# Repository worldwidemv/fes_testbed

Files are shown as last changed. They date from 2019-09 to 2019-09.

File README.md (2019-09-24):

# Testbed for Functional Electrical Stimulation (FES) Devices

## Abstract
The FES Testbed is a specialised data acquisition system for measurements of transcutaneous electrical stimulation setups. The galvanic isolated measurement system transfers the high-resolution data of every detected
stimulation pulse via USB to a PC or Laptop. The stimulation pulse can use one of the 3 included skin replacement
models or can be forwarded to standard electrodes, allowing to record a normal FES application. Modular
postprocessing MATLAB functions round up the FES Testbed. These functions handle the data conversion, pulse
detection, gathering of statistics, data management and data visualisation. A MATLAB GUI for efficient pulse
examination completes the FES Testbed.

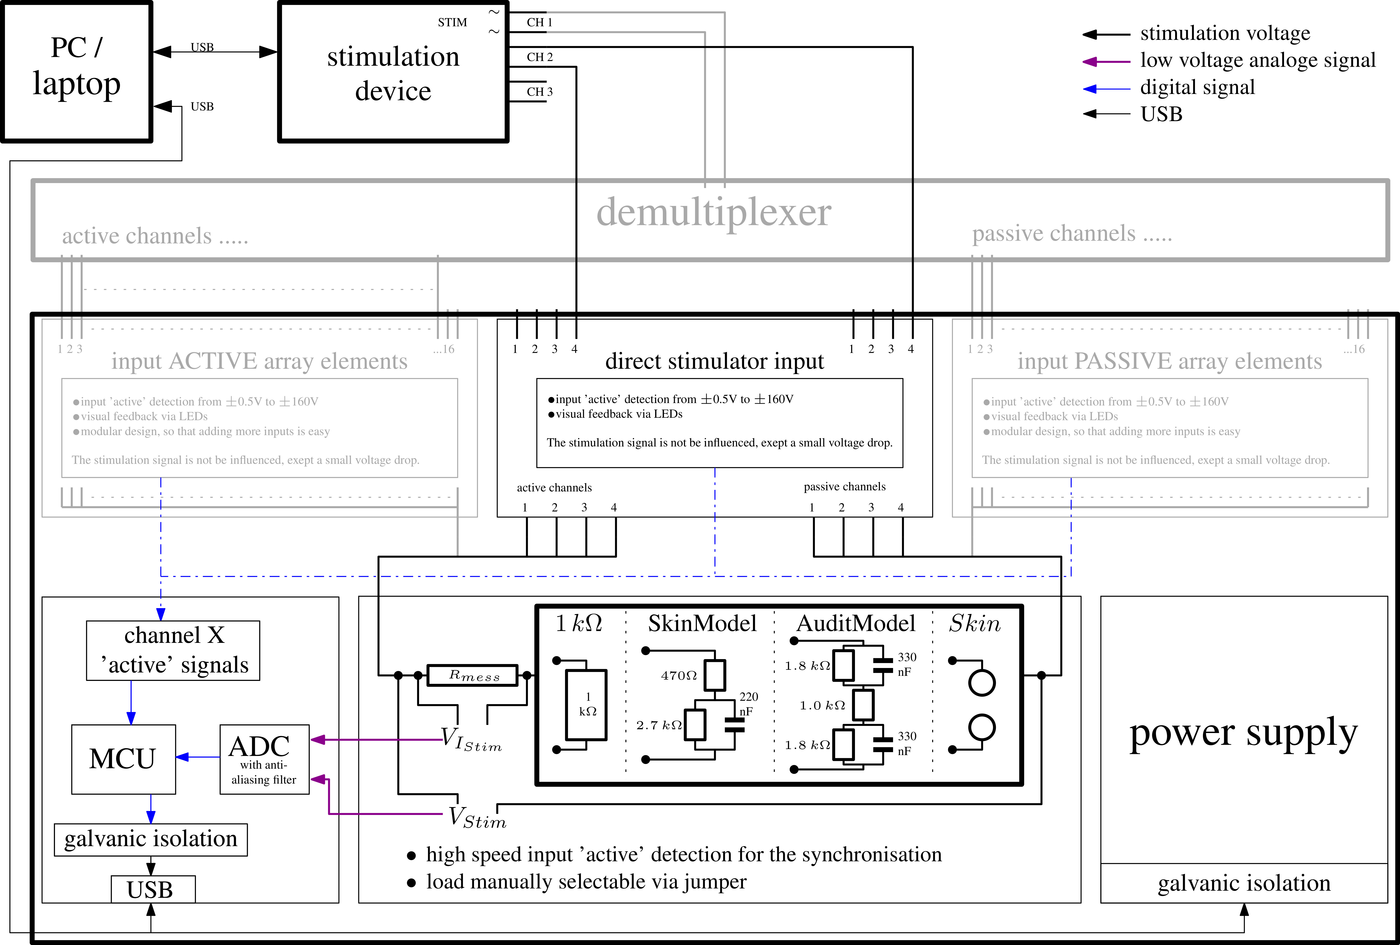
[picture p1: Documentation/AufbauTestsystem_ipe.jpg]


<p>
<a href="./Documentation/Vienna_FESWS_2019_FES_Testbed__Paper.pdf">More Information ...</a>
</p>

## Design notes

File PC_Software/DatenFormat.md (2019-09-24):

# Data Format of the Testbed Standalone Programm

## Version 2
* File Header -> 24 bytes
    * '%%TESTBED DATA\n' -> 14 bytes
    * header[14] = TESTBED_DATA_VERSION;
    * header[15] = TESTBED_DATA_TYPE_STIM_STRUCTS;
    * header[16] = 10; // new line
    * header[17] = (uint8_t)((sampleFrequency >>  0) & 0xFF);
    * header[18] = (uint8_t)((sampleFrequency >>  8) & 0xFF);
    * header[19] = (uint8_t)((sampleFrequency >> 16) & 0xFF);
    * header[20] = (uint8_t)((sampleFrequency >> 24) & 0xFF);

* STIM Puls Header
    * Start Bytes '###' -> 3 bytes
    * uint16_t numberOfSamples -> 2 bytes
    * uint8_t  pulseNotComplete -> 1 byte
    * uint8_t  dataWasOverriden -> 1 byte
    * uint8_t  activeStimChannels -> 1 Bytes; positive und negativ
    * uint8_t  activeDemuxChannels_positiv[16] -> 16 Bytes
    * uint8_t  activeDemuxChannels_negativ[16] -> 16 Bytes

* STIM Pulse Data
    * uint64_t sampleNumber -> 4*numberOfSamples Bytes
    * int16_t stimCurrent -> 2*numberOfSamples Bytes; 
    * int16_t stimVoltage -> 2*numberOfSamples Bytes;

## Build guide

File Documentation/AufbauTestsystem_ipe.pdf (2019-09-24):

# stimulation

device STIM | ∼ ∼
CH 1 Rmess VStim VIStim | 1 kΩ | SkinModel | AuditModel 1

kΩ

1.8 kΩ

1.8 kΩ

1.0 kΩ

330
nF

330
nF

220

nF 470Ω 2.7 kΩ

•input ’active’ detection from ±0.5V to ±160V
•visual feedback via LEDs
•modular design, so that adding more inputs is easy
The stimulation signal is not be influenced, exept a small voltage drop. 1 2 3 | ...16 input ACTIVE array elements | 1 2 3

# input PASSIVE array elements

•input ’active’ detection from ±0.5V to ±160V
•visual feedback via LEDs
The stimulation signal is not be influenced, exept a small voltage drop. 1 | 2 | 3
direct stimulator input active channels | passive channels 1 | 2 | 3 | 4 | 1 | 2 | 3 | 4

# - high speed input ’active’ detection for the synchronisation

- load manually selectable via jumper MCU | with anti-

# aliasing filter USB galvanic isolation

# channel X

’active’ signals | power supply demultiplexer CH 3 CH 2 active channels ..... | passive channels ..... PC / laptop | USB USB | 4 | 1 | 2 | 3 | 4

•input ’active’ detection from ±0.5V to ±160V •visual feedback via LEDs
•modular design, so that adding more inputs is easy
The stimulation signal is not be influenced, exept a small voltage drop. ...16 galvanic isolation MCU | ADC USB galvanic isolation

# channel X

’active’ signals | Skin

# stimulation voltage low voltage analoge signal digital signal USB

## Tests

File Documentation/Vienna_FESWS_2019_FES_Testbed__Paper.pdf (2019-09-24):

## FES Testbed for Multi-Channel Transcutaneous Stimulation Systems

Valtin M.¹
, Schauer T.

1

1Control Systems Group, Technische Universität Berlin, Germany

Abstract: Troubleshooting advanced FES applications or stimulation devices by measuring the stimulation current and voltage over several minutes is often not possible because of the limited memory available in standard oscilloscopes. The developed FES Testbed, a specialised data acquisition system for transcutaneous electrical stimulation, enables such measurements. The galvanic isolated measurement system transfers the high-resolution data of every detected stimulation pulse via USB to a PC or Laptop. The stimulation pulse can use one of the 3 included skin replacement models or can be forwarded to standard electrodes, allowing to record a normal FES application. Modular postprocessing MATLAB functions round up the FES Testbed. These functions handle the data conversion, pulse detection, gathering of statistics, data management and data visualisation. A MATLAB GUI for efficient pulse examination completes the FES Testbed.

Keywords: Stimulation Device, FES, Current Measurement, Data Acquisition, Skin Model

Introduction

Research involving functional transcutaneous electrical stimulation often includes some kind of control over the electrical stimulation. This may include the timing of the stimulation and/or the stimulation intensity, often based on sensor data [1]. Prominent examples of this structure are the FES based drop-foot correction [2] and the rehabilitation of the upper extremities, e.g. the hand [3]. In both cases, complex stimulation patterns are generated based on real-time sensor data. Monitoring and validating these stimulation patterns is often not easily possible, because the necessary measurement equipment is to large, to expensive, or to difficult to operate outside a lab environment.
Traditionally, the generated stimulation pulses are measured with an oscilloscope or with a data acquisition card for the PC. With a little bit of additional hardware, the stimulation voltage, as well as the stimulation current can be measured with these systems. Both methods usually use grid powered devices with no galvanic isolation, so the electrical safety of the whole setup must be kept in mind to protect the devices or the subject. While oscilloscope measurements are great for real-time feedback, they cannot be used for long term evaluation (e.g. several minutes) or tracking of randomly occurring stimulation errors, because of the limited amount of memory available.
PC based data acquisition systems do not have this limitation, however, these, often stationary systems, are generally less practical because of the costs, system size and complexity. Data acquisition systems also require elaborate postprocessing to go through the millions of samples to extract the short stimulation pulses and convert the integer raw-data samples into ampere/volt.

The presented FES Testbed is a specialised data acquisition system for transcutaneous electric stimulation, enabling researchers to check and validate the safety and functionality of their advanced FES applications.

The second application of the FES Testbed is the validation and comparison of different stimulators and support of the development of new stimulation devices. Since the various stimulators used in FES research all generate an electrical pulse, suitable to trigger a muscle contraction, the subtle and not so subtle differences, like symmetric and asymmetric biphasic pulses, are often neglected, conveying the idea that every stimulation pulse form is equally effective and can be easily exchanged. With the FES Testbed, the high-resolution voltage and current wave forms of multiple stimulation pulses can be recorded and compared. Additionally, multiple realistic loads included in the FES Testbed simulate the electrode-skin interface and allow comparing different stimulators under the exact same load conditions.

Material and Methods

The FES Testbed consists of three individual parts:
- a small data acquisition system, specialised for FES,
- a PC based data recorder program,
- and MATLAB (MathWorks Inc., USA) postprocessing scripts for efficient evaluation of the recorded stimulation pulses.
The FES data acquisition system is controlled by the PC data recorder, which saves the raw data for postprocessing by the MATLAB scripts.

FES Data Acquisition System

Figure 1 depicts the basic structure of the whole system, with the PC or Laptop controlling the FES data acquisition system and the stimulation device. An optional demultiplexer, as well as the modules for additional input channels, are shown in grey.

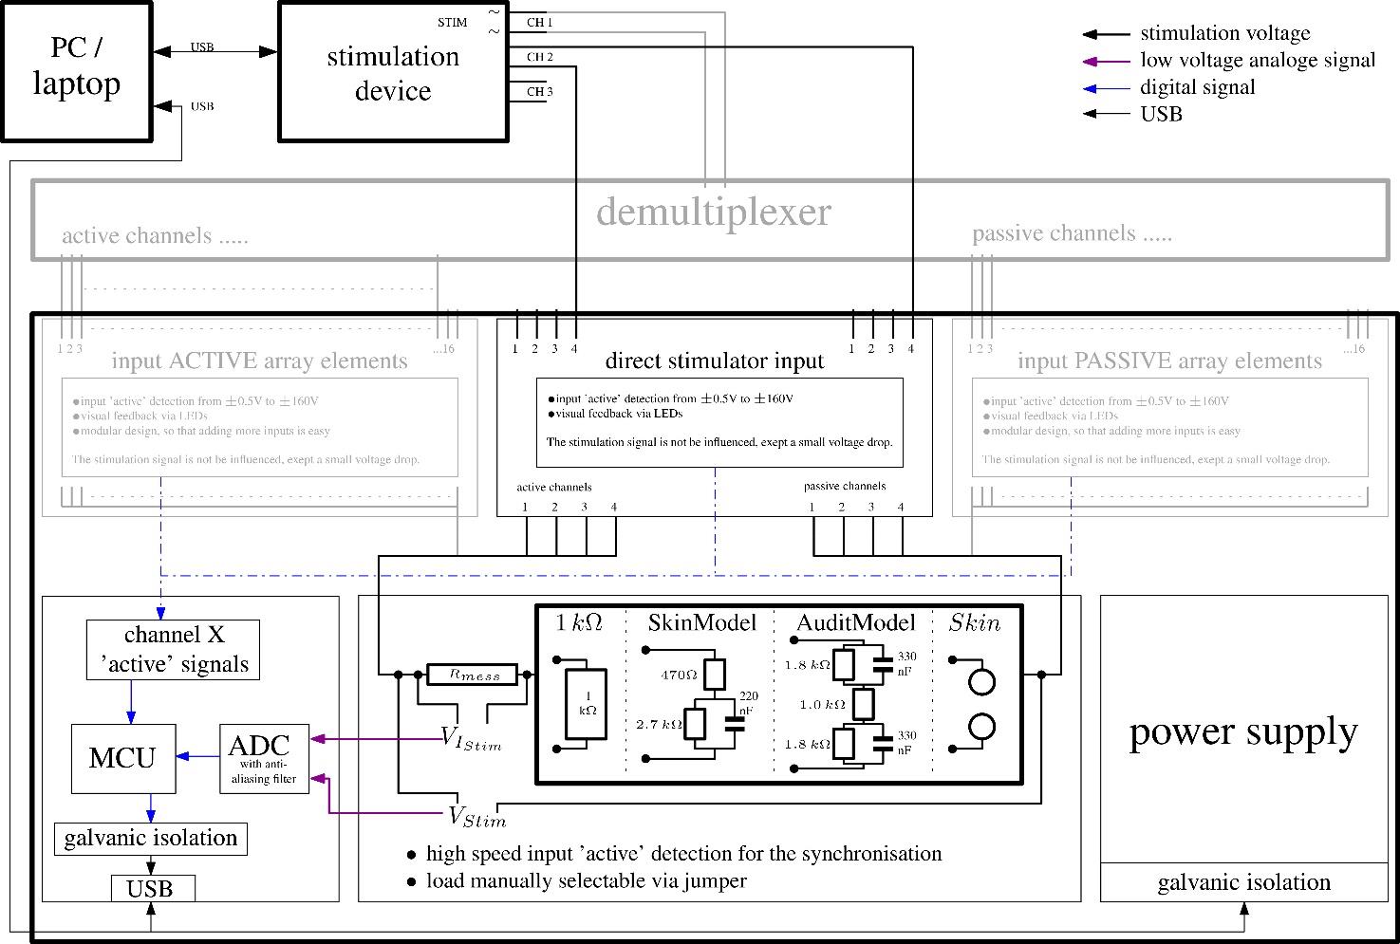
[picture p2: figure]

All devices are connected via USB to the PC, which also supplies the power for the data acquisition system. The power supply, as well as the USB communication channel, are galvanically isolated from the PC, to protect the PC from the high stimulation voltage and to protect against any ground loops, in case the FES Testbed is connected to a person. The power supply uses isolated DC/DC modules with at least 5.2kV isolation voltage (MEJ2 series, Murata, Japan). For the communication channel, the USB isolation IC ADUM4160BRWZ (Analog Devices Inc., USA) is used.
The FES Testbed supports 4 stimulation channels directly and up to 96 additional channels with optional extension modules, e.g. if a demultiplexer for electrode arrays needs to be tested. However, only one of these input channels can be active at a time. So, the stimulator must have a multiplexed current source, if this feature is used. The input stage is identical for every input channel and consists of a 'stimulation active' detection, which determines which stimulation channel is used. This is realised with an opto-coupler, which is driven directly by the stimulation current. An opto-coupler is used, because the stimulation current is not altered and because the resulting digital signal voltage is isolated from the stimulation voltage. Each input stage also has visual feedback of the stimulation pulse using LEDs.
After the input stage, all channels are connected to one single stimulation channel, which is routed to the current measurement resistor Rmess and the selected load.

Four via jumper selectable loads are included:
- a 1kΩ load for simple tests and comparison with oscilloscope measurements (1kΩ),
- a simplified linear skin model [4] (SkinModel),
- a model of the electrode interface according to test specification 09-01 03/2007 MDS-Hi (AuditModel),
- and a connector for standard stimulation cables (Skin). The voltage drop over the measurement resistor Rmess and the voltage over the load are measured with a two channel, 16-bit analogue to digital converter (ADC) MAX11198 (Maxim Integrated Inc., USA). The ADC’s sampling rate can go up to 2 MSample/s and is controlled via an external clock signal. The ADC features a dual serial peripheral interface (SPI), with one SPI output channel for each ADC channel and a maximum SPI clock frequency of 50MHz. However, it is not possible, to use two traditional SPIs, since only one SPI clock input is available. Therefore, one SPI interface was used in the master configuration to drive the SPI clock, accompanied by a second SPI interface in slave configuration, using the SPI clock generated by the SPI master. This allows the microcontroller (MCU) to utilise the direct memory access (DMA) unit for the data transfer, significantly reducing the MCU workload. The data transfer is triggered by the same MCU timer, which generates the ADC’s clock, guaranteeing a valid data transfer after the ADC’s data registers were updated.
The ADCs sampling rate was chosen to 1 MSample/s. This is because the stimulation pulse has a time resolution

Figure 1: Overview of the FES Testbed, including the structure of the data acquisition system.

of 1µs or greater. Passive first order anti-aliasing filters with ~500 kHz cut-off frequency are included in the signal preconditioning circuitry, before the ADC.
An | ARM© | based | microcontroller | (STM32L433,
STMicroelectronics, Netherlands) was used to receive the SPI data, as well as the USB data. Because of the embedded USB 2.0 module, supporting 12 MBit/s, no USB to serial converter is needed. Since the highest data rate supported by the USB isolator IC is USB 2.0 'Full Speed' with 12 MBit/s, no faster external USB solutions are viable. Because the data rate is limited, the MCU needs to pre-process the continuous ADC data stream to identify the stimulation pulses, so that only the parts containing stimulation pulses are sent to the PC. This is done via configurable thresholds for the measured stimulation current and voltage. The data is buffered using the MCU’s RAM and send out in packages of two times 1000 samples. A 32-bit sample counter is sent with every package to enable the PC program to reconstruct the correct time vector of the stimulation pulses.

Data Recorder Program

The FES data acquisition system is controlled from a Linux PC via the Data Recorder program. This program initiates the measurement, receives, and saves the data excerpt. The following parameters are set during initialisation of the FES data acquisition system: data type to send (only the stimulation pulses or a continuous down-sampled data stream), sample rate divider, search width (number of samples to skip if detecting a stimulation pulse), detection thresholds, and if a demultiplexer is used. This initial setup is also stored in the custom binary format, used to store the measurement data. This allows the postprocessing script the correct conversion of the raw data stored. The data format is optimised for read-in speed and size, so only the time as a float value, and the raw 16-bit integer values for current and voltage are stored as vectors for one pulse. Therefore, before each pulse section, a small header is added with the meta information about the pulse, like the number of samples, the active stimulation channel(s), and so on. Figure 2 depicts the general structure of the resulting data file.

Figure 2: File structure of the custom binary data file.

The data about each stimulation pulse is also available via TCP/IP connection, to allow real-time visualisation and monitoring by other programs or scripts.

MATLAB based Postprocessing

Since the PC program only saves the raw data, the bulk of the conversion and postprocessing is done by modular MATLAB functions. A first function reads the binary file and converts the 16-bit raw data into volt and milliampere. The function also creates a MATLAB structure (struct) for the data, with an array of structs containing the stimulation pulse data. The meta data for each pulse is also taken over from the raw data and reformatted for easy access in MATLAB. A second function is used to search for the expected pulse form, e.g. symmetric bi-phasic, and aligns the found pulse data, so that the pulses can be automatically compared and analysed. This function also collects various stats like the current or pulse width for later use. This step also saves all pulses which do not follow the expected form, so that they can be inspected manually later. Custom functions which, e.g., identify skin-model parameters can now be used on these normalised datasets.
Plotting these datasets is also very easy. A custom MATLAB GUI was developed to efficiently view the results and compare various stimulation pulses. This GUI has an overview function, where the complete, down-sampled vector of the stimulation current is plotted over time in subplot 1. One stimulation pulse, highlighted in the overview plot, can be selected via slider and shown in subplot 2. If the overview is disabled, subplot 1 is going to display the stimulation current of N pulses, while subplot 2 is going to display the stimulation voltage for these N pulses. N, the number of pulses to display, is configurable in the GUI and includes the selected pulse as well as the previous N-1 pulses.
The MATLAB data structure containing all this information can be saved directly from the GUI with varying degree of raw data included, significantly reducing the needed file size.

Results

The FES data acquisition device with an extension module for additional 16 input channels is depicted in Figure 3.

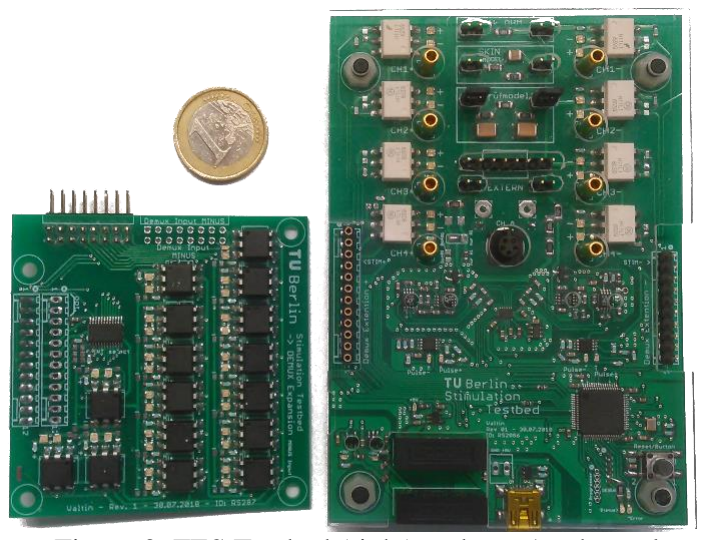
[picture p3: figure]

Figure 3: FES Testbed (right) and one 16 channel extension module (left).

The small size (115 mm × 80 mm × 20 mm) and the single USB connection makes the device very portable and easy to operate.
The quality of the measured data is also very good for such a simple system. The time resolution of 1 µs is sufficient to capture even very short spikes and sharp transients. The 16-bit ADC resolution provides a theoretical resolution for the stimulation current of ~5 µA and enables low noise measurements from 0 mA up to ±150 mA without the need to adjust the measurement range. Figure 4 shows the stimulation voltage of a stimulator with adaptive high voltage generation [5] over the AuditModel, measured with the FES Testbed and with a 10-bit oscilloscope (Rode&Schwarz, RTM3004).

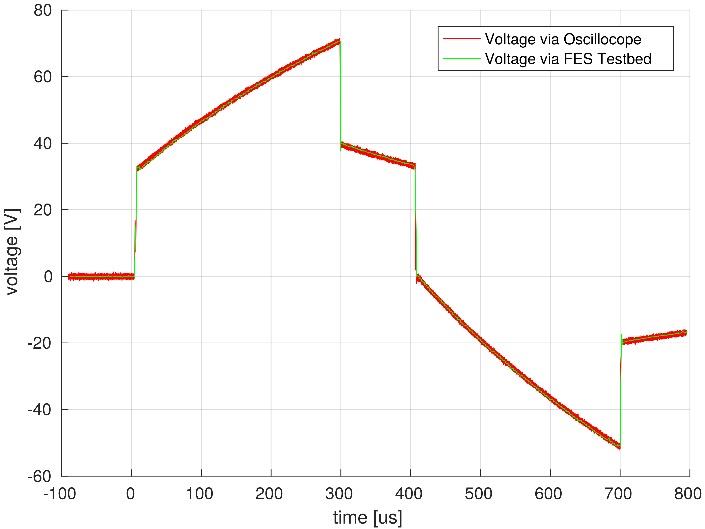
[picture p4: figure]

Figure 4: Stimulation voltage over the electrode interface model, measured with the FES Testbed (green) and an oscilloscope (red) (cur=25 mA; pw=300 µs).

Figure 5 shows the MATLAB GUI for a data set of 60 seconds or 1200 pulses (cur=25 mA; pw=300 µs) with 50 ms between each pulse. In the lower part of the GUI, stimulation current (blue) and voltage (orange) is displayed as well as the automatically detected boundaries of the different parts of the pulse (red). The file size of this one-minute long data set is about 34.9 MB. The postprocessing is also very fast, taking less than one second for the 1-minute data set, which would make the postprocessing real-time capable.

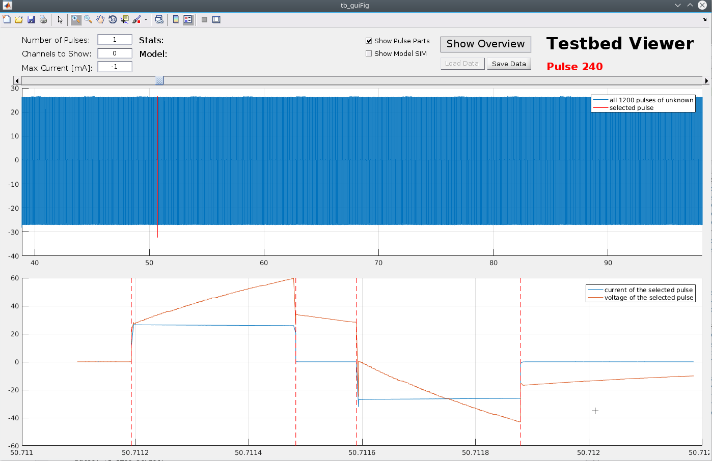
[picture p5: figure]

Figure 5: FES Testbed GUI showing the overview with 1200 pulses and the details for pulse 240.

The only limitation of the FES data acquisition system is its inability to continuously stream the data with 1 MSample/s. However, the need for galvanic isolation requires this compromise. On the other hand, most of this data would be discarded anyway, since the relevant stimulation pulse is very short, compared to the stimulation period. The MCUs buffer capability of 2 ms (sampling rate 1 MSample/s) should be sufficient for most applications, even where multiple pulses are used. In all other cases, reducing the sample rate will increase the pulse length the buffer can hold accordingly.

Conclusions

We developed a testbed aimed at supporting developers of intelligent stimulators, researcher who study electrical stimulation and its effects on the body, and clinicians who want to check and monitor the stimulation pulses generated by their FES application, over the entire treatment session.
The FES Testbed gives new insight into the physical effects of electrical stimulation and may aid in the development of smarter stimulators, which e.g., warn the health care professional if the stimulation voltage saturates because of poor electrode-skin contact. The FES Testbed could also prove invaluable for the validation and accreditation of complex stimulation systems.
Future work will focus on the automatic parameter identification for various skin models [6] [7] and the change of these parameters over stimulation intensity and time.

References

[1] T. Schauer: Sensing motion and muscle activity for feedback control of functional electrical stimulation: Ten years of experience in Berlin, Annual Reviews in Control, vol. 44, pp. 355-374, 2017
[2] T. Seel, C. Werner, T. Schauer: The Adaptive Drop Foot Stimulator – Multivariable Learning Control of Foot Pitch and Roll Motion in Paretic Gait, Medical Engineering Physics, vol. 38, pp. 1205-1213, 2016
[3] C. Salchow-Hömmen, T. Thomas et. al.: Automatic control of grasping strength for functional electrical stimulation in forearm movements via electrode arrays, at-Autom, vol. 66, pp. 1027-1036, 2018
[4] A. Boxtel: Skin resistance during square-wave electrical pulses of 1 to 10 mA, Medical & biological engineering & computing, vol. 15, pp. 679-687, 1977
[5] C. Wiesener: Current-Controlled Stimulator with Variable High Voltage Generation, Submitted to Proc. of the 13th Vienna International Workshop on Functional Electrical Stimulation, 2019
[6] J. L. Vargas Luna et. al.: Dynamic impedance model of the skin-electrode interface for transcutaneous electrical stimulation, PloS one, 2015 10(5), e0125609
[7] S. Dorgan, R. Reilly: Model for human skin impedance during surface functional neuromuscular stimulation, IEEE transactions on rehabilitation engineering, vol. 7, pp. 341-348, 1999

Author’s Address

Markus Valtin
Technische Universität Berlin Sekretariat EN 11
Einsteinufer 17
D-10587 Berlin, Germany
markus.valtin@campus.tu-berlin.de http://www.control.tu-berlin.de

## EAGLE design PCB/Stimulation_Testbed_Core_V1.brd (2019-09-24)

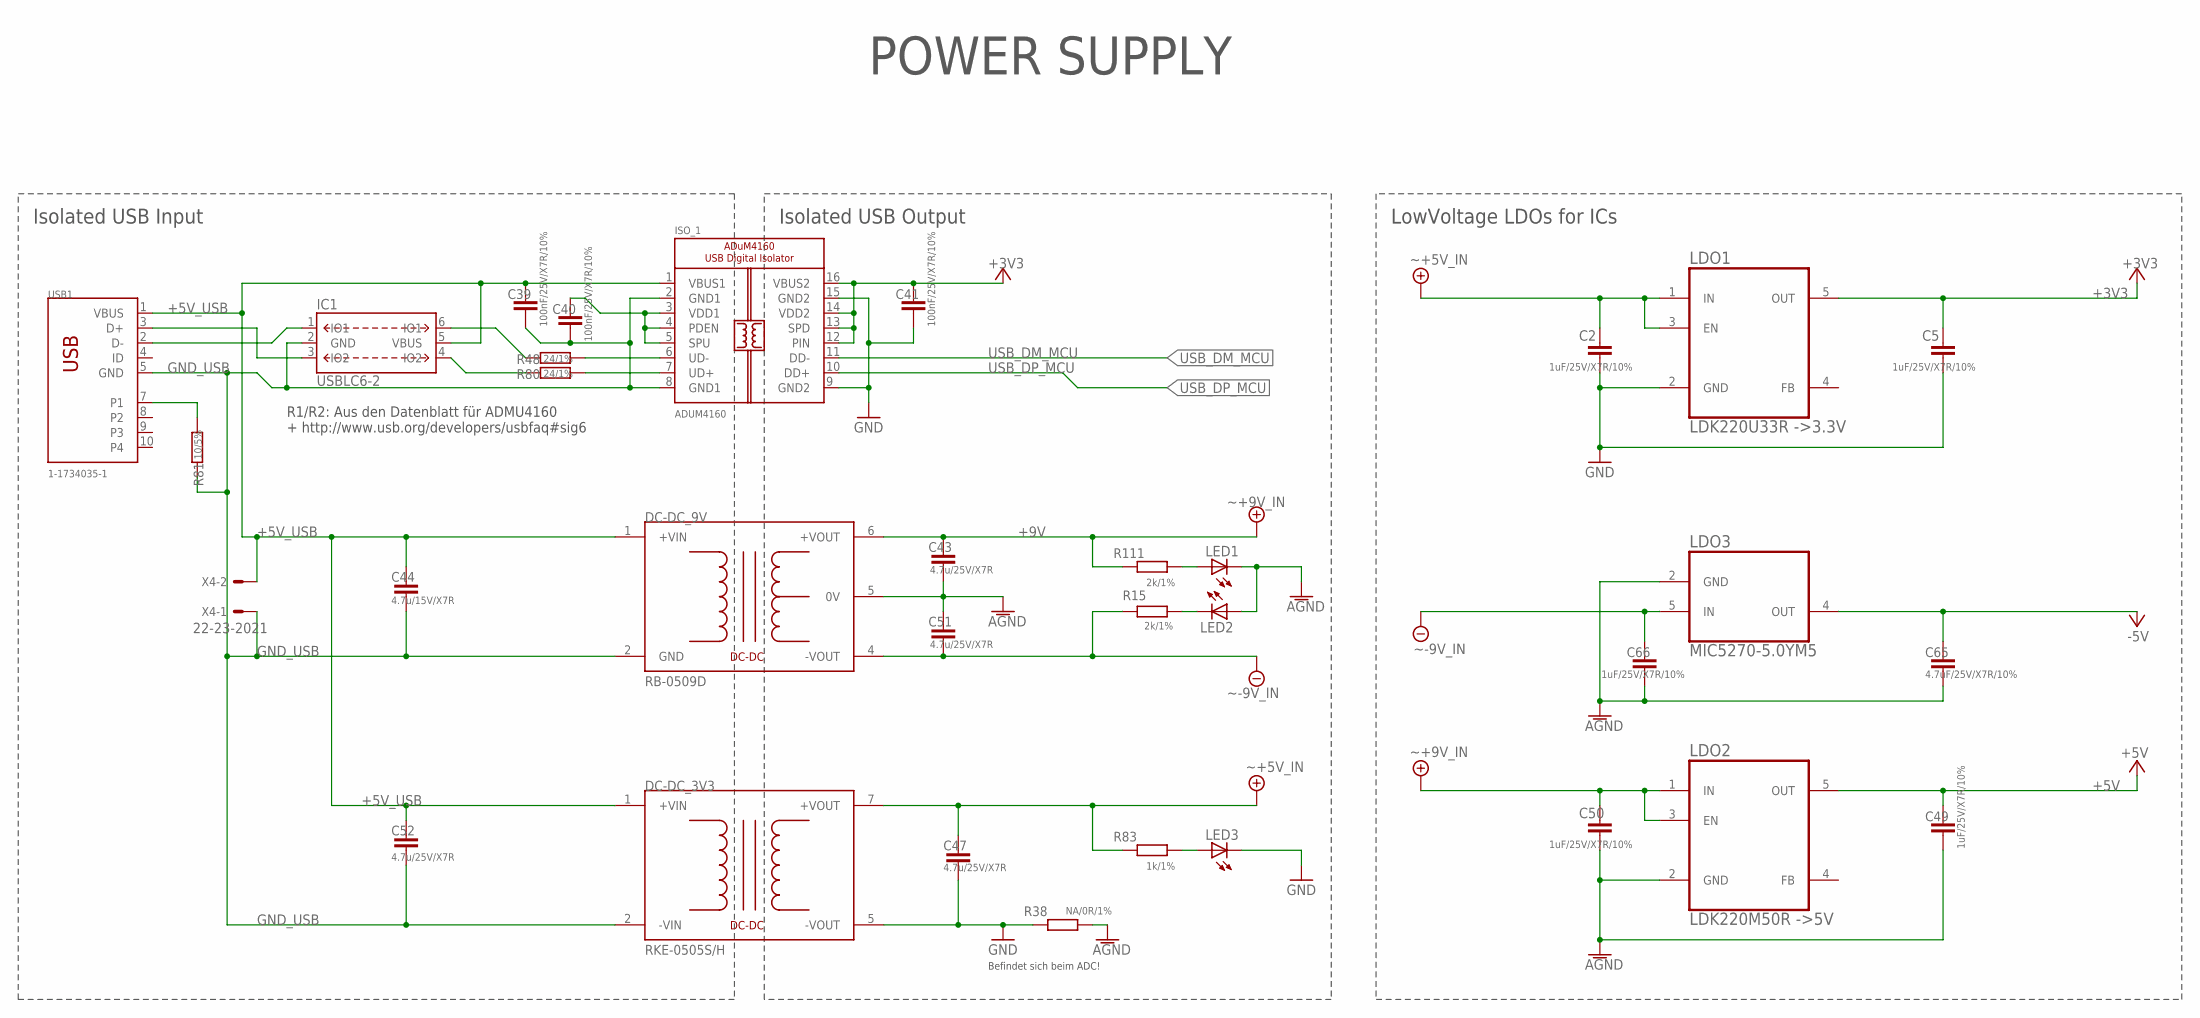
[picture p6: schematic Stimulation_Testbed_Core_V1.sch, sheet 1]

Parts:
C2, C5, C49, C50, C66: 1uF/25V/X7R/10%; C0603K
C39, C40, C41: 100nF/25V/X7R/10%; C0603K
C43, C47, C51, C52: 4.7u/25V/X7R; C0603
C44: 4.7u/15V/X7R; C0603
C65: 4.7uF/25V/X7R/10%; C0603K
DC-DC_3V3: RKE-0505S/H; MEJ2
DC-DC_9V: RB-0509D; NMH
IC1: USBLC6-2; SOT-23-6
ISO_1: ADUM4160; SOIC16WIDE
LDO1: LDK220U33R ->3.3V; SOT-23-5
LDO2: LDK220M50R ->5V; SOT-23-5
LDO3: MIC5270-5.0YM5; SOT-23-5
LED1, LED2, LED3: LEDCHIPLED_0603; CHIPLED_0603
R15, R111: 2k/1%; R0603
R38: NA/0R/1%; R0603
R48, R80: 24/1%; R0603
R81: 10/5%; R0603
R83: 1k/1%; R0603
USB1: 1-1734035-1; TE_1-1734035-1
X4: 22-23-2021

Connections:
+3V3: C5.1, C41.1, ISO_1.12 (PIN), ISO_1.13 (SPD), ISO_1.14 (VDD2), ISO_1.16 (VBUS2), LDO1.5 (OUT); also elsewhere on the board
+5V: C49.1, LDO2.5 (OUT); also elsewhere on the board
+5V_IN: C2.1, C47.1, DC-DC_3V3.7 (+VOUT), LDO1.1 (IN), LDO1.3 (EN), R83.1
+5V_USB: C39.1, C44.1, C52.1, DC-DC_3V3.1 (+VIN), DC-DC_9V.1 (+VIN), IC1.5 (VBUS), ISO_1.1 (VBUS1), USB1.1 (VBUS), X4.2
+9V: C43.1, C50.1, DC-DC_9V.6 (+VOUT), LDO2.1 (IN), LDO2.3 (EN), R111.1
-5V: C65.1, LDO3.4 (OUT); also elsewhere on the board
-9V: C51.2, C66.1, DC-DC_9V.4 (-VOUT), LDO3.5 (IN), R15.2
AGND: C43.2, C49.2, C50.2, C51.1, C65.2, C66.2, DC-DC_9V.5 (0V), LDO2.2 (GND), LDO3.2 (GND), LED1.C, LED2.A, R38.2; also elsewhere on the board
GND: C2.2, C5.2, C41.2, C47.2, DC-DC_3V3.5 (-VOUT), ISO_1.9 (GND2), ISO_1.15 (GND2), LDO1.2 (GND), LED3.C, R38.1; also elsewhere on the board
GND_USB: C39.2, C40.2, C44.2, C52.2, DC-DC_3V3.2 (-VIN), DC-DC_9V.2 (GND), IC1.2 (GND), ISO_1.2 (GND1), ISO_1.8 (GND1), R81.1, USB1.5 (GND), X4.1
unnamed: IC1.6 (IO1), R48.1
unnamed: C40.1, ISO_1.3 (VDD1), ISO_1.4 (PDEN), ISO_1.5 (SPU)
unnamed: ISO_1.6 (UD-), R48.2
unnamed: ISO_1.7 (UD+), R80.2
unnamed: R81.2, USB1.7 (P1)
unnamed: LED2.C, R15.1
unnamed: LED3.A, R83.2
unnamed: LED1.A, R111.2
unnamed: IC1.3 (IO2), USB1.3 (D+)
unnamed: IC1.1 (IO1), USB1.2 (D-)
unnamed: IC1.4 (IO2), R80.1
USB_DM_MCU: ISO_1.11 (DD-); also elsewhere on the board
USB_DP_MCU: ISO_1.10 (DD+); also elsewhere on the board

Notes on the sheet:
R1/R2: Aus den Datenblatt für ADMU4160 + http://www.usb.org/developers/usbfaq#sig6
Isolated USB Input
LowVoltage LDOs for ICs
Isolated USB Output
POWER SUPPLY
Befindet sich beim ADC!

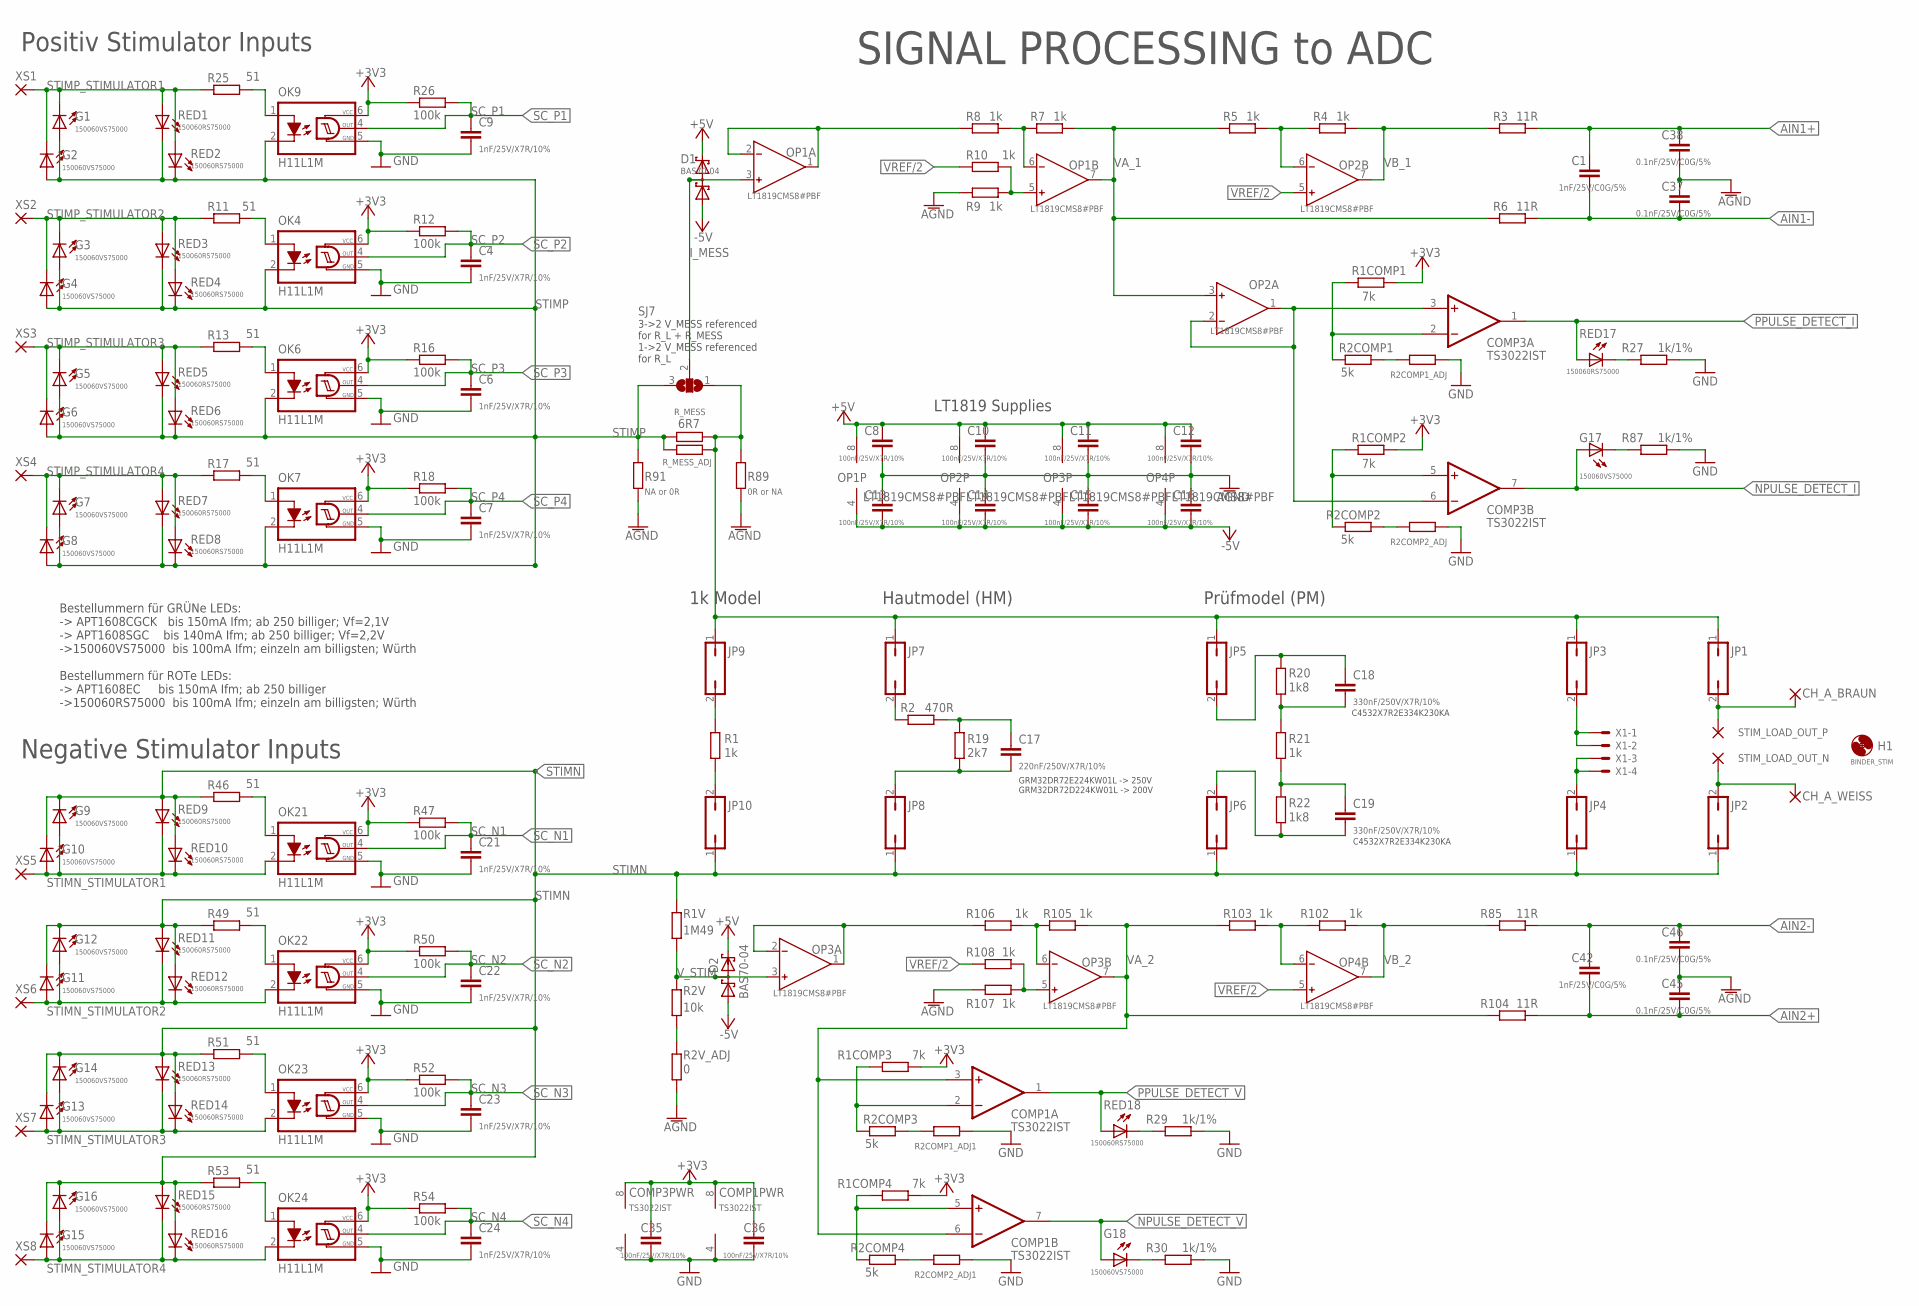
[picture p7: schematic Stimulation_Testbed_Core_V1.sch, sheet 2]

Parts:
C1, C42: 1nF/25V/C0G/5%; C0603K
C4, C6, C7, C9, C21, C22, C23, C24: 1nF/25V/X7R/10%; C0603
C8, C10, C11, C12, C13, C14, C15, C16, C35, C36: 100nF/25V/X7R/10%; C0603K
C17: 220nF/250V/X7R/10%; C1210
C18, C19: 330nF/250V/X7R/10%; C1812
C37, C38, C45, C46: 0.1nF/25V/C0G/5%; C0603K
CH_A_BRAUN: 1,6/0,8
CH_A_WEISS: 1,6/0,8
COMP1, COMP3: TS3022IST; MSOP8
D1, D2: BAS70-04; SOT23
G1, G2, G3, G4, G5, G6, G7, G8, G9, G10, G11, G12, G13, G14, G15, G16, G17, G18: 150060VS75000; CHIPLED_0603
H1: BINDER_STIM; 5,5-PAD
JP1, JP2, JP3, JP4, JP5, JP6, JP7, JP8, JP9, JP10: JP1Q; JP1
OK4, OK6, OK7, OK9, OK21, OK22, OK23, OK24: H11L1M; DIL06
OP1, OP2, OP3, OP4: LT1819CMS8#PBF; MSOP8
R1, R21: 1k; R1206
R1COMP1, R1COMP2, R1COMP3, R1COMP4: 7k; R0603
R1V: 1M49; R1206
R2: 470R; R1206
R2COMP1, R2COMP2, R2COMP3, R2COMP4: 5k; R0603
R2COMP1_ADJ, R2COMP1_ADJ1: R-EU_R0603; R0603
R2COMP2_ADJ, R2COMP2_ADJ1, R4, R5, R7, R8, R9, R10, R102, R103, R105, R106, R107, R108: 1k; R0603
R2V: 10k; R1206
R2V_ADJ: 0; R1206
R3, R6, R85, R104: 11R; R0603
R11, R13, R17, R25, R46, R49, R51, R53: 51; R0603
R12, R16, R18, R26, R47, R50, R52, R54: 100k; R0603
R19: 2k7; R1206
R20, R22: 1k8; R1206
R27, R29, R30, R87: 1k/1%; R0603
R89: 0R or NA; R0603
R91: NA or 0R; R0603
RED1, RED2, RED3, RED4, RED5, RED6, RED7, RED8, RED9, RED10, RED11, RED12, RED13, RED14, RED15, RED16, RED17, RED18: 150060RS75000; CHIP-LED0603
R_MESS: 6R7; R1206
R_MESS_ADJ: R-EU_R1206; R1206
SJ7: SJ2W; SJ_2
STIM_LOAD_OUT_N: 3,81/1,4
STIM_LOAD_OUT_P: 3,81/1,4
X1: 22-23-2041
XS1, XS2, XS3, XS4, XS5, XS6, XS7, XS8: WIREPAD3,81/1,4; 3,81/1,4

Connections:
2XVREF: OP3.1 (OUT), OP3.2 (IN-), R106.2
2XVREF1: OP1.1 (OUT), OP1.2 (IN-), R8.2
+3V3: C35.1, C36.1, COMP1.8 (V+), COMP3.8 (V+), OK4.6 (VCC), OK6.6 (VCC), OK7.6 (VCC), OK9.6 (VCC), OK21.6 (VCC), OK22.6 (VCC), OK23.6 (VCC), OK24.6 (VCC), R1COMP1.1, R1COMP2.1, R1COMP3.1, R1COMP4.1, R12.1, R16.1, R18.1, R26.1, R47.1, R50.1, R52.1, R54.1; also elsewhere on the board
+5V: C8.1, C10.1, C11.1, C12.1, D1.2 (C2), D2.2 (C2), OP1.8 (V+), OP2.8 (V+), OP3.8 (V+), OP4.8 (V+); also elsewhere on the board
-5V: C13.2, C14.2, C15.2, C16.2, D1.1 (A1), D2.1 (A1), OP1.4 (V-), OP2.4 (V-), OP3.4 (V-), OP4.4 (V-); also elsewhere on the board
AGND: C8.2, C10.2, C11.2, C12.2, C13.1, C14.1, C15.1, C16.1, C37.2, C38.1, C45.2, C46.1, R2V_ADJ.2, R9.2, R89.2, R91.2, R107.2; also elsewhere on the board
AIN1+: C1.2, C38.2, R3.1; also elsewhere on the board
AIN1-: C1.1, C37.1, R6.2; also elsewhere on the board
AIN2+: C42.1, C45.1, R104.2; also elsewhere on the board
AIN2-: C42.2, C46.2, R85.1; also elsewhere on the board
GND: C4.2, C6.2, C7.2, C9.2, C21.2, C22.2, C23.2, C24.2, C35.2, C36.2, COMP1.4 (V-), COMP3.4 (V-), OK4.5 (GND), OK6.5 (GND), OK7.5 (GND), OK9.5 (GND), OK21.5 (GND), OK22.5 (GND), OK23.5 (GND), OK24.5 (GND), R2COMP1_ADJ.1, R2COMP1_ADJ1.1, R2COMP2_ADJ.1, R2COMP2_ADJ1.1, R27.1, R29.1, R30.1, R87.1; also elsewhere on the board
I_MESS: D1.3 (C1A2), OP1.3 (IN+), SJ7.2
unnamed: OK4.1 (A), R11.1
unnamed: R2COMP2.2, R2COMP2_ADJ.2
unnamed: R29.2, RED18.C
unnamed: G18.C, R30.2
unnamed: COMP1.2 (-IN), R1COMP3.2, R2COMP3.1
unnamed: COMP1.5 (+IN), R1COMP4.2, R2COMP4.1
unnamed: G17.C, R87.2
unnamed: OP1.5 (IN+), R9.1, R10.1
unnamed: R2COMP1_ADJ1.2, R2COMP3.2
unnamed: R2COMP2_ADJ1.2, R2COMP4.2
unnamed: OK6.1 (A), R13.1
unnamed: OK7.1 (A), R17.1
unnamed: OK9.1 (A), R25.1
unnamed: OP1.6 (IN-), R7.2, R8.1
unnamed: OP2.6 (IN-), R4.2, R5.1
unnamed: COMP3.3 (+IN), COMP3.6 (-IN), OP2.1 (OUT), OP2.2 (IN-)
unnamed: OK21.1 (A), R46.1
unnamed: COMP3.2 (-IN), R1COMP1.2, R2COMP1.1
unnamed: CH_A_WEISS.1, JP2.2, STIM_LOAD_OUT_N.1
unnamed: OK22.1 (A), R49.1
unnamed: OK23.1 (A), R51.1
unnamed: OK24.1 (A), R53.1
unnamed: R2V.1, R2V_ADJ.1
unnamed: OP3.5 (IN+), R107.1, R108.1
unnamed: CH_A_BRAUN.1, JP1.2, STIM_LOAD_OUT_P.1
unnamed: JP3.2, X1.1, X1.2
unnamed: JP9.2, R1.1
unnamed: JP4.2, X1.3, X1.4
unnamed: JP10.2, R1.2
unnamed: JP7.2, R2.2
unnamed: OP3.6 (IN-), R105.2, R106.1
unnamed: C17.1, JP8.2, R19.2
unnamed: C19.2, R21.2, R22.1
unnamed: C19.1, JP6.2, R22.2
unnamed: C18.2, JP5.2, R20.1
unnamed: C18.1, R20.2, R21.1
unnamed: OP4.6 (IN-), R102.2, R103.1
unnamed: C17.2, R2.1, R19.1
unnamed: R27.2, RED17.C
unnamed: COMP3.5 (+IN), R1COMP2.2, R2COMP2.1
unnamed: R2COMP1.2, R2COMP1_ADJ.2
NPULSE_DETECT_I: COMP3.7 (OUT), G17.A; also elsewhere on the board
NPULSE_DETECT_V: COMP1.7 (OUT), G18.A; also elsewhere on the board
PPULSE_DETECT_I: COMP3.1 (OUT), RED17.A; also elsewhere on the board
PPULSE_DETECT_V: COMP1.1 (OUT), RED18.A; also elsewhere on the board
SC_N1: C21.1, OK21.4 (OUT), R47.2; also elsewhere on the board
SC_N2: C22.1, OK22.4 (OUT), R50.2; also elsewhere on the board
SC_N3: C23.1, OK23.4 (OUT), R52.2; also elsewhere on the board
SC_N4: C24.1, OK24.4 (OUT), R54.2; also elsewhere on the board
SC_P1: C9.1, OK9.4 (OUT), R26.2; also elsewhere on the board
SC_P2: C4.1, OK4.4 (OUT), R12.2; also elsewhere on the board
SC_P3: C6.1, OK6.4 (OUT), R16.2; also elsewhere on the board
SC_P4: C7.1, OK7.4 (OUT), R18.2; also elsewhere on the board
STIMN: G9.C, G10.C, G11.C, G12.C, G13.C, G14.C, G15.C, G16.C, JP2.1, JP4.1, JP6.1, JP8.1, JP10.1, R1V.2, R46.2, R49.2, R51.2, R53.2, RED9.A, RED10.A, RED11.A, RED12.A, RED13.A, RED14.A, RED15.A, RED16.A; also elsewhere on the board
STIMN_STIMULATOR1: G9.A, G10.A, OK21.2 (C), RED9.C, RED10.C, XS5.1
STIMN_STIMULATOR2: G11.A, G12.A, OK22.2 (C), RED11.C, RED12.C, XS6.1
STIMN_STIMULATOR3: G13.A, G14.A, OK23.2 (C), RED13.C, RED14.C, XS7.1
STIMN_STIMULATOR4: G15.A, G16.A, OK24.2 (C), RED15.C, RED16.C, XS8.1
STIMP: G1.A, G2.A, G3.A, G4.A, G5.A, G6.A, G7.A, G8.A, OK4.2 (C), OK6.2 (C), OK7.2 (C), OK9.2 (C), R91.1, RED1.C, RED2.C, RED3.C, RED4.C, RED5.C, RED6.C, RED7.C, RED8.C, R_MESS.2, R_MESS_ADJ.1, SJ7.3; also elsewhere on the board
STIMP_MODEL: JP1.1, JP3.1, JP5.1, JP7.1, JP9.1, R89.1, R_MESS.1, R_MESS_ADJ.2, SJ7.1
STIMP_STIMULATOR1: G1.C, G2.C, R25.2, RED1.A, RED2.A, XS1.1
STIMP_STIMULATOR2: G3.C, G4.C, R11.2, RED3.A, RED4.A, XS2.1
STIMP_STIMULATOR3: G5.C, G6.C, R13.2, RED5.A, RED6.A, XS3.1
STIMP_STIMULATOR4: G7.C, G8.C, R17.2, RED7.A, RED8.A, XS4.1
VA_1: OP1.7 (OUT), OP2.3 (IN+), R5.2, R6.1, R7.1
VA_2: COMP1.3 (+IN), COMP1.6 (-IN), OP3.7 (OUT), R103.2, R104.1, R105.1
VB_1: OP2.7 (OUT), R3.2, R4.1
VB_2: OP4.7 (OUT), R85.2, R102.1
VREF/2: OP2.5 (IN+), OP4.5 (IN+), R10.2, R108.2; also elsewhere on the board
V_STIM: D2.3 (C1A2), OP3.3 (IN+), R1V.1, R2V.2

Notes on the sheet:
LT1819 Supplies
1k Model
Hautmodel (HM)
Prüfmodel (PM)
SIGNAL PROCESSING to ADC
3->2 V_MESS referenced for R_L + R_MESS 1->2 V_MESS referenced for R_L
Positiv Stimulator Inputs
Negative Stimulator Inputs
C4532X7R2E334K230KA
GRM32DR72E224KW01L -> 250V GRM32DR72D224KW01L -> 200V
Bestellummern für GRÜNe LEDs: -> APT1608CGCK bis 150mA Ifm; ab 250 billiger; Vf=2,1V -> APT1608SGC bis 140mA Ifm; ab 250 billiger; Vf=2,2V ->150060VS75000 bis 100mA Ifm; einzeln am billigsten; Würth Bestellummern für ROTe LEDs: -> APT1608EC bis 150mA Ifm; ab 250 billiger ->150060RS75000 bis 100mA I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

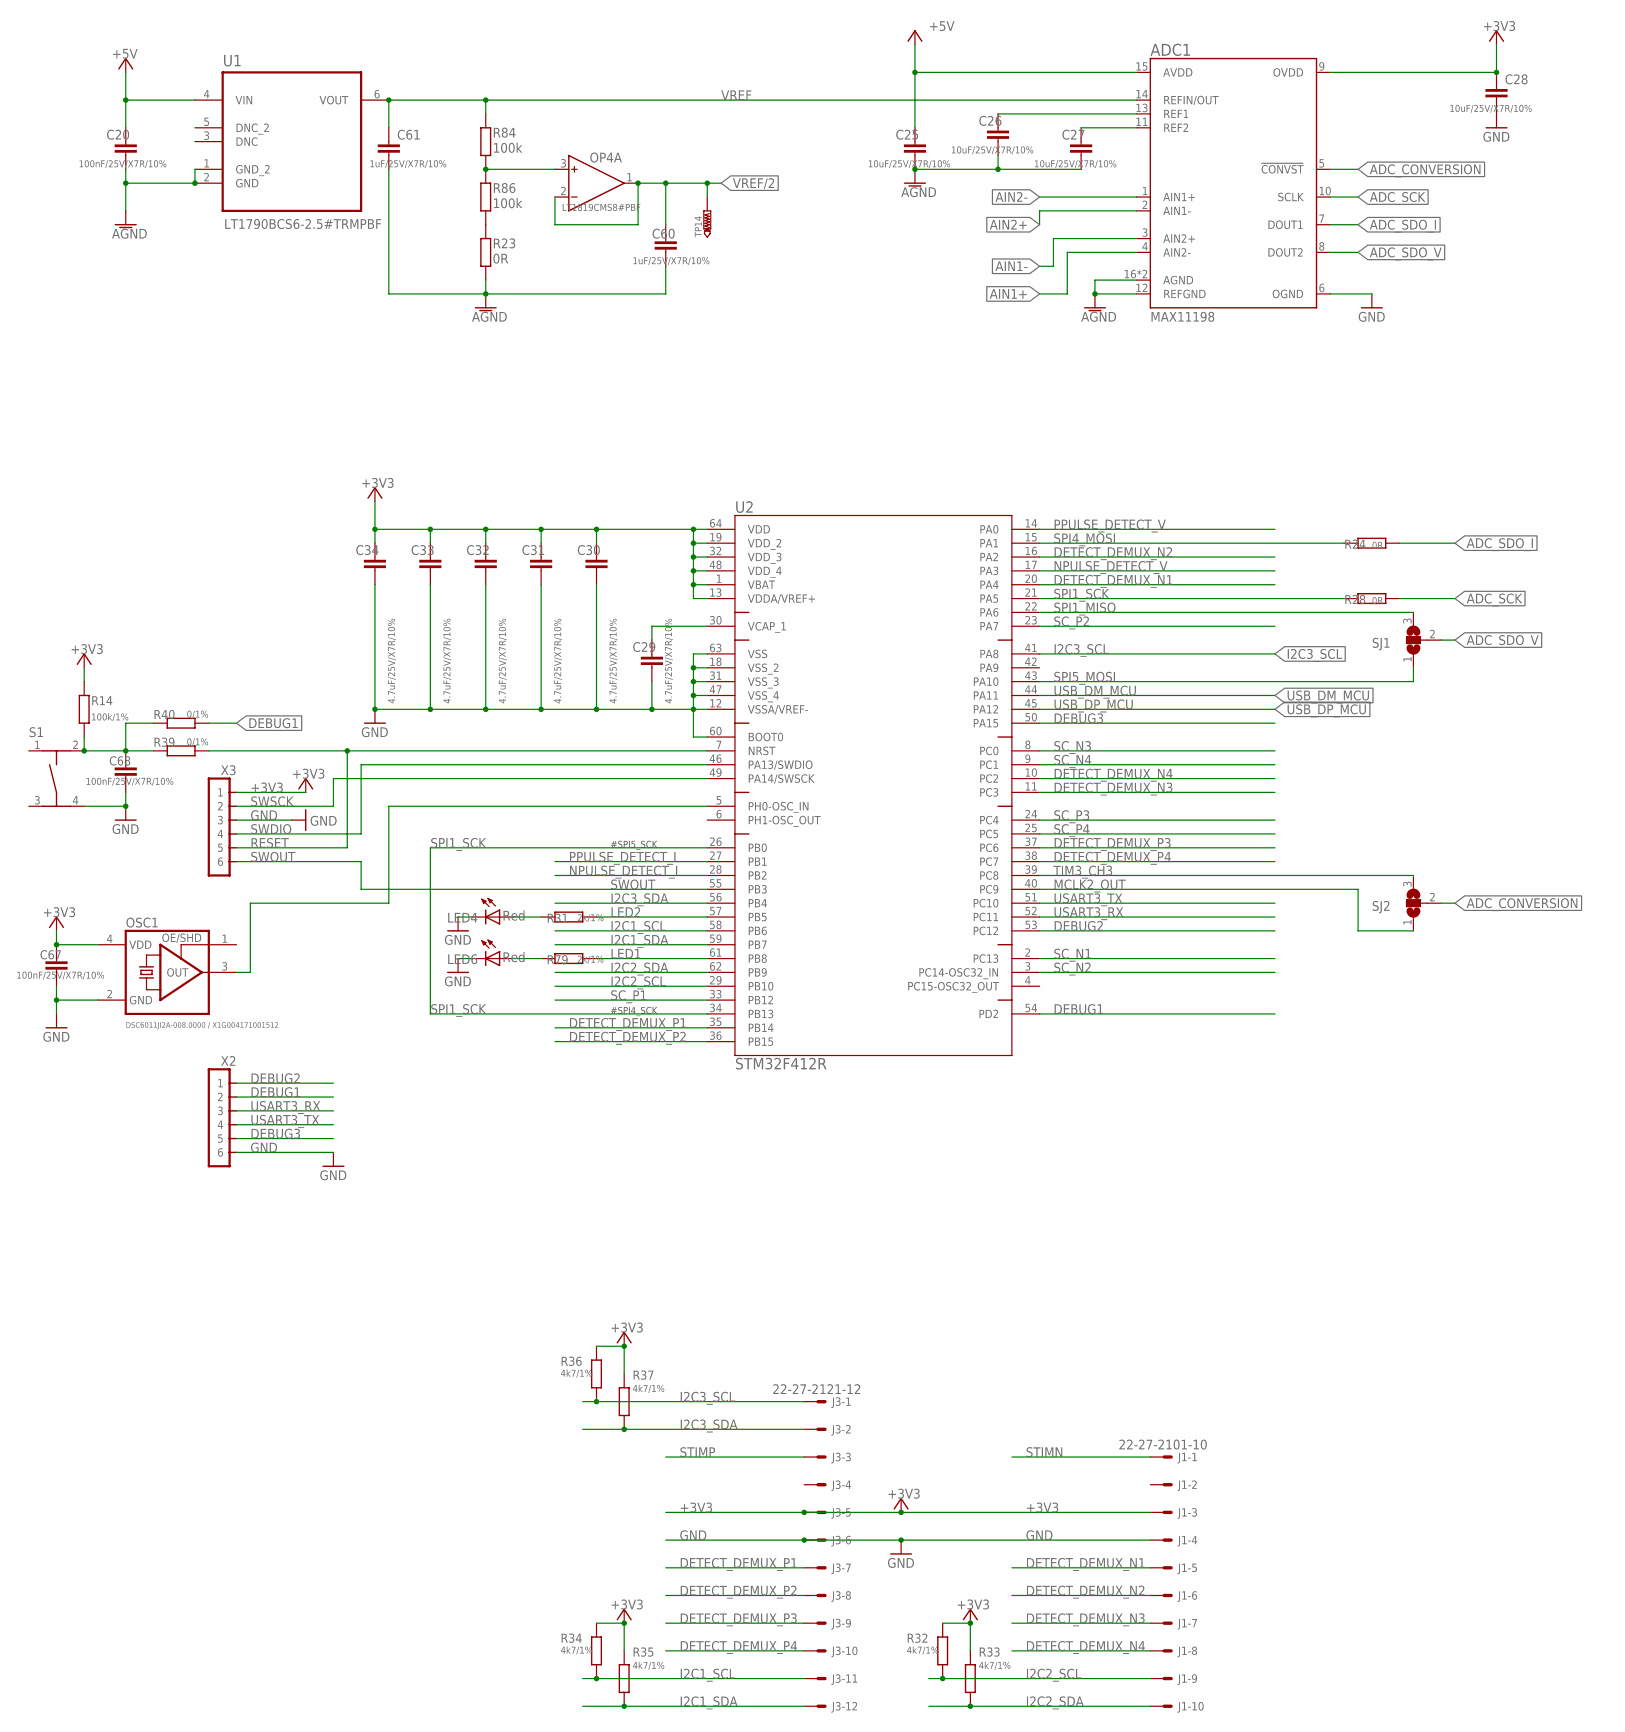
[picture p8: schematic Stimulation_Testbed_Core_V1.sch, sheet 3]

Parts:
ADC1: MAX11198; T1623CN+1
C20, C67, C68: 100nF/25V/X7R/10%; C0603K
C25, C26, C27, C28: 10uF/25V/X7R/10%; C0603K
C29, C30, C31, C32, C33, C34: 4.7uF/25V/X7R/10%; C0603K
C60, C61: 1uF/25V/X7R/10%; C0603K
J1: 22-27-2101-10; 6410-10
J3: 22-27-2121-12; 6410-12
LED4, LED6: Red; CHIPLED_0603
OP4: LT1819CMS8#PBF; MSOP8
OSC1: DSC6011JI2A-008.0000 / X1G004171001512; OSC_2.5X2
R14: 100k/1%; R0603
R23, R24, R28: 0R; R0603
R31, R79: 2k/1%; R0603
R32, R33, R34, R35, R36, R37: 4k7/1%; R0603
R39, R40: 0/1%; R0603
R84, R86: 100k; R0603
S1: TASTERSMD; TAST_SMD
SJ1, SJ2: SJ2W; SJ_2
TP14: TESTPOINT_TH; TP1-09
U1: LT1790BCS6-2.5#TRMPBF; SOT95P280X100-6N
U2: STM32F412R; LQFP64-10X10MM
X2, X3: PINHD-1X66X1.27; 1.27_1X06_S

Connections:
+3V3: ADC1.9 (OVDD), C28.1, C30.1, C31.1, C32.1, C33.1, C34.1, C67.1, J1.3, J3.5, OSC1.4 (VDD), R14.2, R32.1, R33.1, R34.1, R35.1, R36.1, R37.1, U2.1 (VBAT), U2.13 (VDDA/VREF+), U2.19 (VDD_2), U2.32 (VDD_3), U2.48 (VDD_4), U2.64 (VDD), X3.P1 (1); also elsewhere on the board
+5V: ADC1.15 (AVDD), C20.1, C25.1, U1.4 (VIN); also elsewhere on the board
ADC_CONVERSION: ADC1.5 (!CONVST!), SJ2.2
ADC_SCK: ADC1.10 (SCLK), R28.2
ADC_SDO_I: ADC1.7 (DOUT1), R24.2
ADC_SDO_V: ADC1.8 (DOUT2), SJ1.2
AGND: ADC1.12 (REFGND), ADC1.16 (AGND), ADC1.EXP (AGND), C20.2, C25.2, C26.2, C27.2, C60.2, C61.2, R23.2, U1.1 (GND_2), U1.2 (GND); also elsewhere on the board
AIN1+: ADC1.4 (AIN2-); also elsewhere on the board
AIN1-: ADC1.3 (AIN2+); also elsewhere on the board
AIN2+: ADC1.2 (AIN1-); also elsewhere on the board
AIN2-: ADC1.1 (AIN1+); also elsewhere on the board
DEBUG1: R40.1, U2.54 (PD2), X2.P2 (2)
DEBUG2: U2.53 (PC12), X2.P1 (1)
DEBUG3: U2.50 (PA15), X2.P5 (5)
DETECT_DEMUX_N1: J1.5, U2.20 (PA4)
DETECT_DEMUX_N2: J1.6, U2.16 (PA2)
DETECT_DEMUX_N3: J1.7, U2.11 (PC3)
DETECT_DEMUX_N4: J1.8, U2.10 (PC2)
DETECT_DEMUX_P1: J3.7, U2.35 (PB14)
DETECT_DEMUX_P2: J3.8, U2.36 (PB15)
DETECT_DEMUX_P3: J3.9, U2.37 (PC6)
DETECT_DEMUX_P4: J3.10, U2.38 (PC7)
GND: ADC1.6 (OGND), C28.2, C29.2, C30.2, C31.2, C32.2, C33.2, C34.2, C67.2, C68.2, J1.4, J3.6, LED4.C, LED6.C, OSC1.2 (GND), S1.4, U2.12 (VSSA/VREF-), U2.18 (VSS_2), U2.31 (VSS_3), U2.47 (VSS_4), U2.60 (BOOT0), U2.63 (VSS), X2.P6 (6), X3.P3 (3); also elsewhere on the board
I2C1_SCL: J3.11, R34.2, U2.58 (PB6)
I2C1_SDA: J3.12, R35.2, U2.59 (PB7)
I2C2_SCL: J1.9, R32.2, U2.29 (PB10)
I2C2_SDA: J1.10, R33.2, U2.62 (PB9)
I2C3_SCL: J3.1, R36.2, U2.41 (PA8)
I2C3_SDA: J3.2, R37.2, U2.56 (PB4)
LED1: R79.1, U2.61 (PB8)
LED2: R31.1, U2.57 (PB5)
MCLK2_OUT: SJ2.1, U2.40 (PC9)
unnamed: LED4.A, R31.2
unnamed: C29.1, U2.30 (VCAP_1)
unnamed: R23.1, R86.1
unnamed: C68.1, R14.1, R39.2, R40.2, S1.2
unnamed: ADC1.11 (REF2), C27.1
unnamed: ADC1.13 (REF1), C26.1
unnamed: OP4.3 (IN+), R84.2, R86.2
unnamed: OSC1.3 (OUT), U2.5 (PH0-OSC_IN)
unnamed: LED6.A, R79.2
NPULSE_DETECT_I: U2.28 (PB2); also elsewhere on the board
NPULSE_DETECT_V: U2.17 (PA3); also elsewhere on the board
PPULSE_DETECT_I: U2.27 (PB1); also elsewhere on the board
PPULSE_DETECT_V: U2.14 (PA0); also elsewhere on the board
RESET: R39.1, U2.7 (NRST), X3.P5 (5)
SC_N1: U2.2 (PC13); also elsewhere on the board
SC_N2: U2.3 (PC14-OSC32_IN); also elsewhere on the board
SC_N3: U2.8 (PC0); also elsewhere on the board
SC_N4: U2.9 (PC1); also elsewhere on the board
SC_P1: U2.33 (PB12); also elsewhere on the board
SC_P2: U2.23 (PA7); also elsewhere on the board
SC_P3: U2.24 (PC4); also elsewhere on the board
SC_P4: U2.25 (PC5); also elsewhere on the board
SPI1_MISO: SJ1.3, U2.22 (PA6)
SPI1_SCK: R28.1, U2.21 (PA5), U2.26 (PB0), U2.34 (PB13)
SPI4_MOSI: R24.1, U2.15 (PA1)
SPI5_MOSI: SJ1.1, U2.43 (PA10)
STIMN: J1.1; also elsewhere on the board
STIMP: J3.3; also elsewhere on the board
SWDIO: U2.46 (PA13/SWDIO), X3.P4 (4)
SWOUT: U2.55 (PB3), X3.P6 (6)
SWSCK: U2.49 (PA14/SWSCK), X3.P2 (2)
TIM3_CH3: SJ2.3, U2.39 (PC8)
USART3_RX: U2.52 (PC11), X2.P3 (3)
USART3_TX: U2.51 (PC10), X2.P4 (4)
USB_DM_MCU: U2.44 (PA11); also elsewhere on the board
USB_DP_MCU: U2.45 (PA12); also elsewhere on the board
VREF: ADC1.14 (REFIN/OUT), C61.1, R84.1, U1.6 (VOUT)
VREF/2: C60.1, OP4.1 (OUT), OP4.2 (IN-), TP14.TP; also elsewhere on the board

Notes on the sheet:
#SPI5_SCK
#SPI4_SCK

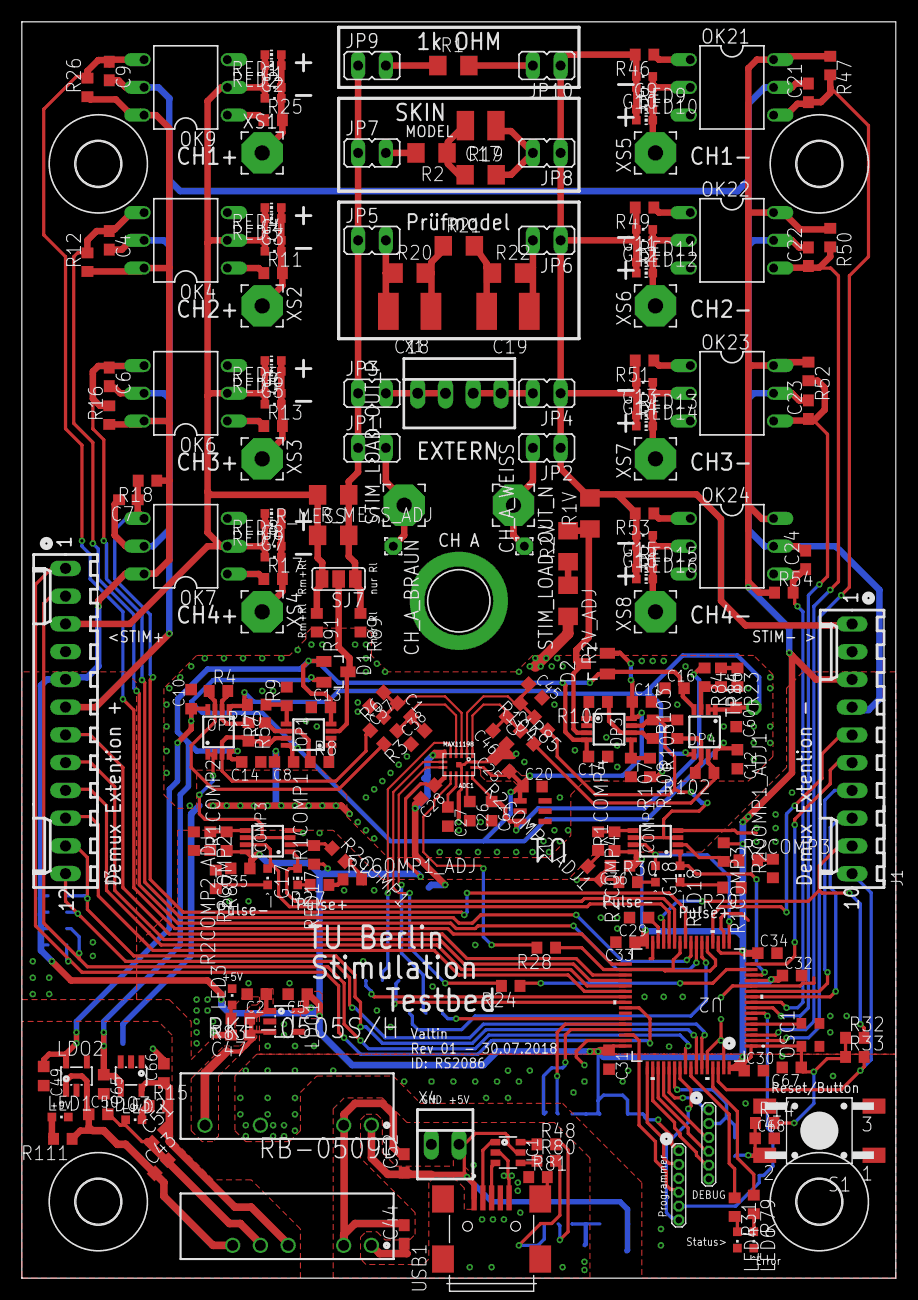
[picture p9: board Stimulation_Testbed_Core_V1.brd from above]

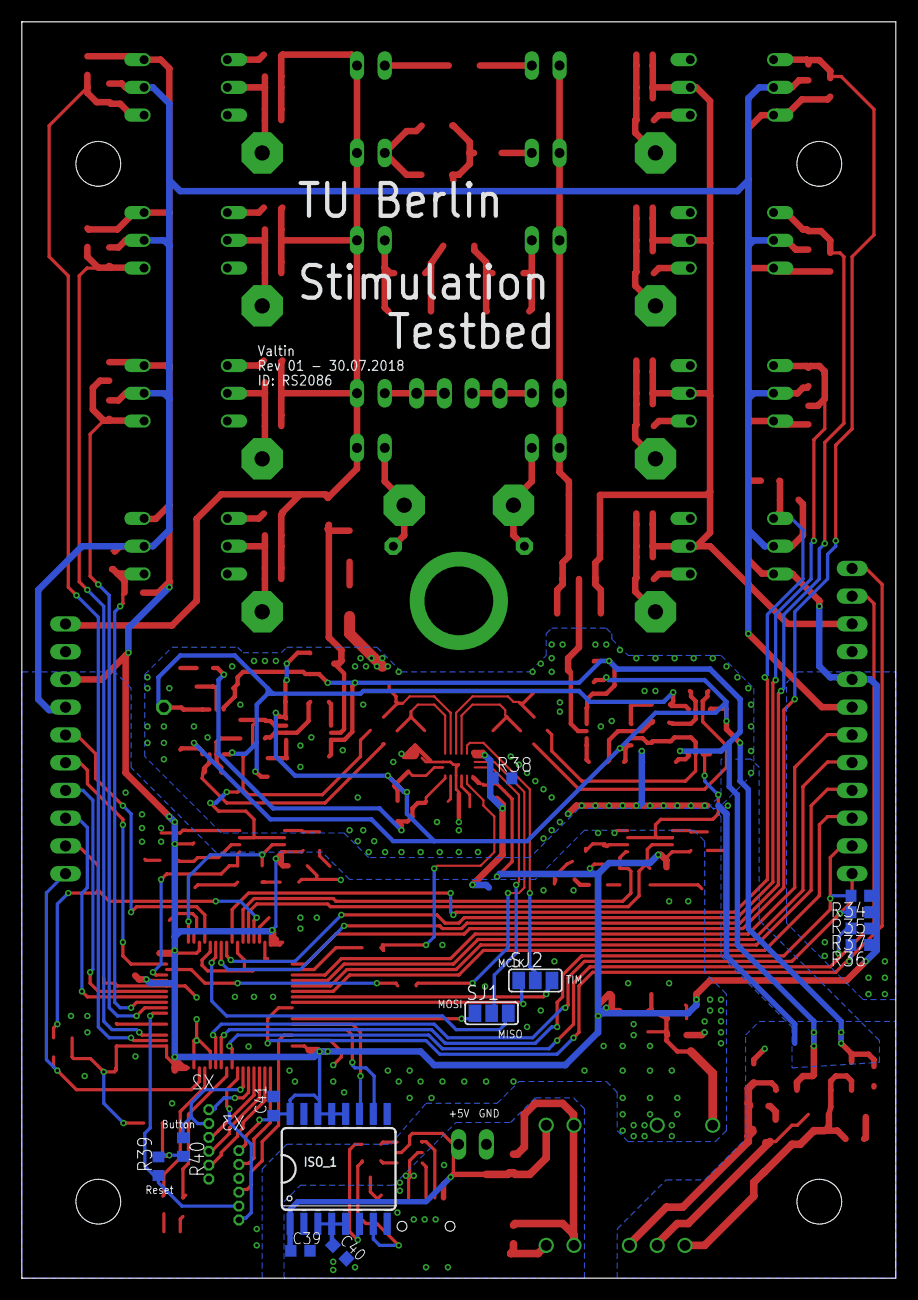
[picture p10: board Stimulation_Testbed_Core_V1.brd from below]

Board: 2 copper layers, 80.0 x 115.0 mm, 247 parts (13 on the bottom side), 145 nets.

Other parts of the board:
U$1, U$2, U$3, U$4: 4,1

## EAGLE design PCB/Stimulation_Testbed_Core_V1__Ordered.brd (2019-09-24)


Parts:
C2, C5, C49, C50, C66: 1uF/25V/X7R/10%; C0603K
C39, C40, C41: 100nF/25V/X7R/10%; C0603K
C43, C47, C51, C52: 4.7u/25V/X7R; C0603
C44: 4.7u/15V/X7R; C0603
C65: 4.7uF/25V/X7R/10%; C0603K
DC-DC_3V3: RKE-0505S/H; MEJ2
DC-DC_9V: RB-0509D; NMH
IC1: USBLC6-2; SOT-23-6
ISO_1: ADUM4160; SOIC16WIDE
LDO1: LDK220U33R ->3.3V; SOT-23-5
LDO2: LDK220M50R ->5V; SOT-23-5
LDO3: MIC5270-5.0YM5; SOT-23-5
LED1, LED2, LED3: LEDCHIPLED_0603; CHIPLED_0603
R15, R111: 2k/1%; R0603
R38: NA/0R/1%; R0603
R48, R80: 24/1%; R0603
R81: 10/5%; R0603
R83: 1k/1%; R0603
USB1: 1-1734035-1; TE_1-1734035-1
X4: 22-23-2021

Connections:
+3V3: C5.1, C41.1, ISO_1.12 (PIN), ISO_1.13 (SPD), ISO_1.14 (VDD2), ISO_1.16 (VBUS2), LDO1.5 (OUT); also elsewhere on the board
+5V: C49.1, LDO2.5 (OUT); also elsewhere on the board
+5V_IN: C2.1, C47.1, DC-DC_3V3.7 (+VOUT), LDO1.1 (IN), LDO1.3 (EN), R83.1
+5V_USB: C39.1, C44.1, C52.1, DC-DC_3V3.1 (+VIN), DC-DC_9V.1 (+VIN), IC1.5 (VBUS), ISO_1.1 (VBUS1), USB1.1 (VBUS), X4.2
+9V: C43.1, C50.1, DC-DC_9V.6 (+VOUT), LDO2.1 (IN), LDO2.3 (EN), R111.1
-5V: C65.1, LDO3.4 (OUT); also elsewhere on the board
-9V: C51.2, C66.1, DC-DC_9V.4 (-VOUT), LDO3.5 (IN), R15.2
AGND: C43.2, C49.2, C50.2, C51.1, C65.2, C66.2, DC-DC_9V.5 (0V), LDO2.2 (GND), LDO3.2 (GND), LED1.C, LED2.A, R38.2; also elsewhere on the board
GND: C2.2, C5.2, C41.2, C47.2, DC-DC_3V3.5 (-VOUT), ISO_1.9 (GND2), ISO_1.15 (GND2), LDO1.2 (GND), LED3.C, R38.1; also elsewhere on the board
GND_USB: C39.2, C40.2, C44.2, C52.2, DC-DC_3V3.2 (-VIN), DC-DC_9V.2 (GND), IC1.2 (GND), ISO_1.2 (GND1), ISO_1.8 (GND1), R81.1, USB1.5 (GND), X4.1
unnamed: IC1.6 (IO1), R48.1
unnamed: C40.1, ISO_1.3 (VDD1), ISO_1.4 (PDEN), ISO_1.5 (SPU)
unnamed: ISO_1.6 (UD-), R48.2
unnamed: ISO_1.7 (UD+), R80.2
unnamed: R81.2, USB1.7 (P1)
unnamed: LED2.C, R15.1
unnamed: LED3.A, R83.2
unnamed: LED1.A, R111.2
unnamed: IC1.3 (IO2), USB1.3 (D+)
unnamed: IC1.1 (IO1), USB1.2 (D-)
unnamed: IC1.4 (IO2), R80.1
USB_DM_MCU: ISO_1.11 (DD-); also elsewhere on the board
USB_DP_MCU: ISO_1.10 (DD+); also elsewhere on the board

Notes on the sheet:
R1/R2: Aus den Datenblatt für ADMU4160 + http://www.usb.org/developers/usbfaq#sig6
Isolated USB Input
LowVoltage LDOs for ICs
Isolated USB Output
POWER SUPPLY
Befindet sich beim ADC!

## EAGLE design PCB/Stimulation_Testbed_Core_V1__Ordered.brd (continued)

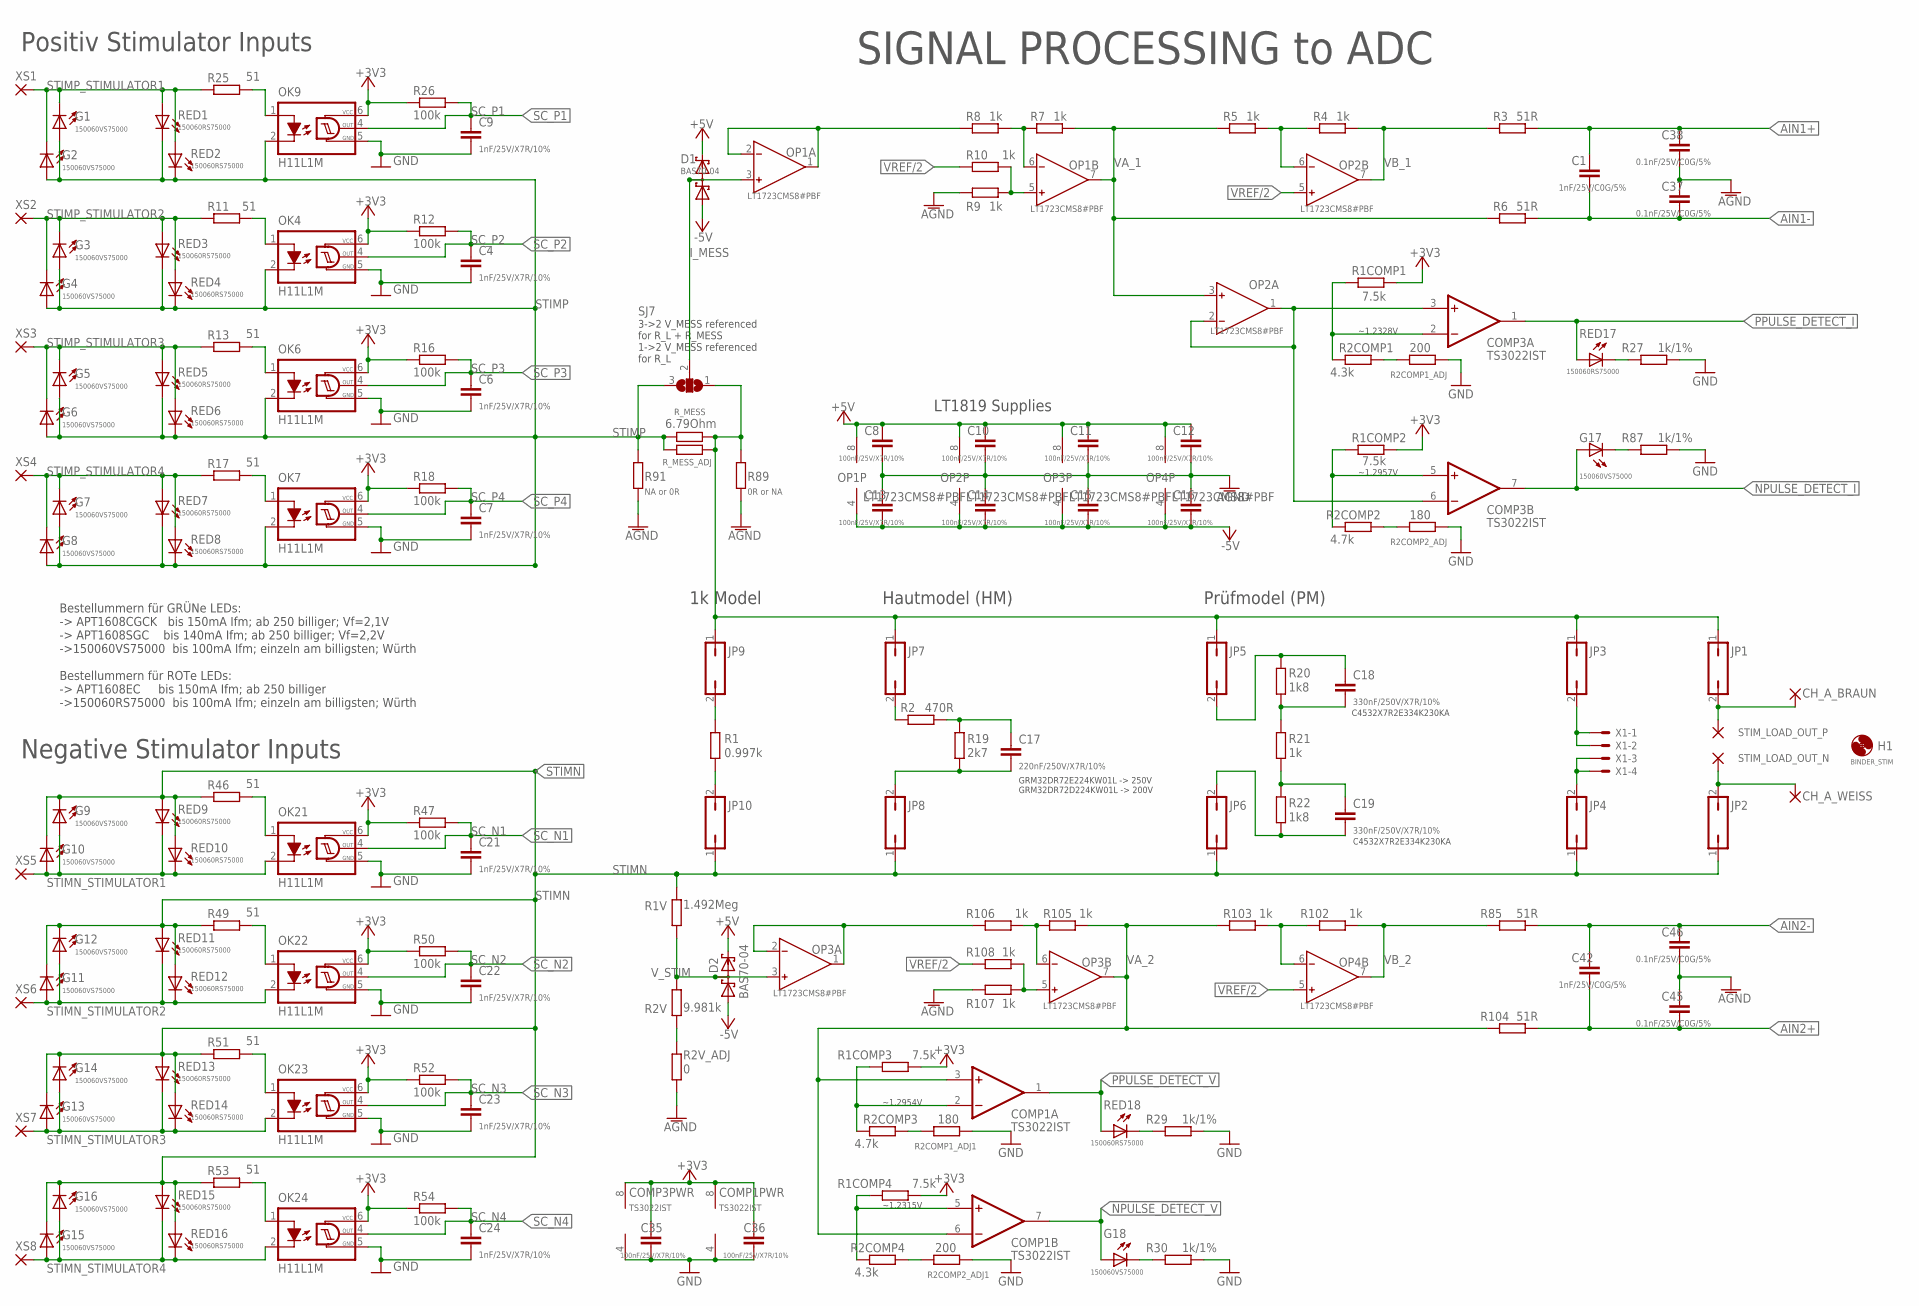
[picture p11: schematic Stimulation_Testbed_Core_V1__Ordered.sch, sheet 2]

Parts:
C1, C42: 1nF/25V/C0G/5%; C0603K
C4, C6, C7, C9, C21, C22, C23, C24: 1nF/25V/X7R/10%; C0603
C8, C10, C11, C12, C13, C14, C15, C16, C35, C36: 100nF/25V/X7R/10%; C0603K
C17: 220nF/250V/X7R/10%; C1210
C18, C19: 330nF/250V/X7R/10%; C1812
C37, C38, C45, C46: 0.1nF/25V/C0G/5%; C0603K
CH_A_BRAUN: 1,6/0,8
CH_A_WEISS: 1,6/0,8
COMP1, COMP3: TS3022IST; MSOP8
D1, D2: BAS70-04; SOT23
G1, G2, G3, G4, G5, G6, G7, G8, G9, G10, G11, G12, G13, G14, G15, G16, G17, G18: 150060VS75000; CHIPLED_0603
H1: BINDER_STIM; 5,5-PAD
JP1, JP2, JP3, JP4, JP5, JP6, JP7, JP8, JP9, JP10: JP1Q; JP1
OK4, OK6, OK7, OK9, OK21, OK22, OK23, OK24: H11L1M; DIL06
OP1, OP2, OP3, OP4: LT1723CMS8#PBF; MSOP8
R1: 0.997k; R1206
R1COMP1, R1COMP2, R1COMP3, R1COMP4: 7.5k; R0603
R1V: 1.492Meg; R1206
R2: 470R; R1206
R2COMP1, R2COMP4: 4.3k; R0603
R2COMP1_ADJ, R2COMP2_ADJ1: 200; R0603
R2COMP1_ADJ1, R2COMP2_ADJ: 180; R0603
R2COMP2, R2COMP3: 4.7k; R0603
R2V: 9.981k; R1206
R2V_ADJ: 0; R1206
R3, R6, R85, R104: 51R; R0603
R4, R5, R7, R8, R9, R10, R102, R103, R105, R106, R107, R108: 1k; R0603
R11, R13, R17, R25, R46, R49, R51, R53: 51; R0603
R12, R16, R18, R26, R47, R50, R52, R54: 100k; R0603
R19: 2k7; R1206
R20, R22: 1k8; R1206
R21: 1k; R1206
R27, R29, R30, R87: 1k/1%; R0603
R89: 0R or NA; R0603
R91: NA or 0R; R0603
RED1, RED2, RED3, RED4, RED5, RED6, RED7, RED8, RED9, RED10, RED11, RED12, RED13, RED14, RED15, RED16, RED17, RED18: 150060RS75000; CHIP-LED0603
R_MESS: 6.79Ohm; R1206
R_MESS_ADJ: R-EU_R1206; R1206
SJ7: SJ2W; SJ_2
STIM_LOAD_OUT_N: 3,81/1,4
STIM_LOAD_OUT_P: 3,81/1,4
X1: 22-23-2041
XS1, XS2, XS3, XS4, XS5, XS6, XS7, XS8: WIREPAD3,81/1,4; 3,81/1,4

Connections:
2XVREF: OP3.1 (OUT), OP3.2 (IN-), R106.2
2XVREF1: OP1.1 (OUT), OP1.2 (IN-), R8.2
+3V3: C35.1, C36.1, COMP1.8 (V+), COMP3.8 (V+), OK4.6 (VCC), OK6.6 (VCC), OK7.6 (VCC), OK9.6 (VCC), OK21.6 (VCC), OK22.6 (VCC), OK23.6 (VCC), OK24.6 (VCC), R1COMP1.1, R1COMP2.1, R1COMP3.1, R1COMP4.1, R12.1, R16.1, R18.1, R26.1, R47.1, R50.1, R52.1, R54.1; also elsewhere on the board
+5V: C8.1, C10.1, C11.1, C12.1, D1.2 (C2), D2.2 (C2), OP1.8 (V+), OP2.8 (V+), OP3.8 (V+), OP4.8 (V+); also elsewhere on the board
-5V: C13.2, C14.2, C15.2, C16.2, D1.1 (A1), D2.1 (A1), OP1.4 (V-), OP2.4 (V-), OP3.4 (V-), OP4.4 (V-); also elsewhere on the board
AGND: C8.2, C10.2, C11.2, C12.2, C13.1, C14.1, C15.1, C16.1, C37.2, C38.1, C45.2, C46.1, R2V_ADJ.2, R9.2, R89.2, R91.2, R107.2; also elsewhere on the board
AIN1+: C1.2, C38.2, R3.1; also elsewhere on the board
AIN1-: C1.1, C37.1, R6.2; also elsewhere on the board
AIN2+: C42.1, C45.1, R104.2; also elsewhere on the board
AIN2-: C42.2, C46.2, R85.1; also elsewhere on the board
GND: C4.2, C6.2, C7.2, C9.2, C21.2, C22.2, C23.2, C24.2, C35.2, C36.2, COMP1.4 (V-), COMP3.4 (V-), OK4.5 (GND), OK6.5 (GND), OK7.5 (GND), OK9.5 (GND), OK21.5 (GND), OK22.5 (GND), OK23.5 (GND), OK24.5 (GND), R2COMP1_ADJ.1, R2COMP1_ADJ1.1, R2COMP2_ADJ.1, R2COMP2_ADJ1.1, R27.1, R29.1, R30.1, R87.1; also elsewhere on the board
I_MESS: D1.3 (C1A2), OP1.3 (IN+), SJ7.2
unnamed: OK4.1 (A), R11.1
unnamed: R2COMP2.2, R2COMP2_ADJ.2
unnamed: R29.2, RED18.C
unnamed: G18.C, R30.2
unnamed: COMP1.2 (-IN), R1COMP3.2, R2COMP3.1
unnamed: COMP1.5 (+IN), R1COMP4.2, R2COMP4.1
unnamed: G17.C, R87.2
unnamed: OP1.5 (IN+), R9.1, R10.1
unnamed: R2COMP1_ADJ1.2, R2COMP3.2
unnamed: R2COMP2_ADJ1.2, R2COMP4.2
unnamed: OK6.1 (A), R13.1
unnamed: OK7.1 (A), R17.1
unnamed: OK9.1 (A), R25.1
unnamed: OP1.6 (IN-), R7.2, R8.1
unnamed: OP2.6 (IN-), R4.2, R5.1
unnamed: COMP3.3 (+IN), COMP3.6 (-IN), OP2.1 (OUT), OP2.2 (IN-)
unnamed: OK21.1 (A), R46.1
unnamed: COMP3.2 (-IN), R1COMP1.2, R2COMP1.1
unnamed: CH_A_WEISS.1, JP2.2, STIM_LOAD_OUT_N.1
unnamed: OK22.1 (A), R49.1
unnamed: OK23.1 (A), R51.1
unnamed: OK24.1 (A), R53.1
unnamed: R2V.1, R2V_ADJ.1
unnamed: OP3.5 (IN+), R107.1, R108.1
unnamed: CH_A_BRAUN.1, JP1.2, STIM_LOAD_OUT_P.1
unnamed: JP3.2, X1.1, X1.2
unnamed: JP9.2, R1.1
unnamed: JP4.2, X1.3, X1.4
unnamed: JP10.2, R1.2
unnamed: JP7.2, R2.2
unnamed: OP3.6 (IN-), R105.2, R106.1
unnamed: C17.1, JP8.2, R19.2
unnamed: C19.2, R21.2, R22.1
unnamed: C19.1, JP6.2, R22.2
unnamed: C18.2, JP5.2, R20.1
unnamed: C18.1, R20.2, R21.1
unnamed: OP4.6 (IN-), R102.2, R103.1
unnamed: C17.2, R2.1, R19.1
unnamed: R27.2, RED17.C
unnamed: COMP3.5 (+IN), R1COMP2.2, R2COMP2.1
unnamed: R2COMP1.2, R2COMP1_ADJ.2
NPULSE_DETECT_I: COMP3.7 (OUT), G17.A; also elsewhere on the board
NPULSE_DETECT_V: COMP1.7 (OUT), G18.A; also elsewhere on the board
PPULSE_DETECT_I: COMP3.1 (OUT), RED17.A; also elsewhere on the board
PPULSE_DETECT_V: COMP1.1 (OUT), RED18.A; also elsewhere on the board
SC_N1: C21.1, OK21.4 (OUT), R47.2; also elsewhere on the board
SC_N2: C22.1, OK22.4 (OUT), R50.2; also elsewhere on the board
SC_N3: C23.1, OK23.4 (OUT), R52.2; also elsewhere on the board
SC_N4: C24.1, OK24.4 (OUT), R54.2; also elsewhere on the board
SC_P1: C9.1, OK9.4 (OUT), R26.2; also elsewhere on the board
SC_P2: C4.1, OK4.4 (OUT), R12.2; also elsewhere on the board
SC_P3: C6.1, OK6.4 (OUT), R16.2; also elsewhere on the board
SC_P4: C7.1, OK7.4 (OUT), R18.2; also elsewhere on the board
STIMN: G9.C, G10.C, G11.C, G12.C, G13.C, G14.C, G15.C, G16.C, JP2.1, JP4.1, JP6.1, JP8.1, JP10.1, R1V.2, R46.2, R49.2, R51.2, R53.2, RED9.A, RED10.A, RED11.A, RED12.A, RED13.A, RED14.A, RED15.A, RED16.A; also elsewhere on the board
STIMN_STIMULATOR1: G9.A, G10.A, OK21.2 (C), RED9.C, RED10.C, XS5.1
STIMN_STIMULATOR2: G11.A, G12.A, OK22.2 (C), RED11.C, RED12.C, XS6.1
STIMN_STIMULATOR3: G13.A, G14.A, OK23.2 (C), RED13.C, RED14.C, XS7.1
STIMN_STIMULATOR4: G15.A, G16.A, OK24.2 (C), RED15.C, RED16.C, XS8.1
STIMP: G1.A, G2.A, G3.A, G4.A, G5.A, G6.A, G7.A, G8.A, OK4.2 (C), OK6.2 (C), OK7.2 (C), OK9.2 (C), R91.1, RED1.C, RED2.C, RED3.C, RED4.C, RED5.C, RED6.C, RED7.C, RED8.C, R_MESS.2, R_MESS_ADJ.1, SJ7.3; also elsewhere on the board
STIMP_MODEL: JP1.1, JP3.1, JP5.1, JP7.1, JP9.1, R89.1, R_MESS.1, R_MESS_ADJ.2, SJ7.1
STIMP_STIMULATOR1: G1.C, G2.C, R25.2, RED1.A, RED2.A, XS1.1
STIMP_STIMULATOR2: G3.C, G4.C, R11.2, RED3.A, RED4.A, XS2.1
STIMP_STIMULATOR3: G5.C, G6.C, R13.2, RED5.A, RED6.A, XS3.1
STIMP_STIMULATOR4: G7.C, G8.C, R17.2, RED7.A, RED8.A, XS4.1
VA_1: OP1.7 (OUT), OP2.3 (IN+), R5.2, R6.1, R7.1
VA_2: COMP1.3 (+IN), COMP1.6 (-IN), OP3.7 (OUT), R103.2, R104.1, R105.1
VB_1: OP2.7 (OUT), R3.2, R4.1
VB_2: OP4.7 (OUT), R85.2, R102.1
VREF/2: OP2.5 (IN+), OP4.5 (IN+), R10.2, R108.2; also elsewhere on the board
V_STIM: D2.3 (C1A2), OP3.3 (IN+), R1V.1, R2V.2

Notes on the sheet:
LT1819 Supplies
1k Model
Hautmodel (HM)
Prüfmodel (PM)
SIGNAL PROCESSING to ADC
3->2 V_MESS referenced for R_L + R_MESS 1->2 V_MESS referenced for R_L
Positiv Stimulator Inputs
Negative Stimulator Inputs
C4532X7R2E334K230KA
GRM32DR72E224KW01L -> 250V GRM32DR72D224KW01L -> 200V
Bestellummern für GRÜNe LEDs: -> APT1608CGCK bis 150mA Ifm; ab 250 billiger; Vf=2,1V -> APT1608SGC bis 140mA Ifm; ab 250 billiger; Vf=2,2V ->150060VS75000 bis 100mA Ifm; einzeln am billigsten; Würth Bestellummern für ROTe LEDs: -> APT1608EC bis 150mA Ifm; ab 250 billiger ->150060RS75000 bis 100mA I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
~1.2328V
~1.2957V
~1.2954V
~1.2315V

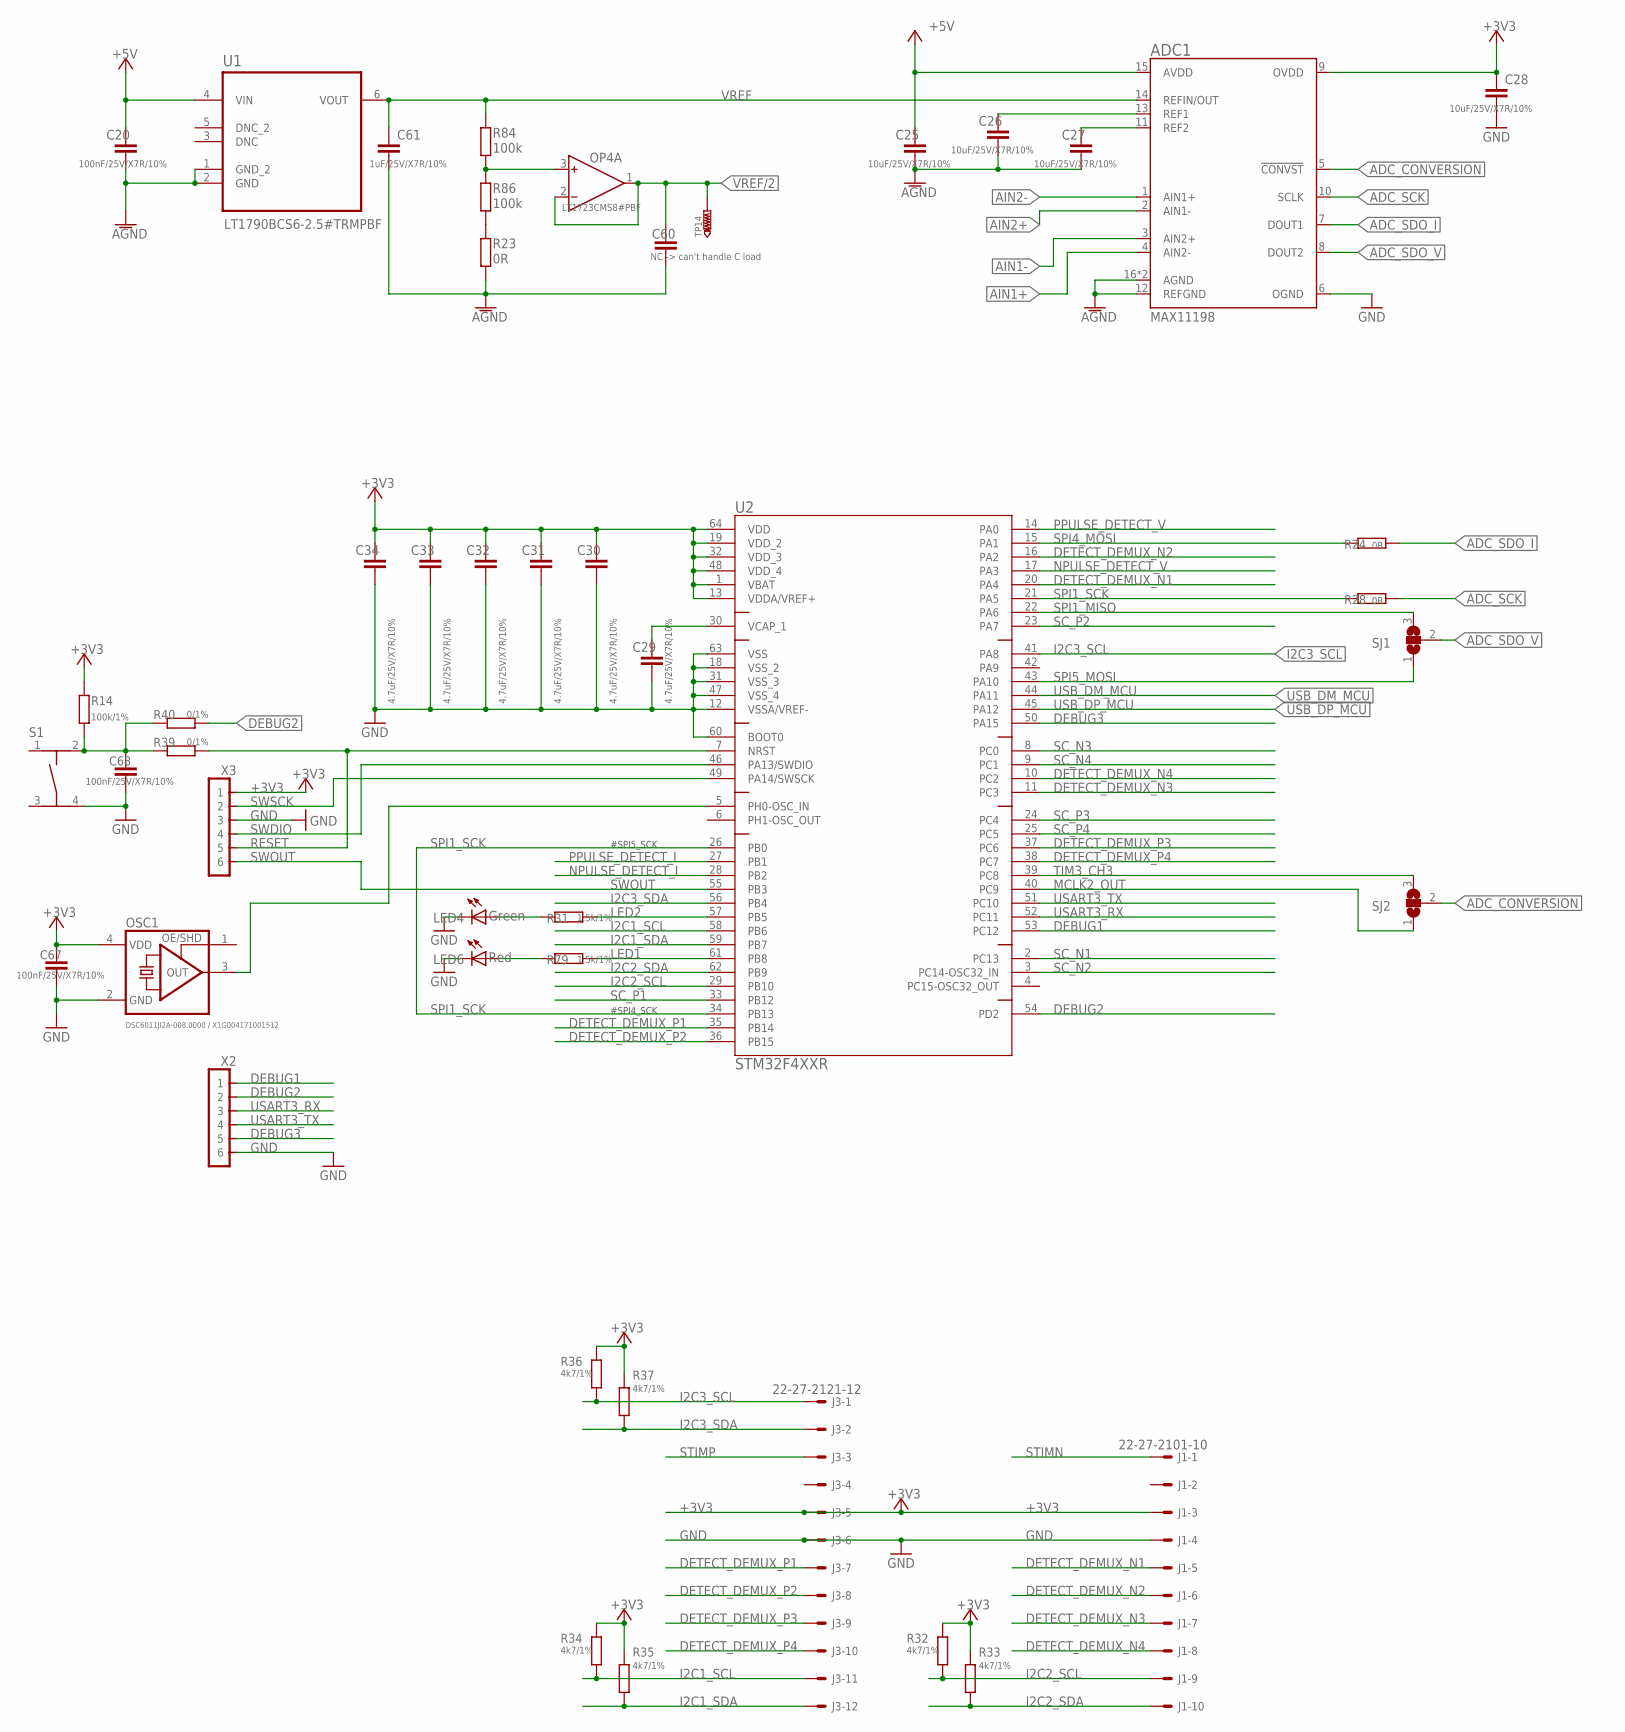
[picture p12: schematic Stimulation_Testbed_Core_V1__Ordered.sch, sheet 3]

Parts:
ADC1: MAX11198; T1623CN+1
C20, C67, C68: 100nF/25V/X7R/10%; C0603K
C25, C26, C27, C28: 10uF/25V/X7R/10%; C0603K
C29, C30, C31, C32, C33, C34: 4.7uF/25V/X7R/10%; C0603K
C60: NC -> can't handle C load; C0603K
C61: 1uF/25V/X7R/10%; C0603K
J1: 22-27-2101-10; 6410-10
J3: 22-27-2121-12; 6410-12
LED4: Green; CHIPLED_0603
LED6: Red; CHIPLED_0603
OP4: LT1723CMS8#PBF; MSOP8
OSC1: DSC6011JI2A-008.0000 / X1G004171001512; OSC_2.5X2
R14: 100k/1%; R0603
R23, R24, R28: 0R; R0603
R31, R79: 1.5k/1%; R0603
R32, R33, R34, R35, R36, R37: 4k7/1%; R0603
R39, R40: 0/1%; R0603
R84, R86: 100k; R0603
S1: TASTERSMD; TAST_SMD
SJ1, SJ2: SJ2W; SJ_2
TP14: TESTPOINT_TH; TP1-09
U1: LT1790BCS6-2.5#TRMPBF; SOT95P280X100-6N
U2: STM32F4XXR; LQFP64-10X10MM
X2, X3: PINHD-1X66X1.27; 1.27_1X06_S

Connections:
+3V3: ADC1.9 (OVDD), C28.1, C30.1, C31.1, C32.1, C33.1, C34.1, C67.1, J1.3, J3.5, OSC1.4 (VDD), R14.2, R32.1, R33.1, R34.1, R35.1, R36.1, R37.1, U2.1 (VBAT), U2.13 (VDDA/VREF+), U2.19 (VDD_2), U2.32 (VDD_3), U2.48 (VDD_4), U2.64 (VDD), X3.P1 (1); also elsewhere on the board
+5V: ADC1.15 (AVDD), C20.1, C25.1, U1.4 (VIN); also elsewhere on the board
ADC_CONVERSION: ADC1.5 (!CONVST!), SJ2.2
ADC_SCK: ADC1.10 (SCLK), R28.2
ADC_SDO_I: ADC1.7 (DOUT1), R24.2
ADC_SDO_V: ADC1.8 (DOUT2), SJ1.2
AGND: ADC1.12 (REFGND), ADC1.16 (AGND), ADC1.EXP (AGND), C20.2, C25.2, C26.2, C27.2, C60.2, C61.2, R23.2, U1.1 (GND_2), U1.2 (GND); also elsewhere on the board
AIN1+: ADC1.4 (AIN2-); also elsewhere on the board
AIN1-: ADC1.3 (AIN2+); also elsewhere on the board
AIN2+: ADC1.2 (AIN1-); also elsewhere on the board
AIN2-: ADC1.1 (AIN1+); also elsewhere on the board
DEBUG1: U2.53 (PC12), X2.P1 (1)
DEBUG2: R40.1, U2.54 (PD2), X2.P2 (2)
DEBUG3: U2.50 (PA15), X2.P5 (5)
DETECT_DEMUX_N1: J1.5, U2.20 (PA4)
DETECT_DEMUX_N2: J1.6, U2.16 (PA2)
DETECT_DEMUX_N3: J1.7, U2.11 (PC3)
DETECT_DEMUX_N4: J1.8, U2.10 (PC2)
DETECT_DEMUX_P1: J3.7, U2.35 (PB14)
DETECT_DEMUX_P2: J3.8, U2.36 (PB15)
DETECT_DEMUX_P3: J3.9, U2.37 (PC6)
DETECT_DEMUX_P4: J3.10, U2.38 (PC7)
GND: ADC1.6 (OGND), C28.2, C29.2, C30.2, C31.2, C32.2, C33.2, C34.2, C67.2, C68.2, J1.4, J3.6, LED4.C, LED6.C, OSC1.2 (GND), S1.4, U2.12 (VSSA/VREF-), U2.18 (VSS_2), U2.31 (VSS_3), U2.47 (VSS_4), U2.60 (BOOT0), U2.63 (VSS), X2.P6 (6), X3.P3 (3); also elsewhere on the board
I2C1_SCL: J3.11, R34.2, U2.58 (PB6)
I2C1_SDA: J3.12, R35.2, U2.59 (PB7)
I2C2_SCL: J1.9, R32.2, U2.29 (PB10)
I2C2_SDA: J1.10, R33.2, U2.62 (PB9)
I2C3_SCL: J3.1, R36.2, U2.41 (PA8)
I2C3_SDA: J3.2, R37.2, U2.56 (PB4)
LED1: R79.1, U2.61 (PB8)
LED2: R31.1, U2.57 (PB5)
MCLK2_OUT: SJ2.1, U2.40 (PC9)
unnamed: LED4.A, R31.2
unnamed: C29.1, U2.30 (VCAP_1)
unnamed: R23.1, R86.1
unnamed: C68.1, R14.1, R39.2, R40.2, S1.2
unnamed: ADC1.11 (REF2), C27.1
unnamed: ADC1.13 (REF1), C26.1
unnamed: OP4.3 (IN+), R84.2, R86.2
unnamed: OSC1.3 (OUT), U2.5 (PH0-OSC_IN)
unnamed: LED6.A, R79.2
NPULSE_DETECT_I: U2.28 (PB2); also elsewhere on the board
NPULSE_DETECT_V: U2.17 (PA3); also elsewhere on the board
PPULSE_DETECT_I: U2.27 (PB1); also elsewhere on the board
PPULSE_DETECT_V: U2.14 (PA0); also elsewhere on the board
RESET: R39.1, U2.7 (NRST), X3.P5 (5)
SC_N1: U2.2 (PC13); also elsewhere on the board
SC_N2: U2.3 (PC14-OSC32_IN); also elsewhere on the board
SC_N3: U2.8 (PC0); also elsewhere on the board
SC_N4: U2.9 (PC1); also elsewhere on the board
SC_P1: U2.33 (PB12); also elsewhere on the board
SC_P2: U2.23 (PA7); also elsewhere on the board
SC_P3: U2.24 (PC4); also elsewhere on the board
SC_P4: U2.25 (PC5); also elsewhere on the board
SPI1_MISO: SJ1.3, U2.22 (PA6)
SPI1_SCK: R28.1, U2.21 (PA5), U2.26 (PB0), U2.34 (PB13)
SPI4_MOSI: R24.1, U2.15 (PA1)
SPI5_MOSI: SJ1.1, U2.43 (PA10)
STIMN: J1.1; also elsewhere on the board
STIMP: J3.3; also elsewhere on the board
SWDIO: U2.46 (PA13/SWDIO), X3.P4 (4)
SWOUT: U2.55 (PB3), X3.P6 (6)
SWSCK: U2.49 (PA14/SWSCK), X3.P2 (2)
TIM3_CH3: SJ2.3, U2.39 (PC8)
USART3_RX: U2.52 (PC11), X2.P3 (3)
USART3_TX: U2.51 (PC10), X2.P4 (4)
USB_DM_MCU: U2.44 (PA11); also elsewhere on the board
USB_DP_MCU: U2.45 (PA12); also elsewhere on the board
VREF: ADC1.14 (REFIN/OUT), C61.1, R84.1, U1.6 (VOUT)
VREF/2: C60.1, OP4.1 (OUT), OP4.2 (IN-), TP14.TP; also elsewhere on the board

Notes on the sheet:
#SPI5_SCK
#SPI4_SCK

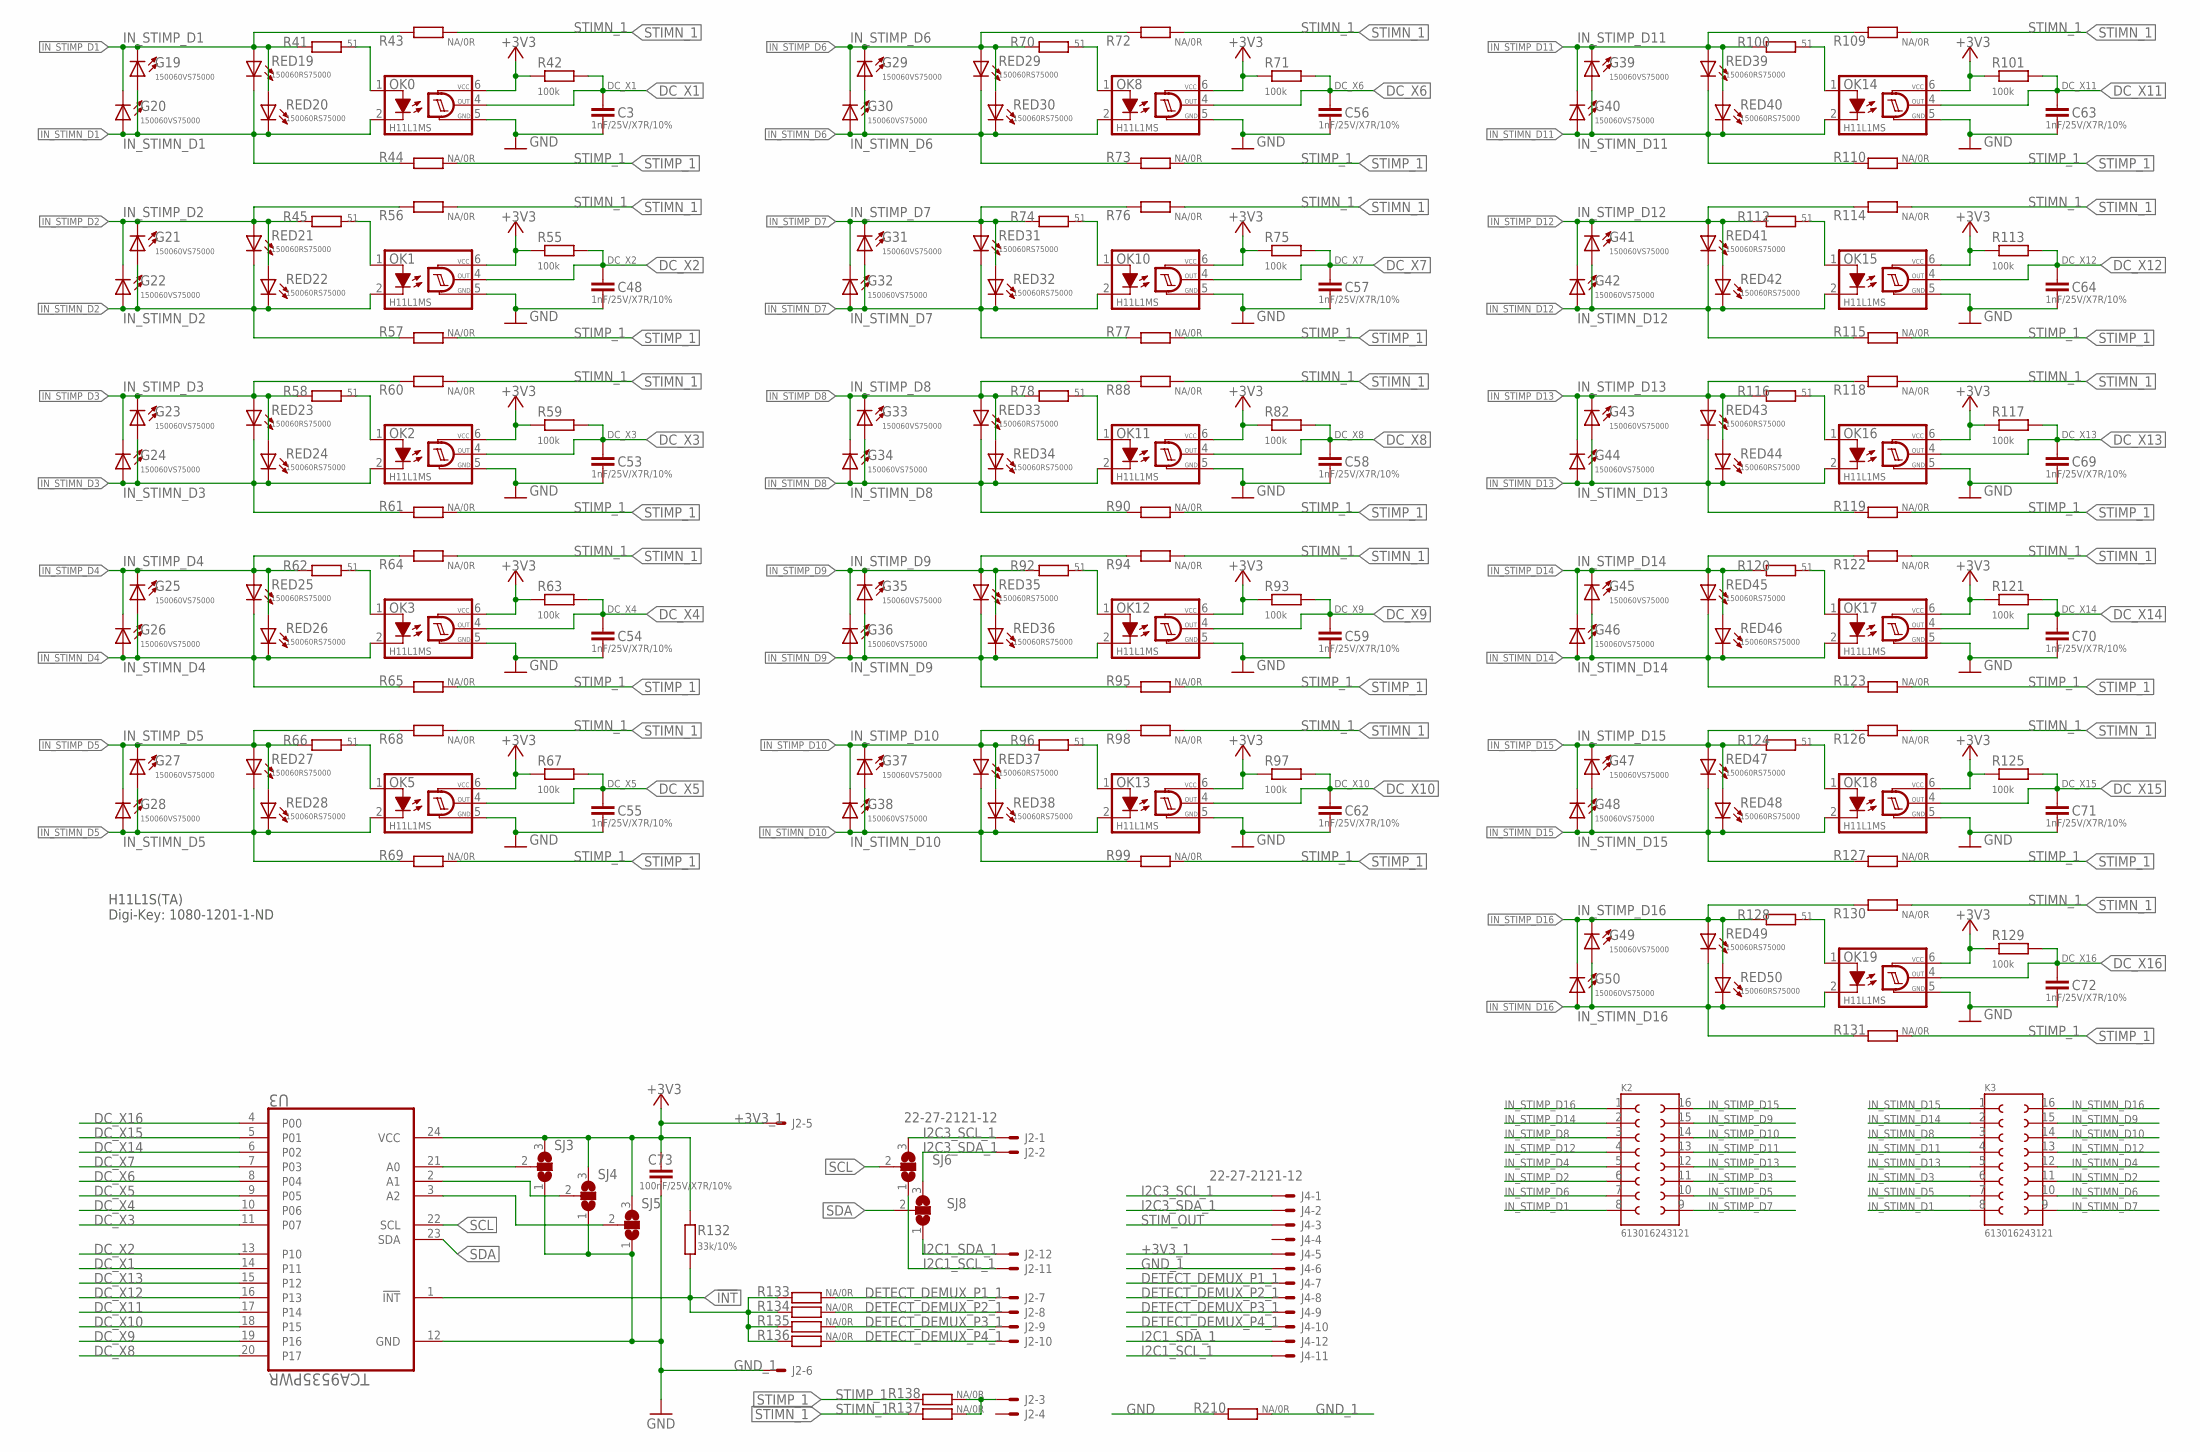
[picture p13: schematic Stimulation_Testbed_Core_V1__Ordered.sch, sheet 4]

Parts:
C3, C48, C53, C54, C55, C56, C57, C58, C59, C62, C63, C64, C69, C70, C71, C72: 1nF/25V/X7R/10%; C0603
C73: 100nF/25V/X7R/10%; C0603K
G19, G20, G21, G22, G23, G24, G25, G26, G27, G28, G29, G30, G31, G32, G33, G34, G35, G36, G37, G38, G39, G40, G41, G42, G43, G44, G45, G46, G47, G48, G49, G50: 150060VS75000; CHIPLED_0603
J2, J4: 22-27-2121-12; 6410-12
K2, K3: 613016243121
OK0, OK1, OK2, OK3, OK5, OK8, OK10, OK11, OK12, OK13, OK14, OK15, OK16, OK17, OK18, OK19: H11L1MS; DIL6-SMD
R41, R45, R58, R62, R66, R70, R74, R78, R92, R96, R100, R112, R116, R120, R124, R128: 51; R0603
R42, R55, R59, R63, R67, R71, R75, R82, R93, R97, R101, R113, R117, R121, R125, R129: 100k; R0603
R43, R44, R56, R57, R60, R61, R64, R65, R68, R69, R72, R73, R76, R77, R88, R90, R94, R95, R98, R99, R109, R110, R114, R115, R118, R119, R122, R123, R126, R127, R130, R131, R133, R134, R135, R136, R137, R138: NA/0R; R0603
R132: 33k/10%; R0603
R210: NA/0R; R6332
RED19, RED20, RED21, RED22, RED23, RED24, RED25, RED26, RED27, RED28, RED29, RED30, RED31, RED32, RED33, RED34, RED35, RED36, RED37, RED38, RED39, RED40, RED41, RED42, RED43, RED44, RED45, RED46, RED47, RED48, RED49, RED50: 150060RS75000; CHIP-LED0603
SJ3, SJ4, SJ5, SJ6, SJ8: SJ2W; SJ_2
U3: TCA9535PWR; SOP65P640X120-24N

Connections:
!INT: R132.1, R133.2, R134.2, R135.2, R136.2, U3.1 (!INT)
+3V3_1: C73.1, J2.5, J4.5, OK0.6 (VCC), OK1.6 (VCC), OK2.6 (VCC), OK3.6 (VCC), OK5.6 (VCC), OK8.6 (VCC), OK10.6 (VCC), OK11.6 (VCC), OK12.6 (VCC), OK13.6 (VCC), OK14.6 (VCC), OK15.6 (VCC), OK16.6 (VCC), OK17.6 (VCC), OK18.6 (VCC), OK19.6 (VCC), R42.1, R55.1, R59.1, R63.1, R67.1, R71.1, R75.1, R82.1, R93.1, R97.1, R101.1, R113.1, R117.1, R121.1, R125.1, R129.1, R132.2, SJ3.3, SJ4.3, SJ5.3, U3.24 (VCC)
DC_X1: C3.1, OK0.4 (OUT), R42.2, U3.14 (P11)
DC_X2: C48.1, OK1.4 (OUT), R55.2, U3.13 (P10)
DC_X3: C53.1, OK2.4 (OUT), R59.2, U3.11 (P07)
DC_X4: C54.1, OK3.4 (OUT), R63.2, U3.10 (P06)
DC_X5: C55.1, OK5.4 (OUT), R67.2, U3.9 (P05)
DC_X6: C56.1, OK8.4 (OUT), R71.2, U3.8 (P04)
DC_X7: C57.1, OK10.4 (OUT), R75.2, U3.7 (P03)
DC_X8: C58.1, OK11.4 (OUT), R82.2, U3.20 (P17)
DC_X9: C59.1, OK12.4 (OUT), R93.2, U3.19 (P16)
DC_X10: C62.1, OK13.4 (OUT), R97.2, U3.18 (P15)
DC_X11: C63.1, OK14.4 (OUT), R101.2, U3.17 (P14)
DC_X12: C64.1, OK15.4 (OUT), R113.2, U3.16 (P13)
DC_X13: C69.1, OK16.4 (OUT), R117.2, U3.15 (P12)
DC_X14: C70.1, OK17.4 (OUT), R121.2, U3.6 (P02)
DC_X15: C71.1, OK18.4 (OUT), R125.2, U3.5 (P01)
DC_X16: C72.1, OK19.4 (OUT), R129.2, U3.4 (P00)
DETECT_DEMUX_P1_1: J2.7, J4.7, R133.1
DETECT_DEMUX_P2_1: J2.8, J4.8, R134.1
DETECT_DEMUX_P3_1: J2.9, J4.9, R135.1
DETECT_DEMUX_P4_1: J2.10, J4.10, R136.1
GND: R210.2; also elsewhere on the board
GND_1: C3.2, C48.2, C53.2, C54.2, C55.2, C56.2, C57.2, C58.2, C59.2, C62.2, C63.2, C64.2, C69.2, C70.2, C71.2, C72.2, C73.2, J2.6, J4.6, OK0.5 (GND), OK1.5 (GND), OK2.5 (GND), OK3.5 (GND), OK5.5 (GND), OK8.5 (GND), OK10.5 (GND), OK11.5 (GND), OK12.5 (GND), OK13.5 (GND), OK14.5 (GND), OK15.5 (GND), OK16.5 (GND), OK17.5 (GND), OK18.5 (GND), OK19.5 (GND), R210.1, SJ3.1, SJ4.1, SJ5.1, U3.12 (GND); also elsewhere on the board
I2C1_SCL_1: J2.11, J4.11, SJ6.1
I2C1_SDA_1: J2.12, J4.12, SJ8.1
I2C3_SCL_1: J2.1, J4.1, SJ6.3
I2C3_SDA_1: J2.2, J4.2, SJ8.3
IN_STIMN_D1: G19.A, G20.A, K3.8, OK0.2 (C), R44.2, RED19.C, RED20.C
IN_STIMN_D2: G21.A, G22.A, K3.11, OK1.2 (C), R57.2, RED21.C, RED22.C
IN_STIMN_D3: G23.A, G24.A, K3.6, OK2.2 (C), R61.2, RED23.C, RED24.C
IN_STIMN_D4: G25.A, G26.A, K3.12, OK3.2 (C), R65.2, RED25.C, RED26.C
IN_STIMN_D5: G27.A, G28.A, K3.7, OK5.2 (C), R69.2, RED27.C, RED28.C
IN_STIMN_D6: G29.A, G30.A, K3.10, OK8.2 (C), R73.2, RED29.C, RED30.C
IN_STIMN_D7: G31.A, G32.A, K3.9, OK10.2 (C), R77.2, RED31.C, RED32.C
IN_STIMN_D8: G33.A, G34.A, K3.3, OK11.2 (C), R90.2, RED33.C, RED34.C
IN_STIMN_D9: G35.A, G36.A, K3.15, OK12.2 (C), R95.2, RED35.C, RED36.C
IN_STIMN_D10: G37.A, G38.A, K3.14, OK13.2 (C), R99.2, RED37.C, RED38.C
IN_STIMN_D11: G39.A, G40.A, K3.4, OK14.2 (C), R110.2, RED39.C, RED40.C
IN_STIMN_D12: G41.A, G42.A, K3.13, OK15.2 (C), R115.2, RED41.C, RED42.C
IN_STIMN_D13: G43.A, G44.A, K3.5, OK16.2 (C), R119.2, RED43.C, RED44.C
IN_STIMN_D14: G45.A, G46.A, K3.2, OK17.2 (C), R123.2, RED45.C, RED46.C
IN_STIMN_D15: G47.A, G48.A, K3.1, OK18.2 (C), R127.2, RED47.C, RED48.C
IN_STIMN_D16: G49.A, G50.A, K3.16, OK19.2 (C), R131.2, RED49.C, RED50.C
IN_STIMP_D1: G19.C, G20.C, K2.8, R41.2, R43.2, RED19.A, RED20.A
IN_STIMP_D2: G21.C, G22.C, K2.6, R45.2, R56.2, RED21.A, RED22.A
IN_STIMP_D3: G23.C, G24.C, K2.11, R58.2, R60.2, RED23.A, RED24.A
IN_STIMP_D4: G25.C, G26.C, K2.5, R62.2, R64.2, RED25.A, RED26.A
IN_STIMP_D5: G27.C, G28.C, K2.10, R66.2, R68.2, RED27.A, RED28.A
IN_STIMP_D6: G29.C, G30.C, K2.7, R70.2, R72.2, RED29.A, RED30.A
IN_STIMP_D7: G31.C, G32.C, K2.9, R74.2, R76.2, RED31.A, RED32.A
IN_STIMP_D8: G33.C, G34.C, K2.3, R78.2, R88.2, RED33.A, RED34.A
IN_STIMP_D9: G35.C, G36.C, K2.15, R92.2, R94.2, RED35.A, RED36.A
IN_STIMP_D10: G37.C, G38.C, K2.14, R96.2, R98.2, RED37.A, RED38.A
IN_STIMP_D11: G39.C, G40.C, K2.13, R100.2, R109.2, RED39.A, RED40.A
IN_STIMP_D12: G41.C, G42.C, K2.4, R112.2, R114.2, RED41.A, RED42.A
IN_STIMP_D13: G43.C, G44.C, K2.12, R116.2, R118.2, RED43.A, RED44.A
IN_STIMP_D14: G45.C, G46.C, K2.2, R120.2, R122.2, RED45.A, RED46.A
IN_STIMP_D15: G47.C, G48.C, K2.16, R124.2, R126.2, RED47.A, RED48.A
IN_STIMP_D16: G49.C, G50.C, K2.1, R128.2, R130.2, RED49.A, RED50.A
unnamed: OK1.1 (A), R45.1
unnamed: OK0.1 (A), R41.1
unnamed: OK2.1 (A), R58.1
unnamed: OK3.1 (A), R62.1
unnamed: OK5.1 (A), R66.1
unnamed: OK8.1 (A), R70.1
unnamed: OK10.1 (A), R74.1
unnamed: OK11.1 (A), R78.1
unnamed: OK13.1 (A), R96.1
unnamed: OK12.1 (A), R92.1
unnamed: OK14.1 (A), R100.1
unnamed: OK15.1 (A), R112.1
unnamed: OK16.1 (A), R116.1
unnamed: OK17.1 (A), R120.1
unnamed: OK18.1 (A), R124.1
unnamed: OK19.1 (A), R128.1
unnamed: SJ3.2, U3.21 (A0)
unnamed: SJ4.2, U3.2 (A1)
unnamed: SJ5.2, U3.3 (A2)
SCL: SJ6.2, U3.22 (SCL)
SDA: SJ8.2, U3.23 (SDA)
STIMN_1: R43.1, R56.1, R60.1, R64.1, R68.1, R72.1, R76.1, R88.1, R94.1, R98.1, R109.1, R114.1, R118.1, R122.1, R126.1, R130.1, R137.2
STIMP_1: R44.1, R57.1, R61.1, R65.1, R69.1, R73.1, R77.1, R90.1, R95.1, R99.1, R110.1, R115.1, R119.1, R123.1, R127.1, R131.1, R138.2
STIM_OUT: J2.3, J4.3, R137.1, R138.1

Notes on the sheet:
H11L1S(TA) Digi-Key: 1080-1201-1-ND

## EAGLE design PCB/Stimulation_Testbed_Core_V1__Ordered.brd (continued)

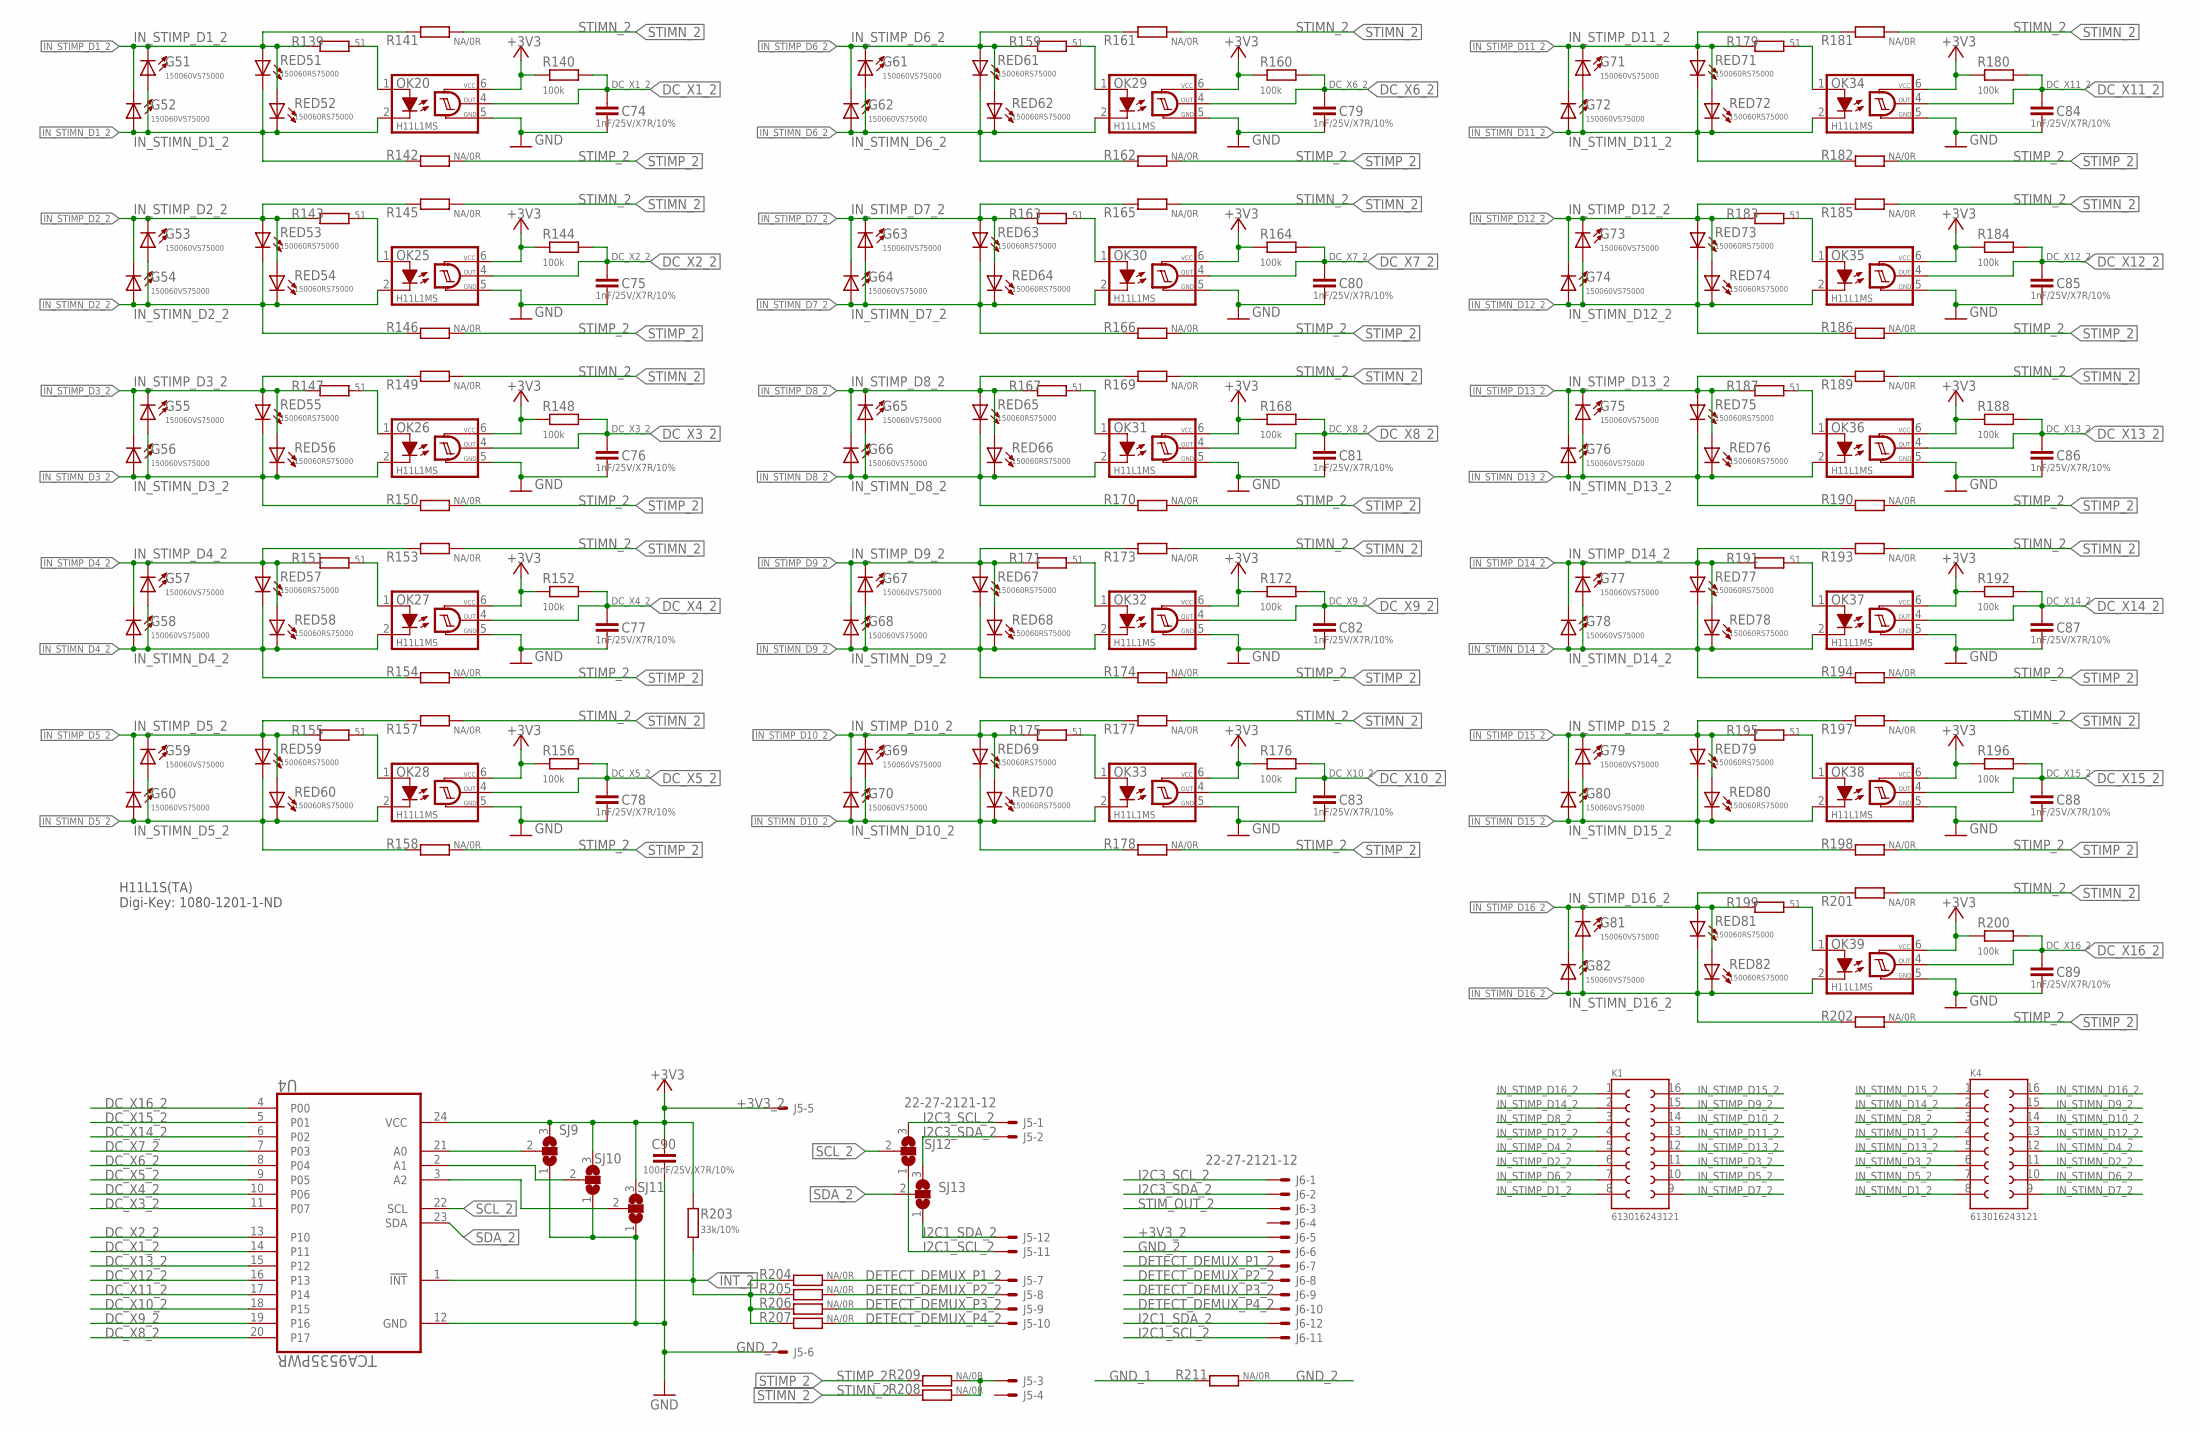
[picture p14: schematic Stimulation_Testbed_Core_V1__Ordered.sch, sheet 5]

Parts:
C74, C75, C76, C77, C78, C79, C80, C81, C82, C83, C84, C85, C86, C87, C88, C89: 1nF/25V/X7R/10%; C0603
C90: 100nF/25V/X7R/10%; C0603K
G51, G52, G53, G54, G55, G56, G57, G58, G59, G60, G61, G62, G63, G64, G65, G66, G67, G68, G69, G70, G71, G72, G73, G74, G75, G76, G77, G78, G79, G80, G81, G82: 150060VS75000; CHIPLED_0603
J5, J6: 22-27-2121-12; 6410-12
K1, K4: 613016243121
OK20, OK25, OK26, OK27, OK28, OK29, OK30, OK31, OK32, OK33, OK34, OK35, OK36, OK37, OK38, OK39: H11L1MS; DIL6-SMD
R139, R143, R147, R151, R155, R159, R163, R167, R171, R175, R179, R183, R187, R191, R195, R199: 51; R0603
R140, R144, R148, R152, R156, R160, R164, R168, R172, R176, R180, R184, R188, R192, R196, R200: 100k; R0603
R141, R142, R145, R146, R149, R150, R153, R154, R157, R158, R161, R162, R165, R166, R169, R170, R173, R174, R177, R178, R181, R182, R185, R186, R189, R190, R193, R194, R197, R198, R201, R202, R204, R205, R206, R207, R208, R209: NA/0R; R0603
R203: 33k/10%; R0603
R211: NA/0R; R6332
RED51, RED52, RED53, RED54, RED55, RED56, RED57, RED58, RED59, RED60, RED61, RED62, RED63, RED64, RED65, RED66, RED67, RED68, RED69, RED70, RED71, RED72, RED73, RED74, RED75, RED76, RED77, RED78, RED79, RED80, RED81, RED82: 150060RS75000; CHIP-LED0603
SJ9, SJ10, SJ11, SJ12, SJ13: SJ2W; SJ_2
U4: TCA9535PWR; SOP65P640X120-24N

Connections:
!INT_2: R203.1, R204.2, R205.2, R206.2, R207.2, U4.1 (!INT)
+3V3_2: C90.1, J5.5, J6.5, OK20.6 (VCC), OK25.6 (VCC), OK26.6 (VCC), OK27.6 (VCC), OK28.6 (VCC), OK29.6 (VCC), OK30.6 (VCC), OK31.6 (VCC), OK32.6 (VCC), OK33.6 (VCC), OK34.6 (VCC), OK35.6 (VCC), OK36.6 (VCC), OK37.6 (VCC), OK38.6 (VCC), OK39.6 (VCC), R140.1, R144.1, R148.1, R152.1, R156.1, R160.1, R164.1, R168.1, R172.1, R176.1, R180.1, R184.1, R188.1, R192.1, R196.1, R200.1, R203.2, SJ9.3, SJ10.3, SJ11.3, U4.24 (VCC)
DC_X1_2: C74.1, OK20.4 (OUT), R140.2, U4.14 (P11)
DC_X2_2: C75.1, OK25.4 (OUT), R144.2, U4.13 (P10)
DC_X3_2: C76.1, OK26.4 (OUT), R148.2, U4.11 (P07)
DC_X4_2: C77.1, OK27.4 (OUT), R152.2, U4.10 (P06)
DC_X5_2: C78.1, OK28.4 (OUT), R156.2, U4.9 (P05)
DC_X6_2: C79.1, OK29.4 (OUT), R160.2, U4.8 (P04)
DC_X7_2: C80.1, OK30.4 (OUT), R164.2, U4.7 (P03)
DC_X8_2: C81.1, OK31.4 (OUT), R168.2, U4.20 (P17)
DC_X9_2: C82.1, OK32.4 (OUT), R172.2, U4.19 (P16)
DC_X10_2: C83.1, OK33.4 (OUT), R176.2, U4.18 (P15)
DC_X11_2: C84.1, OK34.4 (OUT), R180.2, U4.17 (P14)
DC_X12_2: C85.1, OK35.4 (OUT), R184.2, U4.16 (P13)
DC_X13_2: C86.1, OK36.4 (OUT), R188.2, U4.15 (P12)
DC_X14_2: C87.1, OK37.4 (OUT), R192.2, U4.6 (P02)
DC_X15_2: C88.1, OK38.4 (OUT), R196.2, U4.5 (P01)
DC_X16_2: C89.1, OK39.4 (OUT), R200.2, U4.4 (P00)
DETECT_DEMUX_P1_2: J5.7, J6.7, R204.1
DETECT_DEMUX_P2_2: J5.8, J6.8, R205.1
DETECT_DEMUX_P3_2: J5.9, J6.9, R206.1
DETECT_DEMUX_P4_2: J5.10, J6.10, R207.1
GND_1: R211.2; also elsewhere on the board
GND_2: C74.2, C75.2, C76.2, C77.2, C78.2, C79.2, C80.2, C81.2, C82.2, C83.2, C84.2, C85.2, C86.2, C87.2, C88.2, C89.2, C90.2, J5.6, J6.6, OK20.5 (GND), OK25.5 (GND), OK26.5 (GND), OK27.5 (GND), OK28.5 (GND), OK29.5 (GND), OK30.5 (GND), OK31.5 (GND), OK32.5 (GND), OK33.5 (GND), OK34.5 (GND), OK35.5 (GND), OK36.5 (GND), OK37.5 (GND), OK38.5 (GND), OK39.5 (GND), R211.1, SJ9.1, SJ10.1, SJ11.1, U4.12 (GND)
I2C1_SCL_2: J5.11, J6.11, SJ12.1
I2C1_SDA_2: J5.12, J6.12, SJ13.1
I2C3_SCL_2: J5.1, J6.1, SJ12.3
I2C3_SDA_2: J5.2, J6.2, SJ13.3
IN_STIMN_D1_2: G51.A, G52.A, K4.8, OK20.2 (C), R142.2, RED51.C, RED52.C
IN_STIMN_D2_2: G53.A, G54.A, K4.11, OK25.2 (C), R146.2, RED53.C, RED54.C
IN_STIMN_D3_2: G55.A, G56.A, K4.6, OK26.2 (C), R150.2, RED55.C, RED56.C
IN_STIMN_D4_2: G57.A, G58.A, K4.12, OK27.2 (C), R154.2, RED57.C, RED58.C
IN_STIMN_D5_2: G59.A, G60.A, K4.7, OK28.2 (C), R158.2, RED59.C, RED60.C
IN_STIMN_D6_2: G61.A, G62.A, K4.10, OK29.2 (C), R162.2, RED61.C, RED62.C
IN_STIMN_D7_2: G63.A, G64.A, K4.9, OK30.2 (C), R166.2, RED63.C, RED64.C
IN_STIMN_D8_2: G65.A, G66.A, K4.3, OK31.2 (C), R170.2, RED65.C, RED66.C
IN_STIMN_D9_2: G67.A, G68.A, K4.15, OK32.2 (C), R174.2, RED67.C, RED68.C
IN_STIMN_D10_2: G69.A, G70.A, K4.14, OK33.2 (C), R178.2, RED69.C, RED70.C
IN_STIMN_D11_2: G71.A, G72.A, K4.4, OK34.2 (C), R182.2, RED71.C, RED72.C
IN_STIMN_D12_2: G73.A, G74.A, K4.13, OK35.2 (C), R186.2, RED73.C, RED74.C
IN_STIMN_D13_2: G75.A, G76.A, K4.5, OK36.2 (C), R190.2, RED75.C, RED76.C
IN_STIMN_D14_2: G77.A, G78.A, K4.2, OK37.2 (C), R194.2, RED77.C, RED78.C
IN_STIMN_D15_2: G79.A, G80.A, K4.1, OK38.2 (C), R198.2, RED79.C, RED80.C
IN_STIMN_D16_2: G81.A, G82.A, K4.16, OK39.2 (C), R202.2, RED81.C, RED82.C
IN_STIMP_D1_2: G51.C, G52.C, K1.8, R139.2, R141.2, RED51.A, RED52.A
IN_STIMP_D2_2: G53.C, G54.C, K1.6, R143.2, R145.2, RED53.A, RED54.A
IN_STIMP_D3_2: G55.C, G56.C, K1.11, R147.2, R149.2, RED55.A, RED56.A
IN_STIMP_D4_2: G57.C, G58.C, K1.5, R151.2, R153.2, RED57.A, RED58.A
IN_STIMP_D5_2: G59.C, G60.C, K1.10, R155.2, R157.2, RED59.A, RED60.A
IN_STIMP_D6_2: G61.C, G62.C, K1.7, R159.2, R161.2, RED61.A, RED62.A
IN_STIMP_D7_2: G63.C, G64.C, K1.9, R163.2, R165.2, RED63.A, RED64.A
IN_STIMP_D8_2: G65.C, G66.C, K1.3, R167.2, R169.2, RED65.A, RED66.A
IN_STIMP_D9_2: G67.C, G68.C, K1.15, R171.2, R173.2, RED67.A, RED68.A
IN_STIMP_D10_2: G69.C, G70.C, K1.14, R175.2, R177.2, RED69.A, RED70.A
IN_STIMP_D11_2: G71.C, G72.C, K1.13, R179.2, R181.2, RED71.A, RED72.A
IN_STIMP_D12_2: G73.C, G74.C, K1.4, R183.2, R185.2, RED73.A, RED74.A
IN_STIMP_D13_2: G75.C, G76.C, K1.12, R187.2, R189.2, RED75.A, RED76.A
IN_STIMP_D14_2: G77.C, G78.C, K1.2, R191.2, R193.2, RED77.A, RED78.A
IN_STIMP_D15_2: G79.C, G80.C, K1.16, R195.2, R197.2, RED79.A, RED80.A
IN_STIMP_D16_2: G81.C, G82.C, K1.1, R199.2, R201.2, RED81.A, RED82.A
unnamed: OK25.1 (A), R143.1
unnamed: OK20.1 (A), R139.1
unnamed: OK26.1 (A), R147.1
unnamed: OK27.1 (A), R151.1
unnamed: OK28.1 (A), R155.1
unnamed: OK29.1 (A), R159.1
unnamed: OK30.1 (A), R163.1
unnamed: OK31.1 (A), R167.1
unnamed: OK33.1 (A), R175.1
unnamed: OK32.1 (A), R171.1
unnamed: OK34.1 (A), R179.1
unnamed: OK35.1 (A), R183.1
unnamed: OK36.1 (A), R187.1
unnamed: OK37.1 (A), R191.1
unnamed: OK38.1 (A), R195.1
unnamed: OK39.1 (A), R199.1
unnamed: SJ9.2, U4.21 (A0)
unnamed: SJ10.2, U4.2 (A1)
unnamed: SJ11.2, U4.3 (A2)
SCL_2: SJ12.2, U4.22 (SCL)
SDA_2: SJ13.2, U4.23 (SDA)
STIMN_2: R141.1, R145.1, R149.1, R153.1, R157.1, R161.1, R165.1, R169.1, R173.1, R177.1, R181.1, R185.1, R189.1, R193.1, R197.1, R201.1, R208.2
STIMP_2: R142.1, R146.1, R150.1, R154.1, R158.1, R162.1, R166.1, R170.1, R174.1, R178.1, R182.1, R186.1, R190.1, R194.1, R198.1, R202.1, R209.2
STIM_OUT_2: J5.3, J6.3, R208.1, R209.1

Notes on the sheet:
H11L1S(TA) Digi-Key: 1080-1201-1-ND

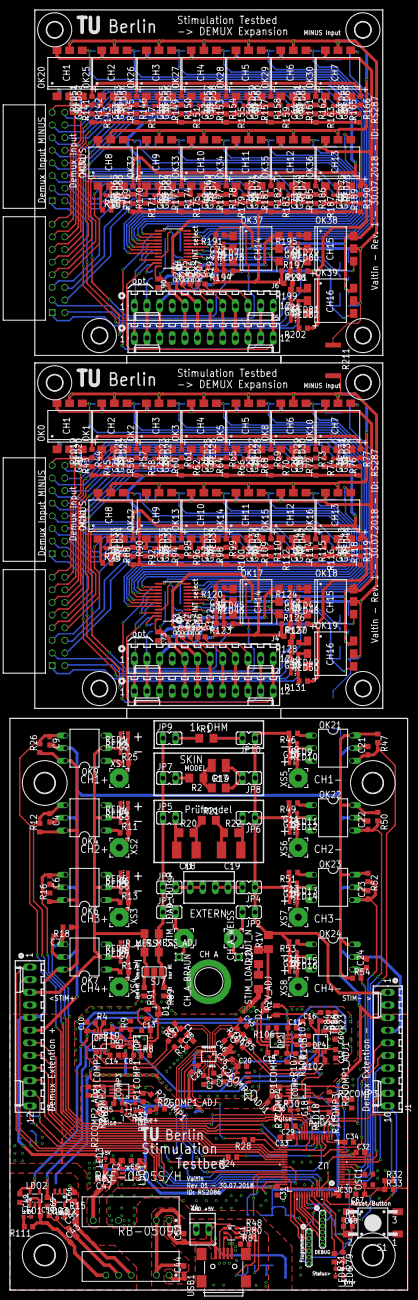
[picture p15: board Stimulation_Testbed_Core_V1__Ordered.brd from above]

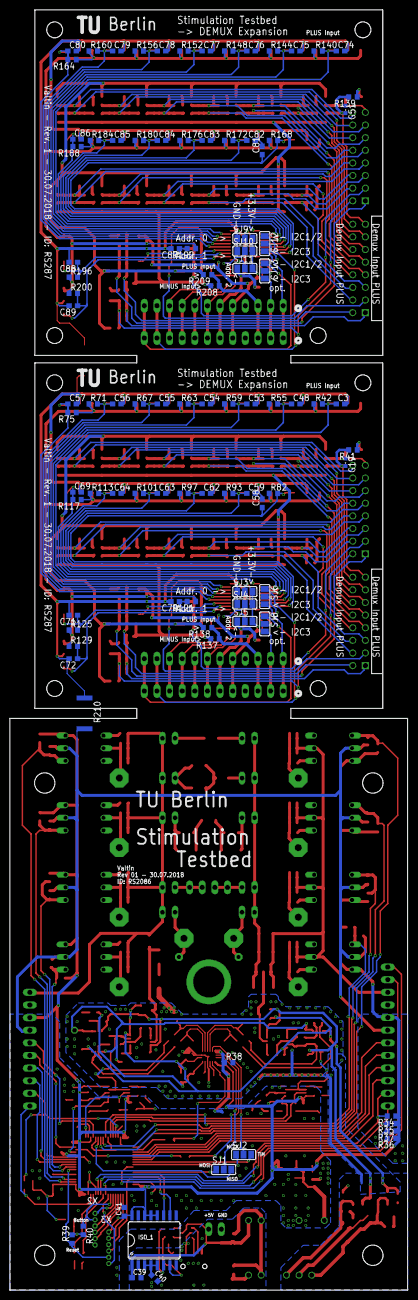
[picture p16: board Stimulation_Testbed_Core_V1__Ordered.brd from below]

Board: 2 copper layers, 80.0 x 257.5 mm, 613 parts (96 on the bottom side), 311 nets.

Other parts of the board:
U$1, U$2, U$3, U$4: 4,1
U$5, U$6, U$7, U$8, U$9, U$10, U$11, U$12: 3,2

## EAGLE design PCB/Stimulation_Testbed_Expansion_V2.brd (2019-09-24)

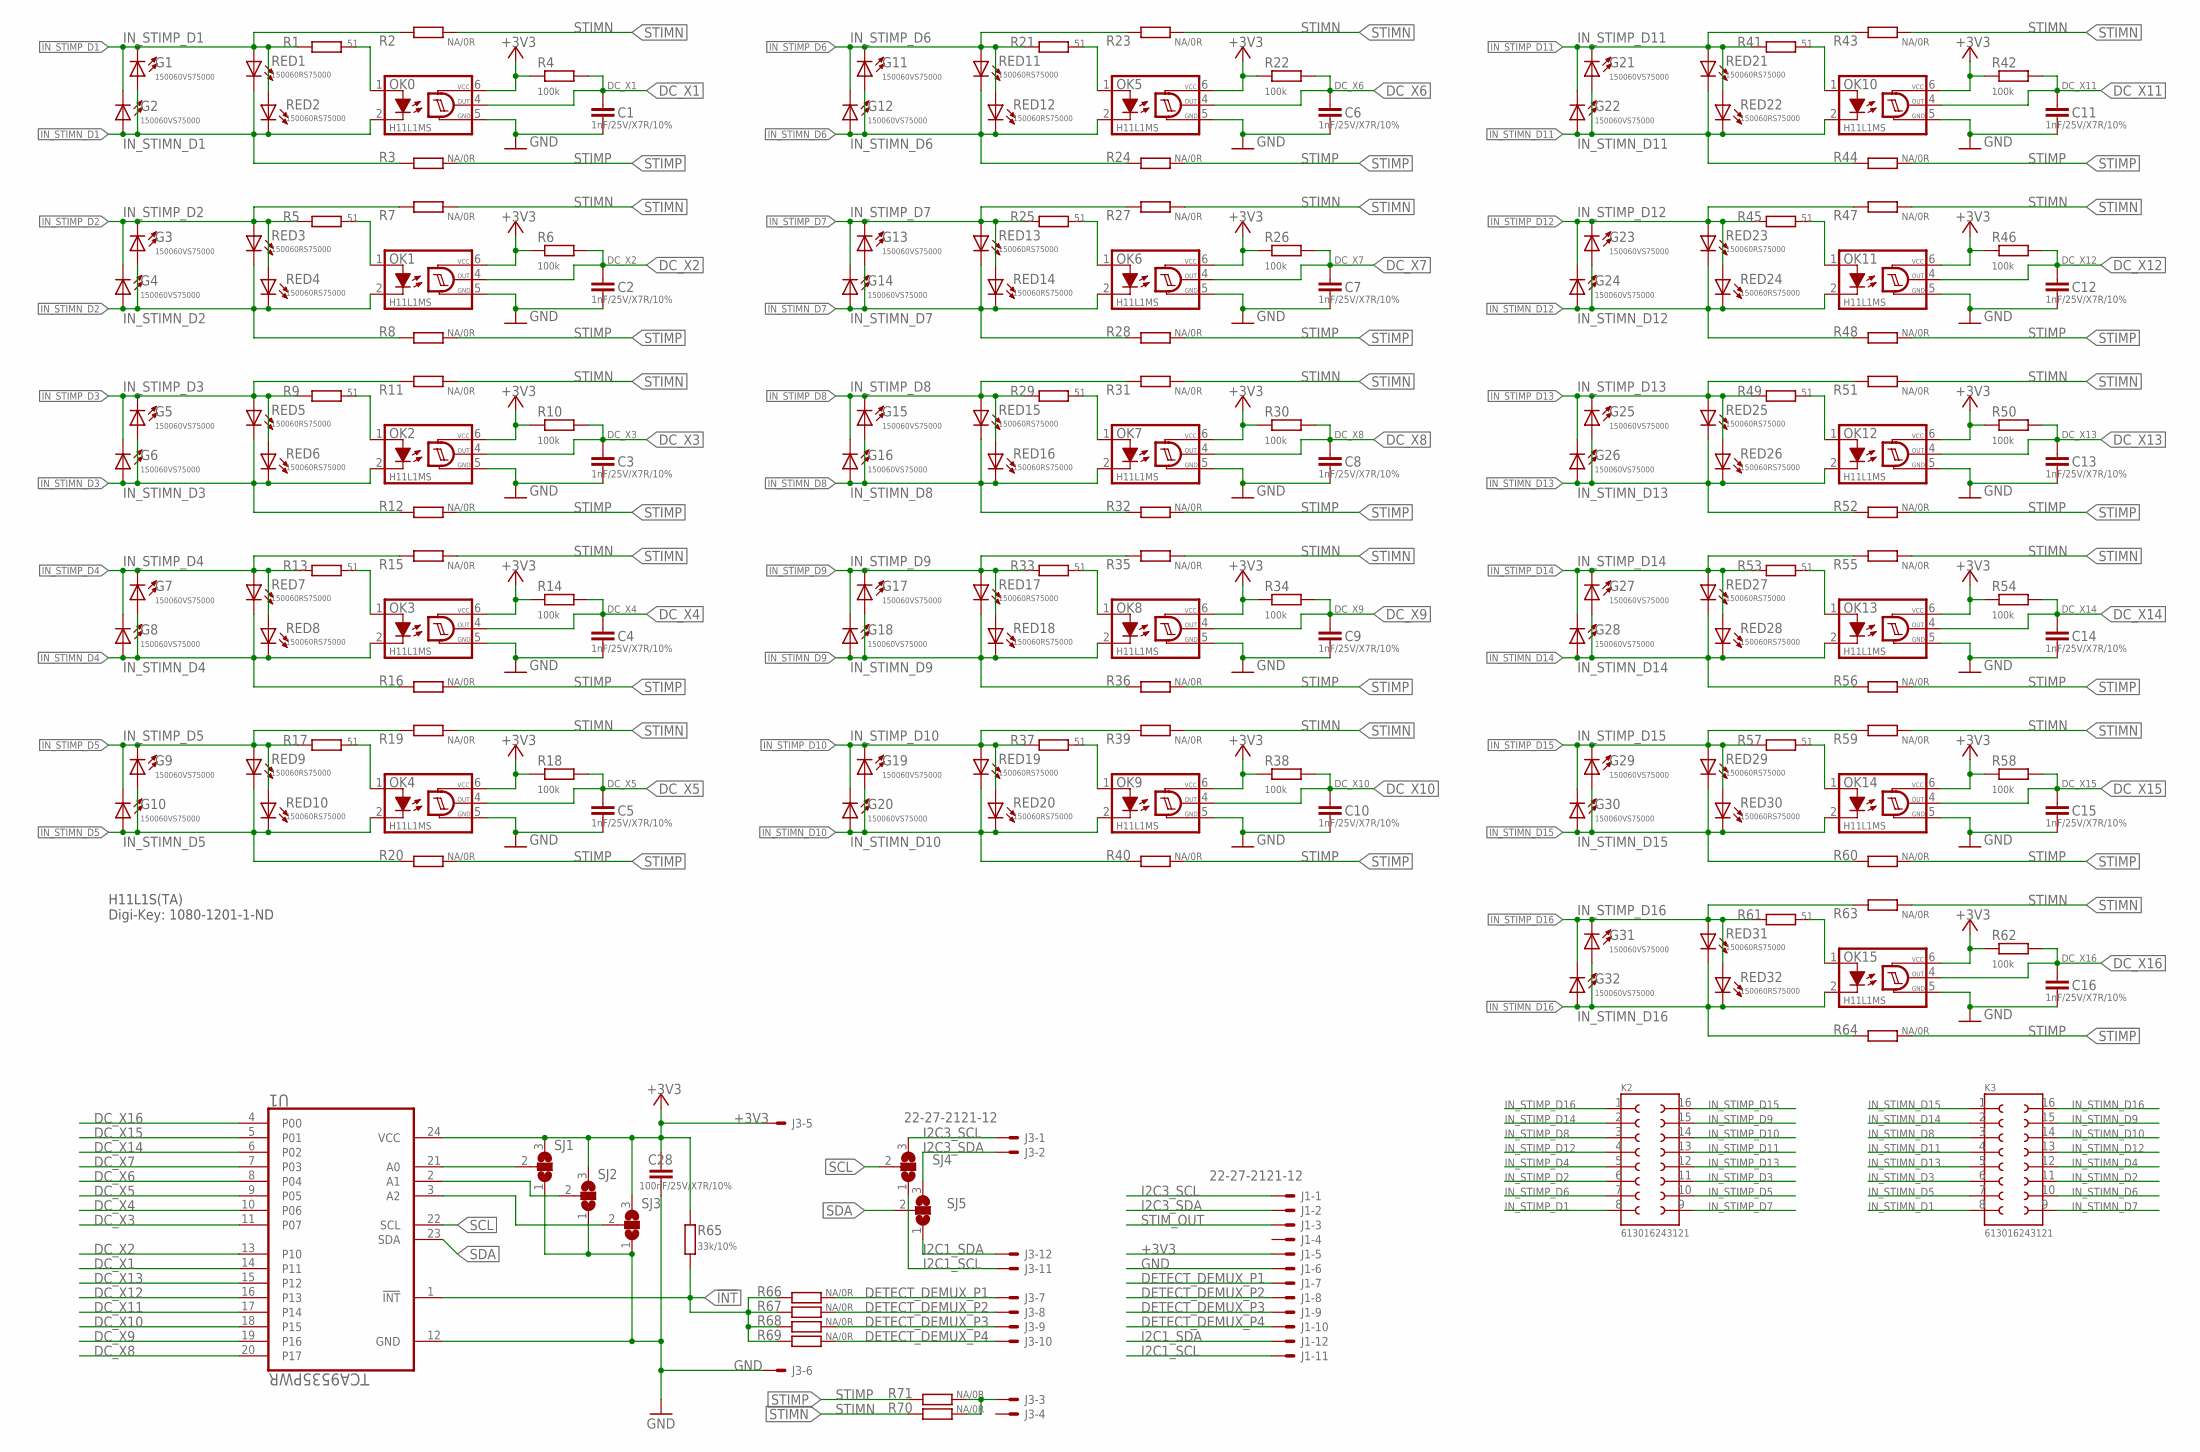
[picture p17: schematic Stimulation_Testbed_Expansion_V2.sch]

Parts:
C1, C2, C3, C4, C5, C6, C7, C8, C9, C10, C11, C12, C13, C14, C15, C16: 1nF/25V/X7R/10%; C0603
C28: 100nF/25V/X7R/10%; C0603K
G1, G2, G3, G4, G5, G6, G7, G8, G9, G10, G11, G12, G13, G14, G15, G16, G17, G18, G19, G20, G21, G22, G23, G24, G25, G26, G27, G28, G29, G30, G31, G32: 150060VS75000; CHIPLED_0603
J1, J3: 22-27-2121-12; 6410-12
K2, K3: 613016243121
OK0, OK1, OK2, OK3, OK4, OK5, OK6, OK7, OK8, OK9, OK10, OK11, OK12, OK13, OK14, OK15: H11L1MS; DIL6-SMD
R1, R5, R9, R13, R17, R21, R25, R29, R33, R37, R41, R45, R49, R53, R57, R61: 51; R0603
R2, R3, R7, R8, R11, R12, R15, R16, R19, R20, R23, R24, R27, R28, R31, R32, R35, R36, R39, R40, R43, R44, R47, R48, R51, R52, R55, R56, R59, R60, R63, R64, R66, R67, R68, R69, R70, R71: NA/0R; R0603
R4, R6, R10, R14, R18, R22, R26, R30, R34, R38, R42, R46, R50, R54, R58, R62: 100k; R0603
R65: 33k/10%; R0603
RED1, RED2, RED3, RED4, RED5, RED6, RED7, RED8, RED9, RED10, RED11, RED12, RED13, RED14, RED15, RED16, RED17, RED18, RED19, RED20, RED21, RED22, RED23, RED24, RED25, RED26, RED27, RED28, RED29, RED30, RED31, RED32: 150060RS75000; CHIP-LED0603
SJ1, SJ2, SJ3, SJ4, SJ5: SJ2W; SJ_2
U1: TCA9535PWR; SOP65P640X120-24N

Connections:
!INT: R65.1, R66.2, R67.2, R68.2, R69.2, U1.1 (!INT)
+3V3: C28.1, J1.5, J3.5, OK0.6 (VCC), OK1.6 (VCC), OK2.6 (VCC), OK3.6 (VCC), OK4.6 (VCC), OK5.6 (VCC), OK6.6 (VCC), OK7.6 (VCC), OK8.6 (VCC), OK9.6 (VCC), OK10.6 (VCC), OK11.6 (VCC), OK12.6 (VCC), OK13.6 (VCC), OK14.6 (VCC), OK15.6 (VCC), R4.1, R6.1, R10.1, R14.1, R18.1, R22.1, R26.1, R30.1, R34.1, R38.1, R42.1, R46.1, R50.1, R54.1, R58.1, R62.1, R65.2, SJ1.3, SJ2.3, SJ3.3, U1.24 (VCC)
DC_X1: C1.1, OK0.4 (OUT), R4.2, U1.14 (P11)
DC_X2: C2.1, OK1.4 (OUT), R6.2, U1.13 (P10)
DC_X3: C3.1, OK2.4 (OUT), R10.2, U1.11 (P07)
DC_X4: C4.1, OK3.4 (OUT), R14.2, U1.10 (P06)
DC_X5: C5.1, OK4.4 (OUT), R18.2, U1.9 (P05)
DC_X6: C6.1, OK5.4 (OUT), R22.2, U1.8 (P04)
DC_X7: C7.1, OK6.4 (OUT), R26.2, U1.7 (P03)
DC_X8: C8.1, OK7.4 (OUT), R30.2, U1.20 (P17)
DC_X9: C9.1, OK8.4 (OUT), R34.2, U1.19 (P16)
DC_X10: C10.1, OK9.4 (OUT), R38.2, U1.18 (P15)
DC_X11: C11.1, OK10.4 (OUT), R42.2, U1.17 (P14)
DC_X12: C12.1, OK11.4 (OUT), R46.2, U1.16 (P13)
DC_X13: C13.1, OK12.4 (OUT), R50.2, U1.15 (P12)
DC_X14: C14.1, OK13.4 (OUT), R54.2, U1.6 (P02)
DC_X15: C15.1, OK14.4 (OUT), R58.2, U1.5 (P01)
DC_X16: C16.1, OK15.4 (OUT), R62.2, U1.4 (P00)
DETECT_DEMUX_P1: J1.7, J3.7, R66.1
DETECT_DEMUX_P2: J1.8, J3.8, R67.1
DETECT_DEMUX_P3: J1.9, J3.9, R68.1
DETECT_DEMUX_P4: J1.10, J3.10, R69.1
GND: C1.2, C2.2, C3.2, C4.2, C5.2, C6.2, C7.2, C8.2, C9.2, C10.2, C11.2, C12.2, C13.2, C14.2, C15.2, C16.2, C28.2, J1.6, J3.6, OK0.5 (GND), OK1.5 (GND), OK2.5 (GND), OK3.5 (GND), OK4.5 (GND), OK5.5 (GND), OK6.5 (GND), OK7.5 (GND), OK8.5 (GND), OK9.5 (GND), OK10.5 (GND), OK11.5 (GND), OK12.5 (GND), OK13.5 (GND), OK14.5 (GND), OK15.5 (GND), SJ1.1, SJ2.1, SJ3.1, U1.12 (GND)
I2C1_SCL: J1.11, J3.11, SJ4.1
I2C1_SDA: J1.12, J3.12, SJ5.1
I2C3_SCL: J1.1, J3.1, SJ4.3
I2C3_SDA: J1.2, J3.2, SJ5.3
IN_STIMN_D1: G1.A, G2.A, K3.8, OK0.2 (C), R3.2, RED1.C, RED2.C
IN_STIMN_D2: G3.A, G4.A, K3.11, OK1.2 (C), R8.2, RED3.C, RED4.C
IN_STIMN_D3: G5.A, G6.A, K3.6, OK2.2 (C), R12.2, RED5.C, RED6.C
IN_STIMN_D4: G7.A, G8.A, K3.12, OK3.2 (C), R16.2, RED7.C, RED8.C
IN_STIMN_D5: G9.A, G10.A, K3.7, OK4.2 (C), R20.2, RED9.C, RED10.C
IN_STIMN_D6: G11.A, G12.A, K3.10, OK5.2 (C), R24.2, RED11.C, RED12.C
IN_STIMN_D7: G13.A, G14.A, K3.9, OK6.2 (C), R28.2, RED13.C, RED14.C
IN_STIMN_D8: G15.A, G16.A, K3.3, OK7.2 (C), R32.2, RED15.C, RED16.C
IN_STIMN_D9: G17.A, G18.A, K3.15, OK8.2 (C), R36.2, RED17.C, RED18.C
IN_STIMN_D10: G19.A, G20.A, K3.14, OK9.2 (C), R40.2, RED19.C, RED20.C
IN_STIMN_D11: G21.A, G22.A, K3.4, OK10.2 (C), R44.2, RED21.C, RED22.C
IN_STIMN_D12: G23.A, G24.A, K3.13, OK11.2 (C), R48.2, RED23.C, RED24.C
IN_STIMN_D13: G25.A, G26.A, K3.5, OK12.2 (C), R52.2, RED25.C, RED26.C
IN_STIMN_D14: G27.A, G28.A, K3.2, OK13.2 (C), R56.2, RED27.C, RED28.C
IN_STIMN_D15: G29.A, G30.A, K3.1, OK14.2 (C), R60.2, RED29.C, RED30.C
IN_STIMN_D16: G31.A, G32.A, K3.16, OK15.2 (C), R64.2, RED31.C, RED32.C
IN_STIMP_D1: G1.C, G2.C, K2.8, R1.2, R2.2, RED1.A, RED2.A
IN_STIMP_D2: G3.C, G4.C, K2.6, R5.2, R7.2, RED3.A, RED4.A
IN_STIMP_D3: G5.C, G6.C, K2.11, R9.2, R11.2, RED5.A, RED6.A
IN_STIMP_D4: G7.C, G8.C, K2.5, R13.2, R15.2, RED7.A, RED8.A
IN_STIMP_D5: G9.C, G10.C, K2.10, R17.2, R19.2, RED9.A, RED10.A
IN_STIMP_D6: G11.C, G12.C, K2.7, R21.2, R23.2, RED11.A, RED12.A
IN_STIMP_D7: G13.C, G14.C, K2.9, R25.2, R27.2, RED13.A, RED14.A
IN_STIMP_D8: G15.C, G16.C, K2.3, R29.2, R31.2, RED15.A, RED16.A
IN_STIMP_D9: G17.C, G18.C, K2.15, R33.2, R35.2, RED17.A, RED18.A
IN_STIMP_D10: G19.C, G20.C, K2.14, R37.2, R39.2, RED19.A, RED20.A
IN_STIMP_D11: G21.C, G22.C, K2.13, R41.2, R43.2, RED21.A, RED22.A
IN_STIMP_D12: G23.C, G24.C, K2.4, R45.2, R47.2, RED23.A, RED24.A
IN_STIMP_D13: G25.C, G26.C, K2.12, R49.2, R51.2, RED25.A, RED26.A
IN_STIMP_D14: G27.C, G28.C, K2.2, R53.2, R55.2, RED27.A, RED28.A
IN_STIMP_D15: G29.C, G30.C, K2.16, R57.2, R59.2, RED29.A, RED30.A
IN_STIMP_D16: G31.C, G32.C, K2.1, R61.2, R63.2, RED31.A, RED32.A
unnamed: OK1.1 (A), R5.1
unnamed: OK2.1 (A), R9.1
unnamed: OK3.1 (A), R13.1
unnamed: OK4.1 (A), R17.1
unnamed: OK5.1 (A), R21.1
unnamed: OK6.1 (A), R25.1
unnamed: OK7.1 (A), R29.1
unnamed: OK9.1 (A), R37.1
unnamed: OK8.1 (A), R33.1
unnamed: OK10.1 (A), R41.1
unnamed: OK11.1 (A), R45.1
unnamed: OK12.1 (A), R49.1
unnamed: OK13.1 (A), R53.1
unnamed: OK14.1 (A), R57.1
unnamed: OK15.1 (A), R61.1
unnamed: SJ1.2, U1.21 (A0)
unnamed: SJ2.2, U1.2 (A1)
unnamed: SJ3.2, U1.3 (A2)
unnamed: OK0.1 (A), R1.1
SCL: SJ4.2, U1.22 (SCL)
SDA: SJ5.2, U1.23 (SDA)
STIMN: R2.1, R7.1, R11.1, R15.1, R19.1, R23.1, R27.1, R31.1, R35.1, R39.1, R43.1, R47.1, R51.1, R55.1, R59.1, R63.1, R70.2
STIMP: R3.1, R8.1, R12.1, R16.1, R20.1, R24.1, R28.1, R32.1, R36.1, R40.1, R44.1, R48.1, R52.1, R56.1, R60.1, R64.1, R71.2
STIM_OUT: J1.3, J3.3, R70.1, R71.1

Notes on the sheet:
H11L1S(TA) Digi-Key: 1080-1201-1-ND



Board: 2 copper layers, 69.5 x 70.0 mm, 182 parts (41 on the bottom side), 83 nets.

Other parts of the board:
U$1, U$2, U$3, U$4: 3,2

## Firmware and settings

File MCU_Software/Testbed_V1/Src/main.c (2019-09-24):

/**
  ******************************************************************************
  * @file           : main.c
  * @brief          : Main program body
  ******************************************************************************
  * This notice applies to any and all portions of this file
  * that are not between comment pairs USER CODE BEGIN and
  * USER CODE END. Other portions of this file, whether 
  * inserted by the user or by software development tools
  * are owned by their respective copyright owners.
  *
  * Copyright (c) 2018 STMicroelectronics International N.V. 
  * All rights reserved.
  *
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
  ******************************************************************************
  */
/* Includes ------------------------------------------------------------------*/
#include "main.h"
#include "stm32f4xx_hal.h"
#include "dma.h"
#include "i2c.h"
#include "spi.h"
#include "tim.h"
#include "usart.h"
#include "usb_device.h"
#include "gpio.h"

/* USER CODE BEGIN Includes */
#include <string.h>
#include "GSBP_Basic_Config.h"
#include "GSBP_Basic.h"
#include "MCU_StateMachine.h"

#include "Testbed.h"
/* USER CODE END Includes */


/* USER CODE BEGIN PV */
uint8_t DoMeasurments;
uint16_t MeasTestDelay;
/* USER CODE END PV */

void SystemClock_Config(void);

/* USER CODE BEGIN PFP */

/* USER CODE END PFP */

/**
  * @brief  The application entry point.
  *
  * @retval None
  */
int main(void)
{
  /* MCU Configuration----------------------------------------------------------*/

  /* Reset of all peripherals, Initializes the Flash interface and the Systick. */
  HAL_Init();

  /* Configure the system clock */
  SystemClock_Config();

  /* Initialize all configured peripherals */
  MX_GPIO_Init();
  MX_DMA_Init();
  MX_I2C1_Init();
  MX_I2C2_Init();
  MX_I2C3_Init();
  MX_SPI1_Init();
  MX_SPI4_Init();
  MX_USART3_UART_Init();
  MX_USB_DEVICE_Init();
  MX_TIM8_Init();
  /* USER CODE BEGIN 2 */


  /*
   * ########################################################################################
   * MCU Initialization
   * ########################################################################################
   */
  MCU_StateChange(MCU_PreMCU_Init);
  MCU_State_LowFrequncyTimerCounter = HAL_GetTick() + MCU_STATEMACHINE__LOWFREQUENCY_TIMER_PERIOD_IN_MS;

  /* Initialize variables */
  // GPIOs

  // GSBP
  uint32_t GSBP_NextCall = HAL_GetTick() + GSBP_SETUP__CALLBACK_PERIOD_IN_MS;

  // TestBed
//  memset(&ISS_SensorGroups, 0, sizeof(ISS_SensorGroups_t));

  tca_device_t stimN1, stimP1, stimP2; // TODO: in init function integrieren für variables Setup ....
  tca9535_init_device(&stimN1, &hi2c2, 1, 0xFFFF, 0);
  tca9535_init_device(&stimP1, &hi2c1, 1, 0xFFFF, 0);
  tca9535_init_device(&stimP2, &hi2c3, 1, 0xFFFF, 0);

  /* wait a bit for the external parts to initialize */
  HAL_Delay(200);

  /* Initialize the GSBP communication system */
  GSBP_Init();

  /* send an DEBUG message about the system reset ... */
  sprintf((char*)GSBP_Handles.ACK.Data, "TestBed reseted -> timer = %lu", HAL_GetTick());
  GSBP_SendDebugPackage(&GSBP_USB, GSBP_Handles.ACK.Data);


  /* Start Normal Execution */
  MCU_StateChange(MCU_PreInit_Connected);

  /*
   * ########################################################################################
   * MCU infinite loop -> normal operations
   * ########################################################################################
   */

  /* USER CODE END 2 */

  /* Infinite loop */
  /* USER CODE BEGIN WHILE */
  while (1)
  {

  /* USER CODE END WHILE */

  /* USER CODE BEGIN 3 */

  	  /*
	   * ########################################################################################
	   *  run the low frequency callback
	   * ########################################################################################
	   */
	  if (HAL_GetTick() >= MCU_State_LowFrequncyTimerCounter) {
		  MCU_State_LowFrequncyTimerCounter += MCU_STATEMACHINE__LOWFREQUENCY_TIMER_PERIOD_IN_MS;
		  MCU_LowFrequencyTimerCallback();
	  }

  	  /*
	   * ########################################################################################
	   *  check for new packages every GSBP_CONFIG__CALLBACK_PERIOD_IN_MS ms
	   * ########################################################################################
	   */
	  if (HAL_GetTick() >= GSBP_NextCall) {
		  GSBP_NextCall += GSBP_SETUP__CALLBACK_PERIOD_IN_MS;
		  if (GSBP_EvaluatePackage(&GSBP_USB)){
			  // run the evaluate package again, after the current package is processed
			  GSBP_NextCall = HAL_GetTick();
		  }
	  }

	  /*
	   * ########################################################################################
	   *  execute the global state machine
	   * ########################################################################################
	   */
	  switch (MCU_State_CurrentState){
	  case MCU_PreInit_NotConnected:
		  // connection is via USB
	  	  MCU_StateChange(MCU_PreInit_Connected);
		  break;

	  case MCU_PreInit_Connected:
		  // wait for the INIT cmd
		  break;

	  case MCU_DoInit:{
		  // initialise the system
		  // get the init settings struct

		  // initialize the TestBed
		  testbed_init( (testbed_initCmd_t*)GSBP_Handles.CMD.Data, (testbed_initAck_t*)GSBP_Handles.ACK.Data);

		  // send Ack
		  GSBP_Handles.ACK.CommandID = InitACK;
		  GSBP_Handles.ACK.DataSize  = sizeof(testbed_initAck_t);
		  GSBP_SendPackage(GSBP_Handles.DefaultHandle, &(GSBP_Handles.ACK));

		  // done -> goto PostInit
		  HAL_Delay(3);
		  MCU_StateChange(MCU_PostInit);
		  GSBP_NextCall = HAL_GetTick() + GSBP_SETUP__CALLBACK_PERIOD_MIN_IN_MS;
	  	  break; }

	  case MCU_PostInit:
		  // post initialization -> wait for the start measurement command
		  break;

	  case MCU_MeasurmentDoStart:{
		  // start the measurement
		   max1119x_startMeasurment(&testbed.maxAdcDevice);

		   testbed.keepAlive_packageCounter = HAL_GetTick() + TESTBED_ADC_NO_STIM_WAIT_TIME_MS;

		  // send Ack
		  GSBP_Handles.ACK.CommandID = StartMeasurmentACK;
		  GSBP_Handles.ACK.DataSize = 0;
		  GSBP_SendPackage(GSBP_Handles.DefaultHandle, &(GSBP_Handles.ACK));

		  // done
		  MCU_StateChange(MCU_MeasurmentActiv);
		  break;}

	  case MCU_MeasurmentActiv:
		  // get the data from all the discovered sensors and send it away

		  if (testbed.updateStimChannels){
			  testbed_saveChannelInfoStim_PositivAndNegative();
			  testbed.updateStimChannels = false;
		  }

		  if (testbed_sendAdcData_realData( &testbed.maxAdcDevice )) {
			  testbed.keepAlive_packageCounter = HAL_GetTick() + TESTBED_ADC_NO_STIM_WAIT_TIME_MS;
		  } else {
			  // send the dummy packet, to let the PC know, that we are still there
			  if (HAL_GetTick() >= testbed.keepAlive_packageCounter) {
				  HAL_GPIO_TogglePin(D1_GPIO_Port, D1_Pin);
				  if (testbed_sendAdcData_keepAlive( &testbed.maxAdcDevice )){
					  // increase the counter, if the dummy package was send successfully
					  testbed.keepAlive_packageCounter = HAL_GetTick() + TESTBED_ADC_NO_STIM_WAIT_TIME_MS;
				  }
			  }
		  }

		  // TODO

		  break;

	  case MCU_MeasurmentDoStop:
		  // stop sending normal measurement data
		  max1119x_stopMeasurment(&testbed.maxAdcDevice);

		  // send Ack
		  GSBP_Handles.ACK.CommandID = StopMeasurmentACK;
		  GSBP_Handles.ACK.DataSize = 0;
		  GSBP_SendPackage(GSBP_Handles.DefaultHandle, &(GSBP_Handles.ACK));
		  // done
		  MCU_StateChange(MCU_MeasurmentFinished);
		  break;

	  case MCU_MeasurmentFinished:
		  // normal measurement has stopped

		  // TODO

		  break;

	  case MCU_DoDeInit:
		  // DEinitialize the system

		  testbed_deInit();

		  // send Ack
		  GSBP_Handles.ACK.CommandID = DeInitACK;
		  GSBP_Handles.ACK.DataSize = 0;
		  GSBP_SendPackage(GSBP_Handles.DefaultHandle, &(GSBP_Handles.ACK));
		  // done

		  MCU_StateChange(MCU_PreInit_Connected);
		  break;
	  }


	  /*
	   * ########################################################################################
	   *  resent package if needed
	   * ########################################################################################
	   */
	  GSBP_ReSendPackages();




	  /*
	  		if (tca9535_read_inputs(&stimP, &input)){
	  			if (input != old_input){
	  				old_input = input;
	  				GSBP_SendDebugPackage(&GSBP_USB, "change detected\n");
	  			}
	  		} */
	  //HAL_Delay(10);
//	  HAL_GPIO_TogglePin(STATUS2_GPIO_Port, STATUS2_Pin);


  }
  /* USER CODE END 3 */

}

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


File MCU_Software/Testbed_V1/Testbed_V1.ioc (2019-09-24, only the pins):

Mcu.UserName=STM32F412RETx
PA0.GPIO_Label=Detect_V_P
PA0.Signal=GPXTI0
PA1.Signal=SPI4_MOSI
PA10.Signal=SPI5_MOSI
PA11.Signal=USB_OTG_FS_DM
PA12.Signal=USB_OTG_FS_DP
PA13.Signal=SYS_JTMS-SWDIO
PA14.Signal=SYS_JTCK-SWCLK
PA15.GPIO_Label=LED_Status
PA15.Signal=GPIO_Output
PA2.GPIO_Label=DD_N2
PA2.Signal=GPIO_Input
PA3.GPIO_Label=Detect_V_N
PA3.Signal=GPXTI3
PA4.GPIO_Label=DD_N1
PA4.Signal=GPIO_Input
PA5.Signal=SPI1_SCK
PA6.Signal=SPI1_MISO
PA7.GPIO_Label=SC_P2
PA7.Signal=GPIO_Input
PA8.Signal=I2C3_SCL
PB0.Signal=SPI5_SCK
PB1.GPIO_Label=Detect_I_P
PB1.Signal=GPXTI1
PB10.Signal=I2C2_SCL
PB12.GPIO_Label=SC_P1
PB12.Signal=GPIO_Input
PB13.Signal=SPI4_SCK
PB14.GPIO_Label=DD_P1
PB14.Signal=GPIO_Input
PB15.GPIO_Label=DD_P2
PB15.Signal=GPIO_Input
PB2.GPIO_Label=Detect_I_N
PB2.Signal=GPXTI2
PB3.Signal=SYS_JTDO-SWO
PB4.Signal=I2C3_SDA
PB5.Signal=SPI1_MOSI
PB6.Signal=I2C1_SCL
PB7.Signal=I2C1_SDA
PB8.GPIO_Label=LED_Error
PB8.Signal=GPIO_Output
PB9.Signal=I2C2_SDA
PC0.GPIO_Label=SC_N3
PC0.Signal=GPIO_Input
PC1.GPIO_Label=SC_N4
PC1.Signal=GPIO_Input
PC10.Signal=USART3_TX
PC11.Signal=USART3_RX
PC12.GPIO_Label=D1
PC12.Signal=GPIO_Output
PC13.GPIO_Label=SC_N1
PC13.Signal=GPIO_Input
PC14-OSC32_IN.GPIO_Label=SC_N2
PC14-OSC32_IN.Signal=GPIO_Input
PC2.GPIO_Label=DD_N4
PC2.Signal=GPIO_Input
PC3.GPIO_Label=DD_N3
PC3.Signal=GPIO_Input
PC4.GPIO_Label=SC_P3
PC4.Signal=GPIO_Input
PC5.GPIO_Label=SC_P4
PC5.Signal=GPIO_Input
PC6.GPIO_Label=DD_P3
PC6.Signal=GPIO_Input
PC7.GPIO_Label=DD_P4
PC7.Signal=GPIO_Input
PC8.Signal=S_TIM8_CH3
PD2.GPIO_Label=D2
PD2.Signal=GPIO_Output

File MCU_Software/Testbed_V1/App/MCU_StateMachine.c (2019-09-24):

/*
 * MCU_StateMachine.c
 *
 *  Created on: 12.01.2016
 *      Author: valtin
 */

#include "MCU_StateMachine.h"

#ifndef APP_GSBP_BASIC_CONFIG_H_
	#include "GSBP_Basic_Config.h"
	#include "GSBP_Basic.h"
#endif

#ifndef set_StateLED_ON
	#define set_StateLED_ON()
	#define set_StateLED_OFF()
#endif

#ifndef APP_MCU_ERRORHANDLER_H_
    #define set_WarnLED_ON()
    #define set_WarnLED_OFF()
    #define set_ErrorLED_ON()
    #define set_ErrorLED_OFF()
	#define E_MCU_State_UnknowState		15
#endif

#ifndef APP_BATTERYMONITORING_H_
#define set_BatteryWeakLED_OFF()
#endif

// Variables
volatile uint8_t MCU_State_LED_TimeOff = 3;
volatile uint8_t MCU_State_LED_TimeOn  = 255;
volatile uint8_t MCU_State_LED_TimeCounter = 0;

uint32_t MCU_State_LowFrequncyTimerCounter = 0;
volatile uint8_t  MCU_State_CurrentState = MCU_PreMCU_Init;
volatile uint8_t  MCU_State_LastState    = MCU_PreMCU_Init;
volatile uint16_t MCU_State_SubSystemStates = MCU_SSS_default;
volatile uint8_t  MCU_State_EventType = 0;
// Functions

void MCU_EventState( uint8_t EventType )
{
	MCU_State_LastState = MCU_State_CurrentState;
	MCU_State_EventType = EventType;
	MCU_State_CurrentState = MCU_RunEventState;
}

/* MCU state machine */
void MCU_StateChange(mcu_States_t GotoState)
{
	MCU_State_LastState = MCU_State_CurrentState;
	switch (GotoState) {
	case MCU_PreMCU_Init:
		// time between end of STM32 HAL init and start of the endless loop -> normally very short
		MCU_State_CurrentState = MCU_PreMCU_Init;
		set_StateLED_OFF();
		set_WarnLED_OFF();
		set_ErrorLED_OFF();
		// indicate the current state
		set_StateLED_ON();
		MCU_State_SubSystemStates |= MCU_SSS_StatusLED_isOn;
		// turn the LED on as long as possible
		MCU_State_LED_TimeOn  = 255;
		MCU_State_LED_TimeOff = 1;
		break;
	case MCU_PreInit_NotConnected:
		// the MCU is in the endless loop but no connection is currently established (UART/USB/BT ...)
		MCU_State_CurrentState = MCU_PreInit_NotConnected;
		// set the LED values for this state
		MCU_State_LED_TimeOn  = 3;
		MCU_State_LED_TimeOff = 3;
		break;
	case MCU_PreInit_Connected:
		// a connection is established (UART/USB/BT ...), so we can receive commands but did not receive the init command yet
		MCU_State_CurrentState = MCU_PreInit_Connected;
		// set the LED values for this state
		MCU_State_LED_TimeOn  = 2;
		MCU_State_LED_TimeOff = 8;
		break;

	case MCU_DoInit:
		// a connection is established (UART/USB/BT ...), and we receive the init command -> do the init
		MCU_State_CurrentState = MCU_DoInit;
		// set the LED values for this state
		MCU_State_LED_TimeOn  = 8;
		MCU_State_LED_TimeOff = 2;
		break;
	case MCU_PostInit:
		// a connection is established (UART/USB/BT ...),  we receive the init command and the init is done
		MCU_State_CurrentState = MCU_PostInit;
		// set the LED values for this state
		MCU_State_LED_TimeOn  = 8;
		MCU_State_LED_TimeOff = 8;
		break;

	case MCU_MeasurmentDoStart:
		// the system is initalized and the start command was received -> start the measurement
		MCU_State_CurrentState = MCU_MeasurmentDoStart;
		// set the LED values for this state
		MCU_State_LED_TimeOn  = 1;
		MCU_State_LED_TimeOff = 1;
		break;
	case MCU_MeasurmentActiv:
		// the system started to make measurements
		MCU_State_CurrentState = MCU_MeasurmentActiv;
		// set the LED values for this state
		MCU_State_LED_TimeOn  = 1;
		MCU_State_LED_TimeOff = 1;
		break;
	// task specific states



	case MCU_MeasurmentDoStop:
		// the system is measuring but received a stop command -> stop the measurements
		MCU_State_CurrentState = MCU_MeasurmentDoStop;
		// set the LED values for this state
		MCU_State_LED_TimeOn  = 1;
		MCU_State_LED_TimeOff = 1;
		break;
	case MCU_MeasurmentFinished:
		// the system stopped to make measurements
		MCU_State_CurrentState = MCU_MeasurmentFinished;
		// set the LED values for this state
		MCU_State_LED_TimeOn  = 8;
		MCU_State_LED_TimeOff = 8;
		break;

	case MCU_DoDeInit:
		// the system is initialized but everything should be reseted -> deinitialise
		MCU_State_CurrentState = MCU_DoDeInit;
		// set the LED values for this state
		MCU_State_LED_TimeOn  = 8;
		MCU_State_LED_TimeOff = 2;
		break;

    // special states
	case MCU_PreSleep:
		// Todo
		break;

	case MCU_PostSleep:
		// Todo
		break;

	case MCU_UnrecoverableError:
		// an unrecoverable error occurred -> project specific implementation -> TODO
		// do not change the LED timer values, so you can see, in which state the error occurred
		break;
	case MCU_Reset:
		// software reset
		NVIC_SystemReset();
		break;
	case MCU_Shutdown:
		// shut down the MCU done to low battery
		if (GSBP_Handles.ActiveHandles > 0){
			GSBP_SendStatus(GSBP_Handles.DefaultHandle);
		}
		// turn of the LEDs
		MCU_State_LED_TimeOn  = 0;
		MCU_State_LED_TimeOff = 0;
		set_StateLED_OFF();
		set_WarnLED_OFF();
		set_ErrorLED_OFF();
		set_BatteryWeakLED_OFF();
		HAL_Delay(100);
		// stop the MCU
		HAL_PWR_EnterSTOPMode(PWR_LOWPOWERREGULATOR_ON, PWR_STOPENTRY_WFE);
		break;
	default:
		// send an error message to the PC if a connection was found
		if (GSBP_Handles.ActiveHandles > 0) {
			GSBP_SendError(GSBP_Handles.DefaultHandle, E_MCU_State_UnknowState);
		}
		// leaf the state as it is
	}
}


void MCU_StatusCallback(void)
{
	// signal the state with the state LED
	MCU_State_LED_TimeCounter++;
	if (MCU_State_SubSystemStates & MCU_SSS_StatusLED_isOn){
		// LED is on -> shut it down
		if (MCU_State_LED_TimeCounter >= MCU_State_LED_TimeOn){
			// reset the counter
			MCU_State_LED_TimeCounter = 0;
			// set the state LED to OFF
			set_StateLED_OFF();
			// update the subsystem state
			MCU_State_SubSystemStates &= ~(MCU_SSS_StatusLED_isOn);
		}
	}
	if (!(MCU_State_SubSystemStates & MCU_SSS_StatusLED_isOn)){
		// LED is off -> turn it on
		if ( (MCU_State_LED_TimeCounter >= MCU_State_LED_TimeOff) && (MCU_State_LED_TimeOn > 0) ){
			// reset the counter
			MCU_State_LED_TimeCounter = 0;
			// set the state LED to on
			set_StateLED_ON();
			// update the subsystem state
			MCU_State_SubSystemStates |= MCU_SSS_StatusLED_isOn;
		}
	}

	// automated state change
/*	switch (MCU_State_CurrentState) {
	case MCU_PreInit_NotConnected:
		if (GSBP_Handles.InterfacesEnabled != GSBP_NoInterface){
			MCU_StateChange(MCU_PreInit_Connected);		}
		break;
	case MCU_PreInit_Connected:
		if (GSBP_Handles.InterfacesEnabled == GSBP_NoInterface){
			MCU_StateChange(MCU_PreInit_NotConnected);		}
		break;
	}
*/
}
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

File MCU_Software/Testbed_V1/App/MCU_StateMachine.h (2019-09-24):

/*
 * MCU_States.h
 *
 *  Created on: 12.01.2016
 *      Author: valtin
 */

#ifndef APP_MCU_STATEMACHINE_H_
#define APP_MCU_STATEMACHINE_H_

#ifdef __cplusplus
 extern "C" {
#endif

#include "main.h"
#include "stm32f4xx_hal.h"
#include "GSBP_Basic_Config.h"
//#include "MCU_ErrorHandler.h"
//#include "MCU_BatteryMonitoring.h"
// Definitions

#define MCU_STATEMACHINE__LOWFREQUENCY_TIMER_PERIOD_IN_MS	100

// Declarations


typedef enum {
	// standard states
	MCU_PreMCU_Init				= 0,
	MCU_PreInit_NotConnected	= 5,
	MCU_PreInit_Connected		= 10,
	MCU_DoInit					= 13,
	MCU_PostInit				= 15,
	MCU_MeasurmentDoStart		= 50,
	MCU_MeasurmentActiv			= 53,
	MCU_MeasurmentDoStop		= 55,
	MCU_MeasurmentFinished		= 60,
	MCU_DoDeInit				= 180,
	// task specific states


	// special states
	MCU_PreSleep				= 200,
	MCU_PostSleep				= 201,
	MCU_UnrecoverableError		= 210,
	MCU_Reset					= 240,
	MCU_Shutdown				= 250,
	MCU_RunEventState			= 255
} mcu_States_t;

typedef enum {
	MCU_SSS_default				= 0b0000000000000000,
	MCU_SSS_StatusLED_isOn		= 0b0000000000000001,
	MCU_SSS_BatteryWeak			= 0b0000000000000010,
	MCU_SSS_MeasurmentActive	= 0b0000000000000100,
	MCU_SSS_IMUDATA__DATAREADY  = 0b1000000000000000,
	// task specific implementation
} mcu_SubSystemStates_t;

typedef enum {
    UART_InitError      				= 1,
    UART_ReceiveError   				= 2,
    UART_TransmitError  				= 3,
	UART_HandleError    				= 4,
	GSBP_InterfaceError					= 10,
	MCU_State_UnknowState				= 100,
	BatteryMonitoring__ADC_InitError    = 110,
    Timer_InitError     				= 120,
} mcu_ErrorTyp_t;

// Variables
extern uint32_t MCU_State_LowFrequncyTimerCounter;
extern volatile uint8_t  MCU_State_CurrentState;
extern volatile uint8_t  MCU_State_LastState;
extern volatile uint16_t MCU_State_SubSystemStates;
extern GSBP_HandlesList_t GSBP_Handles;

// Functions
void    MCU_StateChange(mcu_States_t GotoState);
void    MCU_StatusCallback(void);
uint8_t MCU_GetStatusInformation(uint8_t *Data);

void	MCU_LowFrequencyTimerCallback(void);

#ifdef __cplusplus
 }
#endif

#endif /* APP_MCU_STATEMACHINE_H_ */

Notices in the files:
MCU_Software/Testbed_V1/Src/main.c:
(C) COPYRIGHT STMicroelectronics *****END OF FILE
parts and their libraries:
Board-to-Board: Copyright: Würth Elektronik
